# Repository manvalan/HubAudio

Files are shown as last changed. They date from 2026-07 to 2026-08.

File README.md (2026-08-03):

# HubAudio

## Professional Embedded Audio Platform

HubAudio is a modular embedded audio platform designed around a clear separation of hardware domains:

- System control
- Audio processing
- Digital radio
- Wireless audio
- Clock management
- Power management

The primary design objective is maintainability.

The architecture follows the principle:

> Code and hardware design must fit in the engineer's head.

Complexity is introduced only when it provides a measurable improvement in reliability, flexibility or performance.

---

# Project Goals

HubAudio is intended to provide:

- High quality digital audio routing
- Multiple audio sources and destinations
- Expandable DSP processing
- Robust embedded operation
- Professional PCB architecture
- Long-term maintainability

---

# Core Architecture

## Main Domains

                SYSTEM DOMAIN

                ESP32-S3
                   |
          Control / Network / UI
                   |
                   |
            AUDIO CONTROL BUS

                AUDIO DOMAIN

               ADAU1467

    +-------------+-------------+
    |             |             |
  I2S          SPDIF        Bluetooth
    |             |             |
Si4684        IO Codec      BT Module
 Radio

---

# Hardware Philosophy

The system is divided into independent domains:

## System Domain

Responsible for:

- Connectivity
- User interface
- Configuration
- Network services
- OTA updates

Main component:

- ESP32-S3

## Audio Domain

Responsible for:

- Routing
- DSP processing
- Mixing
- Sample rate management

Main component:

- Analog Devices ADAU1467

## RF Domain

Responsible for:

- Digital radio reception
- Wireless communication

## Power Domain

Responsible for:

- Battery operation
- USB power
- Voltage regulation
- Monitoring

---

# Repository Structure

HubAudio/

├── docs/
│
├── hardware/
│
├── firmware/
│
├── simulation/
│
├── research/
│
└── tools/

---

# Design Rules

1. Prefer simple architectures.
2. Avoid unnecessary abstraction.
3. Separate noisy and sensitive domains.
4. Document every architectural decision.
5. Choose components for lifecycle, not only price.

---

# Status

Architecture phase.

Hardware implementation follows documented decisions.

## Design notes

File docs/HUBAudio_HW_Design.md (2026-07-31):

# HubAudio
## Modular Network Audio Platform
### Hardware Architecture and Engineering Design Document

**Project:** HubAudio  
**Document:** Hardware Architecture Specification  
**Revision:** 0.1  
**Status:** Design Phase  
**Target MCU:** ESP32-S3  
**Architecture:** Modular Audio Processing Platform  

---

# 1. Introduction

HubAudio is a modular high-quality network audio platform designed around a central DSP audio architecture.

The goal is not to create a simple Internet radio, but a flexible audio processing system capable of integrating multiple digital audio sources:

- FM radio
- DAB/DAB+ radio
- Bluetooth audio
- Network streaming
- Future digital sources

All audio sources are converted into a common digital audio stream and processed by a dedicated DSP before being sent to the final audio output stage.

The core design philosophy is:

> Keep the audio path fully digital until the final DAC stage.

The system is designed as a professional embedded audio platform, with concepts derived from industrial and commercial audio products:

- modular hardware blocks
- independent firmware management
- device identification
- firmware update capability
- replaceable source modules
- DSP-based audio processing

---

# 2. Design Goals

## Primary objectives

The HubAudio platform shall provide:

- High quality audio processing
- Multiple independent audio sources
- Network connectivity
- Bluetooth integration
- Digital signal processing
- Expandability
- Long-term maintainability

## Audio sources

The initial supported sources are:

| Source | Device |
|-|-|
| FM/DAB+ Radio | Skyworks Si4684 |
| Bluetooth TX | FSC-BT1035 |
| Bluetooth RX | FSC-BT1026 or equivalent |
| Network Audio | ESP32-S3 |

---

# 3. System Overview

The system is composed of four main functional blocks:

                     HUBAUDIO

                     ESP32-S3
                        |
         System control / Network / MQTT
                        |
    +-------------------+-------------------+
    |                   |                   |
    |                   |                   |
 Si4684             BT RX Module        BT1035
FM/DAB+             A2DP Sink           A2DP Source
    |                   |                   |
    |                   |                   |
    +-------------------+-------------------+

                        |
                       I2S

                        |
                        |
                  ADAU1467 DSP

                        |
                        |
                     DAC Stage

                        |
                        |
                Power Amplifier

---

# 4. System Philosophy

## Modular approach

Each functional block is considered an independent subsystem.

Modules:
+-----------------------------+
| Audio Module |
| |
| Processing IC |
| EEPROM Identification |
| Firmware Storage |
| Local configuration |
| I2S Interface |
| Control Interface |
+-----------------------------+

Every module shall contain:

- hardware identification
- revision information
- serial number
- configuration data

The identification device is:

24AA025E48T-I/OT

which provides:

- EEPROM memory
- factory programmed MAC address
- unique identification

---

# 5. Global Architecture

## Control domain

The ESP32-S3 is the system controller.

Responsibilities:

- WiFi connection
- MQTT communication
- Web interface
- OTA updates
- module discovery
- configuration management
- power sequencing

The ESP32-S3 does NOT process the main audio stream.

Audio remains outside the MCU.

---

## Audio domain

The audio domain is controlled by:

ADAU1467

The DSP is the central audio router.

Responsibilities:

- equalization
- filters
- crossover
- volume control
- loudness
- audio routing
- room correction

---

# 6. Audio Data Flow

## Bluetooth reception

Example:

Smartphone

|

Bluetooth A2DP

|

BT RX Module

|

I2S

|

ADAU1467

|

DAC

|

Amplifier

---

## Bluetooth transmission

Example:

Radio / Streaming

   |

ADAU1467

   |

  I2S

   |

BT1035

   |

Bluetooth TX

   |

Headphones

---

## Radio reception

Antenna

|

Si4684

|

I2S

|

ADAU1467

|

DAC

---

# 7. Power Architecture

The system shall use separated power domains.

Recommended domains:

VIN

|

+----------------+
|
+-- Digital 3.3V
|
| ESP32-S3
| EEPROM
| Control IC
|
|
+-- Audio 3.3V
|
| ADAU1467
| Audio modules
|
|
+-- RF supply
Si4684
Bluetooth modules

Important:

RF and audio domains must be isolated from noisy digital switching sources.

---

# 8. Firmware Storage Concept

The system supports independent firmware storage.

Example:

ESP32 Flash

|
|
+-- HubAudio Firmware

SPI Flash

|
|
+-- Si4684 firmware

SPI Flash

|
|
+-- ADAU1467 DSP program

The ESP32-S3 manages:

- firmware verification
- checksum
- update
- programming sequence

---

# 9. Update Procedure

Firmware update sequence:

ESP32 receives firmware
Disable audio modules
Power down Si4684 / ADAU1467
Program external memory
Verify checksum
Restart module
Resume operation

This avoids requiring direct programming access during normal operation.

---

# 10. Hardware Design Rules

## Clocking

I2S requires careful definition:

Possible configurations:

### Option A

ADAU1467 as I2S master.

Advantages:

- single audio clock source
- better synchronization

### Option B

Source modules as masters.

Requires:

- clock switching
- sample rate management

Preferred:

ADAU1467 master.

---

# 11. Open Engineering Points

The following points require verification during schematic phase:

## I2S topology

Need to verify:

- master/slave capability of each module
- supported sample rates
- MCLK requirement

## Bluetooth Gateway Function

The system intentionally separates:

- Bluetooth RX
- Bluetooth TX

because simultaneous A2DP RX/TX operation on a single Bluetooth module is not guaranteed.

The chosen architecture is:

BT RX Module

BT1035 TX Module

ADAU1467 routing

This provides reliable simultaneous operation.

---
# 12. ESP32-S3 System Controller

## 12.1 Overview

The ESP32-S3 is the main system controller of HubAudio.

It is responsible for:

- system initialization
- network communication
- MQTT management
- Web interface
- OTA firmware updates
- module identification
- power management
- configuration storage
- communication with audio peripherals

The ESP32-S3 is NOT part of the main audio signal chain.

The audio stream shall never pass through the MCU.

---

# 12.2 ESP32-S3 Main Interfaces

The ESP32-S3 communicates with the audio modules using:

| Function | Interface |
|-|-|
| Si4684 control | SPI |
| ADAU1467 control | I2C/SPI |
| Bluetooth modules | UART |
| EEPROM identification | I2C |
| Audio control | GPIO |
| Power management | GPIO |

---

# 12.3 Recommended ESP32-S3 Connections

## Power Supply

ESP32-S3 requires:

- 3.3V regulated supply
- low noise supply
- adequate decoupling close to pins

Recommended:

3.3V

|
+---- 10uF
|
+---- 100nF
|
ESP32-S3 VDD

Important:

The ESP32-S3 has high current peaks during WiFi transmission.

The regulator must support:

- >500mA transient capability
- low output impedance

Recommended regulators:

- TPS62162
- AP63203
- similar low noise buck converters

---

# 12.4 Important GPIO Considerations

ESP32-S3 pins have boot functions.

Avoid using boot-sensitive pins for critical peripherals.

Important signals:

## EN

Chip enable:

EN

HIGH = normal operation
LOW = reset

Recommended:

- RC reset network
- external supervisor optional

---

## UART

Recommended:

ESP32-S3 TX
|
|
Module RX

ESP32-S3 RX
|
|
Module TX

Used for:

- Bluetooth configuration
- module diagnostics

---

## I2C Bus

Shared bus:

ESP32-S3

SDA
|
+---- 24AA025E48
|
+---- ADAU1467
|
+---- sensors / expansion

SCL
|
+---- devices

Recommended pull-ups:

Typically:

2.2k - 4.7k

depending on bus length.

---

# 12.5 ESP32-S3 Firmware Architecture

Software layers:

Application

|
|
HubAudio Manager

|
+----------------+
| |
Drivers Network

|
Hardware abstraction

|
ESP32 HAL

The MCU shall manage modules as independent devices.

Example:

detect modules

read EEPROM

load configuration

initialize devices

start audio routing

---

# 13. Skyworks Si4684 Radio Module

## 13.1 Overview

The Si4684 is the selected radio receiver IC.

Functions:

- FM receiver
- AM receiver
- DAB/DAB+
- RDS/RBDS
- digital audio output

The device is selected because it integrates:

- RF receiver
- digital demodulation
- audio processing
- DAB stack

The Si4684 is treated as a complete radio subsystem.

---

# 13.2 Si4684 System Architecture

Antenna

|

RF Matching

|

Si4684

|

Digital Audio I2S

|

ADAU1467

---

# 13.3 Si4684 Control Interface

The preferred interface:

SPI

Connections:

ESP32-S3 Si4684

SPI CLK -----------> SCLK

SPI MOSI ----------> SDIO

SPI CS ------------> CS

GPIO --------------> RESET

GPIO <-------------- IRQ

---

# 13.4 Important Si4684 Pins

## VDD

Requirements:

- clean 3.3V supply
- RF filtering required

Recommended:

3.3V

|
Ferrite bead

|

Si4684 VDD

|
100nF
1uF
10uF

The RF section is sensitive to noise.

---

## RESET

Active low.

Recommended:

ESP GPIO

|

RESET

|

10k pull-up

|

3.3V

The MCU must control reset during startup.

---

## IRQ

Interrupt output.

Used for:

- data ready
- command completion
- events

Connection:

Si4684 IRQ

|

ESP32 GPIO interrupt

---

# 13.5 Si4684 Audio Interface

Digital output:

Si4684

BCLK
|
LRCLK
|
DATA

|

ADAU1467

Preferred:

- 24 bit audio
- 48kHz sample rate

---

# 13.6 Si4684 Firmware Management

Important design issue:

The Si4684 requires firmware loading.

The architecture includes:

SPI Flash

|

Si4684 firmware

|

ESP32-S3 loader

Startup sequence:

Power ON

|

ESP32 starts

|

Keep Si4684 reset

|

Load firmware

|

Release RESET

|

Initialize radio

---

# 13.7 Si4684 PCB Recommendations

RF section:

Must be physically separated from:

- DC/DC converters
- digital switching
- WiFi antenna

Recommended PCB placement:

+--------------------------+

RF AREA

Antenna
Matching
Si4684

DIGITAL AREA

ESP32
DSP
Power

+--------------------------+

---

# 13.8 Si4684 Design Risks

## Firmware availability

The firmware is proprietary.

The project must consider:

- legal firmware distribution
- firmware update method
- version control

The binary firmware shall be stored separately from source code.

---

## RF layout

The PCB RF layout is critical.

Must follow:

- antenna impedance rules
- controlled impedance traces
- ground plane continuity

---

# 13.9 Si4684 Summary

Role:

FM/DAB radio source.

Interface:

SPI + I2S.

Connection:

ESP32-S3

SPI

Si4684

I2S

ADAU1467

The Si4684 is considered a replaceable radio module.

(Fine Parte 2)

---

# 14. Analog Devices ADAU1467 Audio DSP

## 14.1 Overview

The ADAU1467 is the central digital audio processing unit of HubAudio.

It belongs to the Analog Devices SigmaDSP family and is designed for high quality audio processing applications.

The DSP is responsible for:

- audio routing
- equalization
- crossover filtering
- dynamic processing
- loudness compensation
- volume control
- delay management
- room correction algorithms

The ADAU1467 represents the central audio processing hub.

---

# 14.2 Audio Architecture

All digital audio sources converge into the ADAU1467.

                 AUDIO SOURCES

     Si4684          BT RX          Network Audio

        |              |                  |

        |              |                  |

        +--------------+------------------+

                       |

                      I2S

                       |

                  ADAU1467 DSP

                       |

          +------------+------------+

          |                         |

        DAC                    BT1035 TX

          |

     Power Amplifier

14.3 Why Use a Dedicated DSP

The ESP32-S3 is not suitable for high quality audio processing.

Reasons:

operating system tasks
WiFi interruptions
unpredictable timing
insufficient deterministic audio processing

The ADAU1467 provides:

deterministic processing
hardware audio engine
low latency
professional audio quality
14.4 ADAU1467 Main Interfaces

The DSP uses:

Function	Interface
Configuration	I2C / SPI
Program loading	SPI Flash
Audio input/output	I2S/TDM
Clock	MCLK
Reset	GPIO
14.5 ADAU1467 Power Supply

The ADAU1467 contains sensitive analog/digital sections.

Power domains must be carefully designed.

Recommended:

3.3V_AUDIO

       |

       +---- DSP Digital Supply

       |

       +---- DSP Analog Supply

Important:

The DSP supply must be separated from:

ESP32 WiFi supply
DC/DC switching nodes
Bluetooth RF supply
14.6 Decoupling Requirements

Standard decoupling:

VDD

 |

100nF ceramic

 |

1uF ceramic

 |

10uF bulk

Additional filtering is recommended:

3.3V

 |

Ferrite bead

 |

ADAU1467 supply

The ferrite bead is particularly important because DSP noise can couple into the audio path.

14.7 ADAU1467 Configuration Interface

The ESP32-S3 controls the DSP.

Preferred:

I2C Control

Connection:

ESP32-S3             ADAU1467

SDA ---------------- SDA

SCL ---------------- SCL

Used for:

volume
routing
parameter updates
runtime control
14.8 DSP Program Memory

The ADAU1467 does not permanently store the DSP program internally.

External SPI memory is required.

Architecture:

ESP32-S3

    |

    |

SPI Flash

    |

    |

ADAU1467

Startup sequence:

Power ON

 |

ESP32 starts

 |

Program ADAU1467 memory

 |

Verify checksum

 |

Enable audio processing

14.9 SPI Flash Programming Strategy

The ESP32-S3 shall be able to:

erase DSP memory
program new firmware
verify CRC
restore previous version

Possible update procedure:

Receive DSP image

        |

Disable ADAU1467

        |

Program SPI Flash

        |

Verify

        |

Restart DSP

This allows field firmware updates.

14.10 Audio Interface (I2S)

The ADAU1467 is the preferred audio clock master.

Recommended architecture:

                ADAU1467

                    |

          BCLK / LRCLK / MCLK

                    |

        +-----------+-----------+

        |                       |

     Si4684                 BT Modules

Advantages:

single clock domain
no asynchronous sample conversion
better audio stability
14.11 I2S Signals

Typical signals:

BCLK

Bit clock.

Carries the individual audio bits.

LRCLK

Word select clock.

Defines:

left channel
right channel
DATA

Serial audio data.

MCLK

Master clock.

Important:

Some audio devices require MCLK.

Others generate internal clocks.

Each module must be verified.

14.12 I2S Routing Problems

A critical design issue:

Multiple I2S sources cannot directly drive the same bus.

Wrong:

Si4684

     |

     +------------ I2S ------------ ADAU1467

BT RX

     |

     +------------ I2S ------------

Two masters conflict.

Correct:

Source modules

      |

      |

Dedicated inputs

      |

      |

ADAU1467

The ADAU1467 must provide multiple serial ports.

14.13 ADAU1467 Audio Ports

The DSP provides multiple serial interfaces.

Suggested allocation:

Port	Device
Serial Input 0	Si4684
Serial Input 1	BT RX
Serial Output 0	DAC
Serial Output 1	BT1035

This avoids external I2S multiplexers.

14.14 DSP Software

The SigmaDSP project shall contain:

routing matrix
equalizer
volume control
filters
crossover
protection algorithms

Example:

Input Selector

       |

Equalizer

       |

Dynamic Processing

       |

Volume

       |

Output Router

14.15 ADAU1467 Reset

Reset must be controlled.

Recommended:

ESP32 GPIO

      |

RESET

      |

10k Pull-up

      |

3.3V

Startup:

Hold RESET LOW

       |

Configure clocks

       |

Release RESET

       |

Load DSP program

14.16 ADAU1467 PCB Placement

The DSP should be placed:

close to audio connectors
away from ESP32 antenna
away from DC/DC converters

Recommended:

+-----------------------------+

RF AREA

Bluetooth
Si4684

-----------------------------

AUDIO AREA

ADAU1467
DAC

-----------------------------

DIGITAL AREA

ESP32-S3
Power

+-----------------------------+

14.17 ADAU1467 Design Risks
Clock synchronization

Must verify:

MCLK requirement
sample frequency compatibility
master/slave configuration
Firmware dependency

DSP algorithm is stored externally.

Need:

version management
backup image
checksum
Noise coupling

Avoid:

digital return currents through analog ground
switching regulator near DSP
long I2S traces
14.18 ADAU1467 Summary

Role:

Central audio processing engine.

Connections:

ESP32-S3

  |

I2C/SPI

  |

ADAU1467

  |

I2S/TDM

  |

Audio modules

The ADAU1467 defines the professional audio capability of HubAudio.

---

# 15. Bluetooth Audio Subsystem

## 15.1 Architecture Decision

The HubAudio platform intentionally separates Bluetooth reception and transmission.

The reason is reliability.

A single Bluetooth audio module capable of simultaneously handling:

- A2DP Sink
- A2DP Source
- independent Bluetooth links
- real-time audio routing

is not guaranteed in commercial modules.

Therefore the design uses two independent Bluetooth audio blocks.

Architecture:

             Bluetooth Subsystem

    Smartphone                 Headphones

         |                         ^

         |                         |

         v                         |

   BT RX MODULE              BT1035 TX

         |                         ^

         | I2S                     | I2S

         |                         |

         +-----------+-------------+

                     |

                  ADAU1467

Advantages:

- simultaneous operation
- independent firmware
- easier debugging
- modular replacement
- predictable audio routing

---

# 16. FSC-BT1035 Bluetooth Transmitter

## 16.1 Role in HubAudio

The FSC-BT1035 is used as Bluetooth Audio Transmitter.

Its function:

ADAU1467

|

I2S

|

FSC-BT1035

|

Bluetooth A2DP Source

|

Headphones / Speakers

---

# 16.2 Main Features

Typical capabilities:

- Bluetooth audio transmission
- A2DP Source
- AVRCP support
- digital audio interface
- UART configuration
- embedded antenna

The module handles:

- Bluetooth stack
- codec negotiation
- RF management

The ESP32-S3 does not process Bluetooth audio.

---

# 16.3 BT1035 Connections

Important signals:

## Power

3.3V

|

BT1035 VCC

The module requires:

- clean supply
- local decoupling
- RF isolation

Recommended:

3.3V

|

Ferrite bead

|

BT1035

|

100nF

|

10uF

---

## UART Control

Connection:

ESP32-S3 BT1035

TX ---------------- RX

RX ---------------- TX

Used for:

- configuration
- status
- debugging

---

## I2S Audio Input

The BT1035 receives digital audio from the DSP.

ADAU1467 BT1035

BCLK -------------- BCLK

LRCLK ------------- LRCLK

DATA -------------- DATA IN

Important:

The clock master/slave configuration must be verified.

Preferred:

ADAU1467 = clock master.

---

# 16.4 BT1035 Firmware Considerations

Commercial Bluetooth modules often contain vendor firmware.

Important:

Verify:

- A2DP Source enabled
- I2S input mode enabled
- codec selection
- sample rate support

The module configuration shall be stored separately from ESP32 firmware.

---

# 16.5 BT1035 Operating Modes

Normal operation:

Power ON

|

UART initialization

|

Configure audio interface

|

Start Bluetooth advertising

|

Connect headphones

|

Stream audio

---

# 17. Bluetooth RX Module

## 17.1 Requirements

The receiving module must provide:

Required:

- Bluetooth Classic
- A2DP Sink
- I2S output
- UART configuration

Optional:

- AVRCP
- BLE
- codec selection

---

# 17.2 Preferred Solution

A module based on:

- FSC-BT1026
- equivalent Bluetooth Audio Receiver

Architecture:

Smartphone

|

Bluetooth A2DP

|

BT RX Module

|

I2S

|

ADAU1467

---

# 17.3 BT RX Module Connections

## Power

Same philosophy:

3.3V

|

Filtering

|

BT RX Module

Bluetooth RF requires a clean supply.

---

## I2S Output

Connection:

BT RX ADAU1467

BCLK -----------> BCLK IN

LRCLK ----------> LRCLK IN

DATA -----------> DATA IN

---

## UART

Optional but recommended:

ESP32-S3 TX

 |

BT RX RX

ESP32-S3 RX

 |

BT RX TX

Used for:

- pairing control
- diagnostics
- configuration

---

# 17.4 Bluetooth RX Firmware Risks

The main risk is vendor configuration.

A module may support:

- A2DP Sink only

or:

- A2DP Sink + Source

The required mode must be confirmed before PCB release.

---

# 18. Alternative Bluetooth RX Using ESP32-WROOM-32

## 18.1 Overview

The ESP32-WROOM-32 contains Bluetooth Classic support.

Unlike ESP32-S3:

- Bluetooth Classic available
- A2DP Sink supported

Architecture:

Smartphone

|

Bluetooth A2DP

|

ESP32-WROOM-32

|

I2S

|

ADAU1467

---

# 18.2 Advantages

Advantages:

- complete firmware control
- open development environment
- easy debugging
- same ecosystem as ESP32-S3

---

# 18.3 Disadvantages

Compared with dedicated modules:

- more firmware work
- Bluetooth stack maintenance
- higher CPU load
- more software complexity

---

# 18.4 Recommended Use

ESP32-WROOM should be considered:

- development prototype
- experimental firmware
- future custom Bluetooth module

Not the first production choice.

---

# 19. Bluetooth Clock Management

Bluetooth audio introduces clock problems.

Different devices may have:

- different sample clocks
- different oscillator accuracy

The ADAU1467 should manage:

- routing
- resampling if required
- synchronization

Possible solutions:

## Solution A

All sources synchronized to DSP clock.

Preferred.

---

## Solution B

Asynchronous sample rate conversion.

Required if modules cannot operate as slaves.

---

# 20. Bluetooth PCB Layout

RF modules require:

- antenna clearance
- ground plane
- no copper under antenna area
- separation from switching regulators

Recommended:

+--------------------+

Bluetooth Antenna

 KEEP OUT AREA

Digital electronics

Power section

+--------------------+

---

# 21. Bluetooth Subsystem Summary

Final architecture:

             ESP32-S3

                |

      +---------+---------+

      |                   |

   BT RX              BT1035

 A2DP Sink          A2DP Source

      |                   |

      | I2S               | I2S

      +---------+---------+

                |

            ADAU1467

This provides:

- smartphone audio reception
- Bluetooth headphone transmission
- simultaneous operation
- modular replacement

---
# 22. Module Identification System

## 22.1 Purpose

HubAudio is designed as a modular platform.

Every external module must be automatically identifiable by the main controller.

The system uses:

24AA025E48T-I/OT

as module identification memory.

---

# 22.2 24AA025E48T Overview

The device provides:

- I2C EEPROM memory
- factory programmed unique MAC address
- unique module identification

The ESP32-S3 reads the EEPROM during startup.

---

# 22.3 EEPROM Connection

Typical connection:

ESP32-S3 24AA025E48T

3.3V ---------------- VCC

GND ----------------- GND

SDA ----------------- SDA

SCL ----------------- SCL

Required:

I2C pull-up resistors.

Typical value:

2.2k - 4.7k

depending on bus capacitance.

---

# 22.4 Module Identification Structure

Example:

EEPROM:

Address 00

Module Type

01 = Radio Si4684

02 = Bluetooth RX

03 = Bluetooth TX

04 = DSP

Address 10

Hardware Revision

Address 20

Serial Number

Address 30

Configuration Data

---

# 22.5 Startup Discovery

The ESP32-S3 performs:

Power ON

|

Initialize I2C

|

Scan module bus

|

Read EEPROM

|

Identify hardware

|

Load configuration

|

Initialize drivers

The firmware does not need to know the exact board revision.

---

# 23. External SPI Memories

## 23.1 Purpose

Several components require external firmware storage.

Examples:

- ADAU1467 DSP program
- Si4684 firmware
- future modules

---

# 23.2 General Architecture

ESP32-S3

|

SPI

|

External Flash

|

Target Device

The ESP32-S3 acts as programmer.

---

# 23.3 Firmware Update Procedure

General sequence:

Receive update package

    |

Validate checksum

    |

Disable target device

    |

Program Flash

    |

Verify

    |

Restart module

---

# 24. Power Architecture

## 24.1 Design Objective

The audio system contains:

- RF circuits
- digital processors
- sensitive analog sections

Power distribution is critical.

---

# 24.2 Recommended Power Domains

Main Input

  |

  +----------------+

  |

Digital 3.3V

  |

  + ESP32-S3

  + EEPROM

  |

  |

Audio 3.3V

  |

  + ADAU1467

  + DAC

  |

  |

RF 3.3V

  |

  + Si4684

  + Bluetooth

---

# 24.3 Separation Rules

Avoid:

- ESP32 WiFi current peaks disturbing audio
- DC/DC switching noise entering DSP supply
- RF noise coupling into analog paths

---

# 24.4 Recommended Filtering

For DSP:

3.3V

|

Ferrite bead

|

100nF

|

1uF

|

10uF

|

ADAU1467

For RF modules:

3.3V

|

Ferrite bead

|

RF module

---

# 24.5 Ground Strategy

Recommended:

Single PCB ground plane.

However:

Control return currents carefully.

Avoid:

- digital currents crossing analog audio paths
- switching regulator return under DSP

---

# 25. System Boot Sequence

Complete startup:

POWER ON

|

Power regulators stable

|

ESP32-S3 reset release

|

Read EEPROM modules

|

Keep audio devices disabled

|

Initialize Si4684

|

Initialize ADAU1467

|

Initialize Bluetooth modules

|

Configure audio routing

|

Enable audio outputs

---

# 26. Audio Routing Software Model

The firmware shall expose audio sources:

Example:

SOURCE_RADIO

SOURCE_BT_RX

SOURCE_NETWORK

SOURCE_EXTERNAL

The DSP routing layer decides:

Selected Source

   |

ADAU1467

   |

Outputs

---

# 27. PCB Placement Strategy

Recommended board organization:

+--------------------------------+

| |
| RF AREA |
| |
| Si4684 Bluetooth Modules |
| |

AUDIO AREA

ADAU1467 DAC

-------------------------------

DIGITAL AREA

ESP32-S3 Power

+--------------------------------+

---

# 28. PCB Critical Rules

## RF

Must verify:

- antenna clearance
- impedance control
- keep-out area
- connector placement

---

## I2S

Keep:

- short traces
- controlled routing
- common ground reference

Avoid:

- crossing noisy clocks

---

## SPI

For:

- Si4684
- firmware memories

Use:

- short traces
- avoid unnecessary vias

---

# 29. Initial Bill Of Materials (Architecture Level)

| Block | Component |
|-|-|
| Main MCU | ESP32-S3 |
| Radio | Si4684 |
| DSP | ADAU1467 |
| Bluetooth TX | FSC-BT1035 |
| Bluetooth RX | FSC-BT1026 or equivalent |
| Module ID | 24AA025E48T-I/OT |
| DSP memory | SPI Flash |
| Radio memory | SPI Flash |
| DAC | To be selected |
| Amplifier | To be selected |

---

# 30. Open Issues Before PCB Release

## Must verify

### ADAU1467

- exact DSP memory size
- SPI Flash type
- clock configuration
- serial port allocation

---

### Si4684

- firmware acquisition
- RF matching network
- antenna design

---

### Bluetooth

- BT1035 I2S mode
- BT RX module A2DP Sink capability
- codec support
- UART commands

---

### Power

- regulator selection
- current budget
- thermal analysis

---

# 31. Final Architecture

The final HubAudio platform:

                     ESP32-S3

                        |

    +-------------------+-------------------+

    |                   |                   |

  Si4684             BT RX              BT1035

 FM/DAB+           A2DP Sink          A2DP Source

    |                   |                   |

    +-------------------+-------------------+

                        |

                       I2S

                        |

                   ADAU1467

                        |

             +----------+----------+

             |                     |

            DAC              Bluetooth Output

             |

        Amplifier

---

# 32. Engineering Philosophy

HubAudio is designed as a scalable embedded audio platform.

The architecture follows these principles:

- digital audio path
- modular hardware
- replaceable subsystems
- independent firmware management
- explicit hardware identification
- professional DSP processing

The system can evolve without redesigning the complete platform.

---

# END OF DOCUMENT

Revision 0.1

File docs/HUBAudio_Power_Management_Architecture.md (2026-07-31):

# HubAudio
# Power Management Architecture

**Document:** Power Management Design Specification  
**Revision:** 0.1  
**Status:** Design Phase  

---

# 1. Overview

The HubAudio platform requires a sophisticated power management architecture.

The system combines:

- ESP32-S3 high performance MCU with WiFi
- ADAU1467 professional audio DSP
- Si4684 FM/DAB receiver
- Bluetooth audio transmitter
- Bluetooth audio receiver
- battery operation
- remote monitoring capability

The power system is therefore not considered a simple voltage regulator stage, but a complete energy management subsystem.

---

# 2. Design Philosophy

The selected architecture follows these principles:

- single intelligent PMIC
- integrated battery management
- multiple independent power rails
- I2C monitoring
- controlled power sequencing
- ability to disable unused subsystems
- separated digital and audio power domains

---

# 3. Selected Main PMIC

## Texas Instruments TPS65217CRSLR

The TPS65217 is selected as the main power management IC.

Reasons for selection:

- integrated Li-Ion battery charger
- power path management
- multiple switching regulators
- LDO outputs
- I2C configuration
- programmable sequencing
- fault monitoring

Although originally designed for embedded processor systems, its architecture is suitable for HubAudio due to the need for multiple controlled power domains.

---

# 4. Power Tree

Proposed architecture:

             USB-C / External Power

                     |

                     |

             TPS65217CRSLR

                     |

    +----------------+----------------+

    |                |                |

 DCDC1             DCDC2            DCDC3

    |                |                |

3.3V_DIGITAL 3.3V_AUDIO 5V

    |                |

    |                |

ESP32-S3 Audio/RF domain

                |

          Ferrite filtering

                |

    +-----------+-----------+

    |           |           |

ADAU1467    Si4684      Bluetooth

---

# 5. Power Domains

## 5.1 Digital Domain

Voltage:

3.3V_DIGITAL

Consumers:

- ESP32-S3
- EEPROM
- logic peripherals
- communication interfaces

Requirements:

- high transient capability
- low impedance supply

Main concern:

ESP32-S3 WiFi current peaks.

---

# 5.2 Audio / RF Domain

Voltage:

3.3V_AUDIO

Consumers:

- ADAU1467
- Si4684
- BT1035
- Bluetooth RX module

This rail must be isolated from digital noise.

Recommended:

3.3V_AUDIO

  |

ferrite bead

  |

audio devices

---

# 5.3 5V Domain

Possible consumers:

- DAC
- amplifier
- future peripherals

This rail is kept independent from sensitive audio electronics.

---

# 6. Battery Management

The TPS65217 provides:

- Li-Ion charging
- battery monitoring
- power path control
- protection mechanisms

Battery:

Single cell Li-Ion

3.7V nominal

4.2V charged

---

# 7. Power Monitoring

## 7.1 Decision

The TPS65217 already provides battery management.

An additional current monitor is not required for system operation.

However, HubAudio benefits from detailed subsystem monitoring.

A dedicated I2C power monitor is therefore added for the audio domain.

---

# 8. Selected Current Monitor

## Texas Instruments INA226

The INA226 is selected as the default power monitoring device.

Purpose:

Measure the audio subsystem consumption.

Monitored rail:

TPS65217

|

3.3V_AUDIO

|

INA226

|

ADAU1467
Si4684
Bluetooth

---

# 9. INA226 Functions

The INA226 provides:

- bus voltage measurement
- shunt voltage measurement
- current measurement
- power calculation
- I2C communication

The ESP32-S3 can periodically read:

Voltage

Current

Power

Example:

```json
{
 "audio_voltage":3.30,
 "audio_current":180,
 "audio_power":0.59
}

10. INA228 Evaluation

The INA228 has been evaluated as an alternative.

Advantages:

higher resolution ADC
higher precision
energy accumulation
advanced power analysis

Typical application:

laboratory measurements
industrial systems
precision battery analysis

For HubAudio:

Not selected as default.

Reason:

The additional precision is not necessary because:

battery management is already handled by TPS65217
audio subsystem consumption does not require laboratory accuracy
11. Future Compatibility

The PCB should allow optional replacement:

INA226 footprint compatible with INA228 evaluation.

Possible versions:

Standard
TPS65217
+
INA226

Engineering / Pro Version
TPS65217
+
INA228

12. I2C Monitoring Bus

The power monitoring devices share the system I2C bus.

Example:

ESP32-S3

 |

I2C

 +---- EEPROM

 |

 +---- ADAU1467

 |

 +---- INA226

 |

 +---- TPS65217

13. Power Sequencing

Startup sequence:

Battery connected

 |

TPS65217 initialization

 |

3.3V_DIGITAL enabled

 |

ESP32-S3 boot

 |

Module detection

 |

Enable audio domain

 |

Initialize DSP

 |

Enable RF modules

14. Controlled Shutdown

The ESP32-S3 can disable:

Bluetooth TX
Bluetooth RX
Si4684
ADAU1467

Example:

Standby:

ESP32-S3 ON

WiFi ON

Audio OFF

Radio OFF

Bluetooth OFF

15. PCB Layout Requirements

Critical:

Switching regulators

Keep away from:

ADAU1467
DAC
RF sections
Audio supply

Use:

short traces
filtering
dedicated return paths
Decoupling

Every IC requires local decoupling.

Additional filtering is required for:

DSP supply
RF supply
16. Final Decision

The HubAudio power architecture is:

TPS65217CRSLR

+

Separate audio power domain

+

INA226 monitoring

+

Optional INA228 upgrade

This provides:

professional power management
battery operation
remote diagnostics
future scalability
END DOCUMENT

---

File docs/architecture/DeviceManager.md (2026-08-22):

# HubAudio — MCP23S17 GPIO Distribution

**Progetto:** HubAudio  
**Revisione:** definitiva  
**Data:** 2026-08-22

---

## Distribuzione GPIO

| IC | PORTA | GPIO | Segnale | Direzione | Pull |
|---|---|---|---|---|---|
| U34 | A | GPA0 | `SI4684_RESET` | OUT | UP |
| U34 | A | GPA1 | `SI4684_SMODE` | OUT | - |
| U34 | A | GPA2 | `SI4684_ANT_SEL` | OUT | - |
| U34 | A | GPA3 | `SI4684_INT` | IN | - |
| U34 | A | GPA4 | `ADAU1467_RESET` | OUT | UP |
| U34 | A | GPA5 | `ADAU1467_SELFBOOT` | OUT/STRAP | UP |
| U34 | A | GPA6 | `RESERVED` | — | - |
| U34 | A | GPA7 | `MIC_SOURCE_SELECT` | OUT | - |
| U34 | B | GPB0 | `MIC_DETECT` | IN | UP |
| U34 | B | GPB1 | `LINE_IN_DETECT` | IN | UP |
| U34 | B | GPB2 | `LINE_OUT_DETECT` | IN | UP |
| U34 | B | GPB3 | `JACK_DETECT` | IN | UP |
| U34 | B | GPB4 | `BQ25896_INT` | IN | UP |
| U34 | B | GPB5 | `BQ25896_PG#` | IN | UP |
| U34 | B | GPB6 | `BQ27441_GPOUT` | IN | UP |
| U34 | B | GPB7 | `TPS63020_PG` | IN | UP |
| U36 | A | GPA0 | `BT1035_RESET` | OUT | - |
| U36 | A | GPA1 | `BT1035_SYSCTRL` | OUT | DOWN |
| U36 | A | GPA2 | `UART_RESET` | OUT | UP |
| U36 | A | GPA3 | `UART_INT` | IN | - |
| U36 | A | GPA4 | `ETH_RST#` | OUT | UP |
| U36 | A | GPA5 | `ANALOG_POWER_EN` | OUT | - |
| U36 | A | GPA6 | `ETHERNET_POWER_EN` | OUT | - |
| U36 | A | GPA7 | `BQ25896_PSEL` | OUT | - |
| U36 | B | GPB0 | `INA228_ANALOG_ALERT` | IN | UP |
| U36 | B | GPB1 | `INA228_DIGITAL_ALERT` | IN | UP |
| U36 | B | GPB2 | `TEMP_PWR_ALERT` | IN | UP |
| U36 | B | GPB3 | `TEMP_ESP32_ALERT` | IN | UP |
| U36 | B | GPB4 | `TEMP_ETH_ALERT` | IN | UP |
| U36 | B | GPB5 | `TEMP_CODEC_ALERT` | IN | UP |
| U36 | B | GPB6 | `RESERVED` | — | - |
| U36 | B | GPB7 | `RESERVED` | — | - |

---

# Pull-up / Pull-down

## Pull-UP

Le seguenti linee hanno pull-up esterno:

- `SI4684_RESET`
- `ADAU1467_RESET`
- `ADAU1467_SELFBOOT`
- `MIC_DETECT`
- `LINE_IN_DETECT`
- `LINE_OUT_DETECT`
- `JACK_DETECT`
- `BQ25896_INT`
- `BQ25896_PG#`
- `BQ27441_GPOUT`
- `TPS63020_PG`
- `UART_RESET`
- `ETH_RST#`
- `INA228_ANALOG_ALERT`
- `INA228_DIGITAL_ALERT`
- `TEMP_PWR_ALERT`
- `TEMP_ESP32_ALERT`
- `TEMP_ETH_ALERT`
- `TEMP_CODEC_ALERT`

Per le linee open-drain/status viene utilizzato come valore nominale:

**10 kΩ**

In particolare:

- `BQ27441_GPOUT` → 10 kΩ
- `TPS63020_PG` → 10 kΩ
- `INA228_ANALOG_ALERT` → 10 kΩ
- `INA228_DIGITAL_ALERT` → 10 kΩ
- `BQ25896_INT` → 10 kΩ
- `BQ25896_PG#` → 10 kΩ
- `TEMP_PWR_ALERT` → 10 kΩ
- `TEMP_ESP32_ALERT` → 10 kΩ
- `TEMP_ETH_ALERT` → 10 kΩ
- `TEMP_CODEC_ALERT` → 10 kΩ

## Pull-DOWN

- `BT1035_SYSCTRL` → **10 kΩ verso GND**

## Nessun pull esterno

- `SI4684_SMODE`
- `SI4684_ANT_SEL`
- `SI4684_INT`
- `MIC_SOURCE_SELECT`
- `BT1035_RESET`
- `UART_INT`
- `ANALOG_POWER_EN`
- `ETHERNET_POWER_EN`
- `BQ25896_PSEL`
- tutti i GPIO `RESERVED`

---

# Sensori di temperatura

Sono previsti sensori di temperatura **I²C** basati su **TMP117**.

I sensori sono distribuiti fisicamente sulla scheda per monitorare le zone termicamente più significative:

| Sensore | Zona | Posizione |
|---|---|---|
| `TEMP_PWR` | Dominio alimentazione | BOTTOM, vicino ai dispositivi di alimentazione |
| `TEMP_ESP32` | ESP32 | vicino all'ESP32 |
| `TEMP_ETH` | Ethernet / PHY | vicino al PHY Ethernet |
| `TEMP_CODEC` | Codec TAC5212 | vicino al codec |

I sensori condividono il bus I²C e vengono identificati tramite il relativo indirizzo `ADDR`.

Ogni sensore dispone di:

- alimentazione locale
- condensatore di bypass **100 nF**
- `SDA`
- `SCL`
- `ADDR`
- `ALERT`

### ALERT

L'uscita `ALERT` dei TMP117 viene utilizzata come segnalazione hardware verso il Device Manager:

- `TEMP_PWR_ALERT` → U36 GPB2
- `TEMP_ESP32_ALERT` → U36 GPB3
- `TEMP_ETH_ALERT` → U36 GPB4
- `TEMP_CODEC_ALERT` → U36 GPB5

Le linee `ALERT` sono ingressi del MCP23S17 e utilizzano un pull-up esterno da **10 kΩ**.

Il Device Manager può quindi ricevere immediatamente una segnalazione di superamento della soglia termica senza dover effettuare continuamente il polling dei sensori.

---

## Note sui dispositivi

### SI4684

`SI4684_RESET` è il reset active-low del dispositivo.

Il pull-up garantisce il rilascio del reset dopo la fase di power-up.

### ADAU1467

`ADAU1467_RESET` è active-low.

`ADAU1467_SELFBOOT` deve essere HIGH per il self-boot dalla EEPROM.

### TAC5212

Il codec `XTAC5212IRGER` è il **TAC5212**.

Non esiste un reset hardware dedicato da collegare al MCP23S17; il reset è gestito tramite la configurazione software del dispositivo.

**U34 GPA6 = RESERVED.**

### BT1035

`BT1035_RESET` non necessita di pull-up esterno perché il modulo dispone del proprio pull-up interno.

`BT1035_SYSCTRL` richiede invece il pull-down esterno.

### BQ27441

`GPOUT` è open-drain e il datasheet raccomanda esplicitamente una resistenza di pull-up da **10 kΩ**.

### TPS63020

`PG` è un'uscita **open-drain**. Il pull-up è quindi necessario quando il segnale viene utilizzato come ingresso digitale dal MCP23S17.

### INA228

`ALERT` è la linea di alert del monitor e viene utilizzata come ingresso verso il MCP23S17; è prevista con pull-up esterno.

### TMP117

Il TMP117 è utilizzato come sensore di temperatura locale.

La comunicazione avviene tramite I²C. Il pin `ALERT` viene utilizzato per generare una segnalazione hardware verso il Device Manager tramite U36.

Ogni sensore dispone di un proprio indirizzo I²C tramite il pin `ADDR`.

---

# Regola generale

Ogni net deve avere **una sola resistenza fisica di pull-up/pull-down**.

Se una net viene condivisa da più dispositivi, non devono essere installate resistenze duplicate sui vari dispositivi.

Il pull-up interno del MCP23S17 non viene utilizzato come sostituto dei pull-up esterni delle linee di stato/open-drain.

Per le linee `ALERT` dei TMP117 viene mantenuto il pull-up esterno da **10 kΩ**.

---

# Distribuzione funzionale

## U34 PORTA — Audio / Radio Control

| GPIO | Funzione |
|---|---|
| GPA0 | SI4684 RESET |
| GPA1 | SI4684 SMODE |
| GPA2 | SI4684 ANT SEL |
| GPA3 | SI4684 INT |
| GPA4 | ADAU1467 RESET |
| GPA5 | ADAU1467 SELFBOOT |
| GPA6 | RESERVED |
| GPA7 | MIC SOURCE SELECT |

## U34 PORTB — Detection / Power Status

| GPIO | Funzione |
|---|---|
| GPB0 | MIC DETECT |
| GPB1 | LINE IN DETECT |
| GPB2 | LINE OUT DETECT |
| GPB3 | JACK DETECT |
| GPB4 | BQ25896 INT |
| GPB5 | BQ25896 PG# |
| GPB6 | BQ27441 GPOUT |
| GPB7 | TPS63020 PG |

## U36 PORTA — BT / UART / Ethernet / Power

| GPIO | Funzione |
|---|---|
| GPA0 | BT1035 RESET |
| GPA1 | BT1035 SYSCTRL |
| GPA2 | UART RESET |
| GPA3 | UART INT |
| GPA4 | ETH RESET |
| GPA5 | ANALOG POWER EN |
| GPA6 | ETHERNET POWER EN |
| GPA7 | BQ25896 PSEL |

## U36 PORTB — Power / Temperature Monitoring

| GPIO | Funzione |
|---|---|
| GPB0 | INA228 ANALOG ALERT |
| GPB1 | INA228 DIGITAL ALERT |
| GPB2 | TEMP PWR ALERT |
| GPB3 | TEMP ESP32 ALERT |
| GPB4 | TEMP ETH ALERT |
| GPB5 | TEMP CODEC ALERT |
| GPB6 | RESERVED |
| GPB7 | RESERVED |

---

# Tabella resistenze da inserire nello schematico

| Net | Resistenza | Collegamento |
|---|---:|---|
| `SI4684_RESET` | 10 kΩ | VIO → RESET |
| `ADAU1467_RESET` | 10 kΩ | IOVDD → RESET |
| `ADAU1467_SELFBOOT` | 10 kΩ | IOVDD → SELFBOOT |
| `MIC_DETECT` | 10 kΩ | VIO → DETECT |
| `LINE_IN_DETECT` | 10 kΩ | VIO → DETECT |
| `LINE_OUT_DETECT` | 10 kΩ | VIO → DETECT |
| `JACK_DETECT` | 10 kΩ | VIO → DETECT |
| `BQ25896_INT` | 10 kΩ | VIO → INT |
| `BQ25896_PG#` | 10 kΩ | VIO → PG# |
| `BQ27441_GPOUT` | 10 kΩ | VDD → GPOUT |
| `TPS63020_PG` | 10 kΩ | VOUT/VIO → PG |
| `BT1035_SYSCTRL` | 10 kΩ | SYSCTRL → GND |
| `UART_RESET` | 10 kΩ | VIO → RESET |
| `ETH_RST#` | 10 kΩ | VIO → RESET# |
| `INA228_ANALOG_ALERT` | 10 kΩ | VIO → ALERT |
| `INA228_DIGITAL_ALERT` | 10 kΩ | VIO → ALERT |
| `TEMP_PWR_ALERT` | 10 kΩ | VIO → ALERT |
| `TEMP_ESP32_ALERT` | 10 kΩ | VIO → ALERT |
| `TEMP_ETH_ALERT` | 10 kΩ | VIO → ALERT |
| `TEMP_CODEC_ALERT` | 10 kΩ | VIO → ALERT |

---

# Stato

**U34:** assegnazione completa.

**U36:** assegnazione completa.

**TAC5212:** nessun GPIO dedicato al reset.

**BT1035_RESET:** nessun pull esterno.

**BT1035_SYSCTRL:** 10 kΩ pull-down.

**Linee open-drain/status:** pull-up 10 kΩ.

**TMP117:** 4 sensori I²C distribuiti nelle zone termicamente significative.

**TMP117 ALERT:** collegati al Device Manager tramite U36 GPB2–GPB5.

**U34 GPA6:** RESERVED.

**U36 GPB6–GPB7:** RESERVED.

**INTB U34/U36:** non collegati intenzionalmente.

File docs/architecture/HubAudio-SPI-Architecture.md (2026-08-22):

# HubAudio — SPI Bus Map

**Progetto:** HubAudio  
**Revisione:** definitiva  
**Data:** 2026-08-23

## SPI Bus Architecture

HubAudio utilizza un bus SPI principale con ESP32-S31-WROOM-3 come master.

Il bus principale condivide:

- `SPI_SCLK`
- `SPI_MOSI`
- `SPI_MISO`

Ogni slave dispone di una propria linea Chip Select (`CS`).

---

## SPI Main Bus

| IC | Dispositivo | Ruolo | CS |
|---|---|---|---|
| U5 | XTAC5212IRGER | Audio Codec | `SPI_CODEC_CS` |
| U34 | MCP23S17-E/ML | Device Manager A | `SPI_DEV_MAN_A_CS` |
| U36 | MCP23S17-E/ML | Device Manager B | `SPI_DEV_MAN_B_CS` |
| U18 | ADAU1467WBCPZ300R | Audio DSP | `SPI_ADAU1467_CS` |
| U12 | Si4684-A10-GM | Radio | `SPI_SI4684_CS` |
| U10 | W25Q128JVS | Flash | `SPI_W25Q128_CS` |
| U30 | SC16IS740IPW,128 | UART Bridge | `SPI_UART_CS` |

### Shared SPI Signals

| Segnale | Funzione |
|---|---|
| `SPI_SCLK` | SPI Clock |
| `SPI_MOSI` | Master Out / Slave In |
| `SPI_MISO` | Master In / Slave Out |

Il master SPI è l'**ESP32-S31-WROOM-3 (U11)**.

Le linee `SPI_SCLK`, `SPI_MOSI` e `SPI_MISO` sono condivise tra gli slave
del bus principale.

Le linee `CS` sono indipendenti e vengono utilizzate per selezionare
un singolo slave alla volta.

---

## Chip Select

| CS | Slave |
|---|---|
| `SPI_CODEC_CS` | U5 — TAC5212 |
| `SPI_DEV_MAN_A_CS` | U34 — MCP23S17 |
| `SPI_DEV_MAN_B_CS` | U36 — MCP23S17 |
| `SPI_ADAU1467_CS` | U18 — ADAU1467 |
| `SPI_SI4684_CS` | U12 — Si4684 |
| `SPI_W25Q128_CS` | U10 — W25Q128JVS |
| `SPI_UART_CS` | U30 — SC16IS740 |

---

# Private SPI Buses

Alcuni dispositivi dispongono di una memoria SPI dedicata e non fanno
parte del bus SPI principale dell'ESP32.

## ADAU1467 — Private SPI

| Master | Slave | Dispositivo |
|---|---|---|
| U18 | U24 | 25AA1024-I/SM |

**Master:** ADAU1467  
**Slave:** 25AA1024 SPI EEPROM

La memoria U24 utilizza il bus SPI privato dell'ADAU1467.

U24 **non** è uno slave del bus SPI principale dell'ESP32 e pertanto non
possiede una linea `CS` appartenente al namespace `SPI_*` del bus principale.

---

## Si4684 — Private SPI

| Master | Slave | Dispositivo |
|---|---|---|
| U12 | U27 | W25Q16JW |

**Master:** Si4684  
**Slave:** W25Q16JW SPI Flash

La memoria U27 utilizza il bus SPI privato del Si4684.

U27 **non** è uno slave del bus SPI principale dell'ESP32 e pertanto non
possiede una linea `CS` appartenente al namespace `SPI_*` del bus principale.

---

# SPI Topology

```text
                         ESP32-S31-WROOM-3
                              U11
                               │
                 ┌─────────────┼─────────────┐
                 │             │             │
             SPI_SCLK      SPI_MOSI      SPI_MISO
                 │             │             │
       ┌─────────┴─────────────┴─────────────┴─────────┐
       │                 SPI MAIN BUS                  │
       │                                                │
       ├── U5   TAC5212       ← SPI_CODEC_CS            │
       ├── U34  MCP23S17      ← SPI_DEV_MAN_A_CS        │
       ├── U36  MCP23S17      ← SPI_DEV_MAN_B_CS        │
       ├── U18  ADAU1467      ← SPI_ADAU1467_CS         │
       ├── U12  Si4684        ← SPI_SI4684_CS           │
       ├── U10  W25Q128JVS    ← SPI_W25Q128_CS          │
       └── U30  SC16IS740     ← SPI_UART_CS             │
                                                        │
       └────────────────────────────────────────────────┘

        PRIVATE SPI BUS                    PRIVATE SPI BUS
        ADAU1467                           Si4684
           U18                                U12
            │                                  │
            │ SPI                              │ SPI
            ▼                                  ▼
     U24 25AA1024                         U27 W25Q16JW
SPI Slave Summary
Bus	Master	Slave	Device
Main SPI	ESP32 U11	U5	TAC5212
Main SPI	ESP32 U11	U34	MCP23S17
Main SPI	ESP32 U11	U36	MCP23S17
Main SPI	ESP32 U11	U18	ADAU1467
Main SPI	ESP32 U11	U12	Si4684
Main SPI	ESP32 U11	U10	W25Q128JVS
Main SPI	ESP32 U11	U30	SC16IS740
Private SPI	ADAU1467 U18	U24	25AA1024
Private SPI	Si4684 U12	U27	W25Q16JW
Design Rules
SPI_SCLK, SPI_MOSI e SPI_MISO del bus principale sono condivisi tra
tutti gli slave del bus.
Ogni slave del bus principale deve avere una propria linea CS.
Deve essere attivo un solo CS alla volta durante una transazione SPI.
U24 e U27 non appartengono al bus SPI principale.
U24 è controllata direttamente dall'ADAU1467.
U27 è controllata direttamente dal Si4684.
I Chip Select dei bus privati non devono essere confusi con i CS
del bus SPI principale dell'ESP32.
La nomenclatura SPI_*_CS identifica esclusivamente le linee Chip Select
del bus SPI principale.
Main SPI Chip Select Map
SPI_CODEC_CS       → U5   TAC5212
SPI_DEV_MAN_A_CS   → U34  MCP23S17
SPI_DEV_MAN_B_CS   → U36  MCP23S17
SPI_ADAU1467_CS    → U18  ADAU1467
SPI_SI4684_CS      → U12  Si4684
SPI_W25Q128_CS     → U10  W25Q128JVS
SPI_UART_CS        → U30  SC16IS740
Stato

SPI principale: 7 slave.

SPI privato ADAU1467: 1 slave.

SPI privato Si4684: 1 slave.

Totale dispositivi SPI: 9.

Master SPI principale: ESP32-S31-WROOM-3.

Master SPI privati: ADAU1467 e Si4684.

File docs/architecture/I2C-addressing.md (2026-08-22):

# HubAudio — I²C Bus Map

**Progetto:** HubAudio  
**Revisione:** definitiva  
**Data:** 2026-08-23

## Dispositivi I²C

| IC | Componente | Configurazione indirizzo | Indirizzo I²C (7-bit) |
|---|---|---|---:|
| U1 | BQ25896RTWR | Indirizzo fisso | `0x6B` |
| U2 | BQ27441DRZR-G1B | Indirizzo fisso | `0x55` |
| U4 | INA228AQDGSRQ1 | A0 = 0, A1 = 0 | `0x40` |
| U8 | INA228AQDGSRQ1 | A0 = 0, A1 = 1 | `0x41` |
| U17 | 24AA025E64 | A2 = 0, A1 = 0, A0 = 0 | `0x50` |
| U20 | TPS22994RUKT | ADDR3 = 0, ADDR2 = 0, ADDR1 = 0 | `0x20` |
| U23 | TPS22994RUKT | ADDR3 = 0, ADDR2 = 0, ADDR1 = 1 | `0x21` |
| U31 | TMP117NAIDRVR | ADDR = GND | `0x48` |
| U32 | TMP117NAIDRVR | ADDR = VCC | `0x49` |
| U33 | TMP117NAIDRVR | ADDR = SDA | `0x4A` |
| U37 | TMP117NAIDRVR | ADDR = SCL | `0x4B` |

## Address Map

| Indirizzo | IC | Dispositivo |
|---:|---|---|
| `0x20` | U20 | TPS22994 |
| `0x21` | U23 | TPS22994 |
| `0x40` | U4 | INA228 — Analog |
| `0x41` | U8 | INA228 — Digital |
| `0x48` | U31 | TMP117 — Power |
| `0x49` | U32 | TMP117 — ESP32 |
| `0x4A` | U33 | TMP117 — DSP |
| `0x4B` | U37 | TMP117 — Codec |
| `0x50` | U17 | 24AA025E64 |
| `0x55` | U2 | BQ27441 |
| `0x6B` | U1 | BQ25896 |

## TMP117

I quattro TMP117 utilizzano tutte le quattro configurazioni disponibili del
pin `ADDR`:

- **U31 — Power:** `ADDR → GND` → `0x48`
- **U32 — ESP32:** `ADDR → VCC` → `0x49`
- **U33 — DSP:** `ADDR → SDA` → `0x4A`
- **U37 — Codec:** `ADDR → SCL` → `0x4B`

Ogni TMP117 dispone di un condensatore di bypass locale da **100 nF**.

## INA228

- **U4 — Analog:** A0 = 0, A1 = 0 → `0x40`
- **U8 — Digital:** A0 = 0, A1 = 1 → `0x41`

## TPS22994

- **U20:** ADDR3 = 0, ADDR2 = 0, ADDR1 = 0 → `0x20`
- **U23:** ADDR3 = 0, ADDR2 = 0, ADDR1 = 1 → `0x21`

## EEPROM

**U17 — 24AA025E64**

```text
A2 = GND
A1 = GND
A0 = GND

→ 0x50

Indirizzi fissi

U1 — BQ25896: 0x6B

U2 — BQ27441: 0x55

Verifica collisioni

Non risultano collisioni tra gli indirizzi I²C assegnati.

Totale dispositivi I²C: 11

Indirizzi utilizzati: 11

0x20
0x21
0x40
0x41
0x48
0x49
0x4A
0x4B
0x50
0x55
0x6B

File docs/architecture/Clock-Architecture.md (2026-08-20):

# DigiRadio — Clock Architecture and I²S Clock-Domain Implementation

**Document ID:** ARCH-CLOCK-001  
**Status:** Design Baseline  
**Revision:** 2.0  
**Date:** 2026-08-15  
**Scope:** ADAU1467, Si4684, ESP32-S31-WROOM3, TLV320AIC3104IRHBR, BT1035, S/PDIF

---

## 1. Purpose

This document defines the DigiRadio digital-audio clock architecture and the physical implementation rules for the I²S clock signals.

The architecture is based on the **ADAU1467** as the central DSP and audio-clock hub.

The design objectives are:

- one primary 12.288 MHz audio reference;
- 48 kHz primary audio sample rate;
- removal of the dedicated Si4684 crystal by supplying its external reference from the ADAU1467;
- use of the TLV320AIC3104 as the analog audio codec;
- independent BCLK/LRCLK pairs for the individual I²S interfaces;
- no external BCLK/LRCLK splitter or "clock mixing" network;
- explicit separation of ADAU1467 input and output clock domains;
- use of ADAU1467 internal clock-domain architecture rather than electrically tying unrelated clock signals together.

This document is an **implementation document**: it defines how the clock architecture shall be translated into the KiCad schematic and PCB.

---

# 2. Architectural Principle

The fundamental design principle is:

> **Each external I²S peripheral receives its own BCLK/LRCLK pair from the corresponding ADAU1467 serial-port clock domain.**

The PCB shall **not electrically combine BCLK or LRCLK signals belonging to different serial ports**.

The ADAU1467 internally generates and manages the required audio clock domains.

Therefore, the PCB must not contain a global:

```text
BCLK ─┬─ Device 1
      ├─ Device 2
      ├─ Device 3
      └─ Device 4

or:

LRCLK ─┬─ Device 1
       ├─ Device 2
       ├─ Device 3
       └─ Device 4

unless a specific group of peripherals has deliberately been assigned to the same physical clock source and the electrical topology has been explicitly designed for that purpose.
The default DigiRadio implementation is one BCLK/LRCLK pair per I²S interface.

3. Master Reference Clock
3.1 Primary reference
The DigiRadio primary audio reference is:

12.288 MHz

generated by a passive crystal connected to the ADAU1467 oscillator/MCLK input.
Architecture:

12.288 MHz crystal
        │
        ▼
   ADAU1467 MCLK/XTAL
        │
        ▼
       PLL
        │
        ▼
  Clock Generators
        │
        ├── audio clock domains
        └── CLKOUT

The 12.288 MHz reference is appropriate for a 48 kHz audio system because:

12.288 MHz / 256 = 48 kHz

4. ADAU1467 Clock Architecture
The ADAU1467 contains the clock-generation infrastructure required for a multi-peripheral audio system.
The important architectural distinction is:

ADAU1467 INPUT CLOCK DOMAINS
            ≠
ADAU1467 OUTPUT CLOCK DOMAINS

Even if two domains are configured to exactly the same nominal frequency, they are not to be treated as the same physical PCB clock net.
The ADAU1467 provides multiple serial input and output ports and multiple clock domains, allowing different peripherals to be assigned independently.
This is the reason a separate BCLK/LRCLK splitter IC is not required by the baseline architecture.

5. Primary Audio Rate
The primary DigiRadio audio rate is:

Fs = 48 kHz

For stereo I²S with 32-bit slots:

BCLK = 48,000 × 32 × 2
     = 3,072,000 Hz
     = 3.072 MHz

Therefore the baseline values are:
Signal
Frequency
Master reference
12.288 MHz
LRCLK / WCLK
48 kHz
BCLK
3.072 MHz
I²S slot width
32 bit
Channels
2
These values are the baseline. Individual devices must still be configured according to their own I²S timing and supported formats.

6. Global Clock Tree
The logical architecture is:

                         12.288 MHz
                         passive crystal
                              │
                              ▼
                     ┌────────────────┐
                     │    ADAU1467    │
                     │                │
                     │ MCLK / PLL     │
                     │ Clock Generators│
                     │                │
                     │ DSP @ 48 kHz   │
                     └───────┬────────┘
                             │
             ┌───────────────┴────────────────┐
             │                                │
             ▼                                ▼
        CLKOUT 12.288 MHz              I²S clock domains
             │                                │
        ┌────┴────┐                ┌──────────┼──────────┐
        │         │                │          │          │
        ▼         ▼                ▼          ▼          ▼
     Si4684    AIC3104          Si4684      BT1035     Codec
     XTALI     MCLK             I²S IN      I²S OUT    I²S

The 12.288 MHz reference and the I²S BCLK/LRCLK signals are separate functions.

7. Si4684 Reference Clock
7.1 External reference
The Si4684 supports an external reference clock through XTALI.
The DigiRadio design shall use:

ADAU1467 CLKOUT
       │
       │ 12.288 MHz
       ▼
Si4684 XTALI

The Si4684 shall be configured for the appropriate external-clock mode.
The firmware configuration must explicitly set:

XTAL_FREQ = 12,288,000 Hz

and the correct external-clock CLK_MODE.
The Si4684 crystal oscillator configuration parameters shall not be blindly reused for external-clock operation.
7.2 Crystal removal
The Si4684's dedicated crystal is therefore not part of the baseline design.
The only primary 12.288 MHz crystal in the DigiRadio design is the one associated with the ADAU1467.
7.3 Electrical validation
Before schematic/PCB freeze, verify:
	•	ADAU1467 CLKOUT output level;
	•	Si4684 XTALI input limits;
	•	frequency;
	•	duty cycle;
	•	rise/fall time;
	•	startup sequence;
	•	signal integrity;
	•	routing noise coupling.

8. Si4684 I²S Input
The Si4684 audio data enters the ADAU1467.
Baseline:

Si4684                         ADAU1467

DOUT   ──────────────────────► Serial IN
BCLK   ◄────────────────────── Serial IN clock
LRCLK  ◄────────────────────── Serial IN frame clock

The Si4684 is configured as an I²S slave.
The BCLK/LRCLK pair used by the Si4684 belongs to the selected ADAU1467 input clock domain.
It shall not be physically connected to the BCLK/LRCLK pair used by an ADAU1467 output port merely because both operate at 48 kHz.

9. ESP32-S31-WROOM3 I²S Input
The ESP32 audio stream enters the ADAU1467.
Preferred configuration:

ADAU1467 = I²S clock master
ESP32    = I²S clock slave

Physical connection:

ESP32 DATA ─────────────────► ADAU1467 Serial IN

ADAU1467 BCLK_x ────────────► ESP32 BCLK
ADAU1467 LRCLK_x ───────────► ESP32 LRCLK

The ESP32 BCLK/LRCLK pair is a dedicated clock pair for that serial interface.
It is not to be joined to the Si4684 BCLK/LRCLK pair on the PCB.
The final ESP32 firmware shall use:

Fs = 48 kHz
slot width = 32 bit
I²S slave mode

where supported by the selected ESP32 I²S implementation.

10. TLV320AIC3104 Codec
The codec is:

TLV320AIC3104IRHBR

It provides:
	•	stereo ADC;
	•	stereo DAC;
	•	Line In;
	•	Line Out;
	•	headphone output path;
	•	digital I²S interface;
	•	internal clock/PLL circuitry.

11. Codec MCLK
The codec can use the same 12.288 MHz clock reference.
Preferred connection:

ADAU1467 CLKOUT
       │
       │ 12.288 MHz
       ▼
TLV320AIC3104 MCLK

At 48 kHz:

12.288 MHz / 256 = 48 kHz

This provides a clean and deterministic clock relationship between the ADAU1467 and codec.
The codec's PLL/divider configuration must be programmed according to the TLV320AIC3104 datasheet.

12. Codec ADC — Line In to ADAU1467
The analog input path is:

LINE IN
   │
   ▼
TLV320AIC3104 ADC
   │
   │ DOUT
   ▼
ADAU1467 Serial IN

The digital clock connection is:

ADAU1467 BCLK_CODEC_IN
        │
        └──────────────► AIC3104 BCLK

ADAU1467 LRCLK_CODEC_IN
        │
        └──────────────► AIC3104 WCLK/LRCLK

and:

AIC3104 DOUT ─────────► ADAU1467 Serial IN

The codec ADC interface is therefore an ADAU1467 input serial port.

13. Codec DAC — ADAU1467 to Line Out / Headphone
The output path is:

ADAU1467 Serial OUT
        │
        │ DIN
        ▼
TLV320AIC3104 DAC
        │
        ├──► LINE OUT
        │
        └──► HEADPHONE AMPLIFIER
                    │
                    ▼
              Headphone Jack

Clocking:

ADAU1467 BCLK_CODEC_OUT
        │
        └──────────────► AIC3104 BCLK

ADAU1467 LRCLK_CODEC_OUT
        │
        └──────────────► AIC3104 WCLK/LRCLK

Data:

ADAU1467 Serial OUT DATA ──► AIC3104 DIN

The codec output clock pair is a dedicated ADAU1467 output clock-domain pair.

14. Important: Codec Input and Output Clocks
Even though the codec ADC and DAC operate at the same nominal:

48 kHz / 3.072 MHz

the schematic shall not assume that the codec ADC and DAC automatically share one physical BCLK/LRCLK net.
The preferred implementation is:

ADAU1467 INPUT CLOCK DOMAIN
        │
        ├── BCLK_CODEC_IN
        └── LRCLK_CODEC_IN
                 │
                 ▼
              AIC3104 ADC

ADAU1467 OUTPUT CLOCK DOMAIN
        │
        ├── BCLK_CODEC_OUT
        └── LRCLK_CODEC_OUT
                 │
                 ▼
              AIC3104 DAC

Whether the final AIC3104 implementation can safely use one common physical clock pair for both directions is a specific codec-interface configuration decision and must be made from the TLV320AIC3104 timing/master/slave requirements.
The architecture does not require us to tie the two domains together.

15. BT1035
The BT1035 is an I²S output peripheral.
Preferred configuration:

ADAU1467 = I²S master
BT1035   = I²S slave

Physical connections:

ADAU1467 BCLK_BT
        └──────────────► BT1035 BCLK

ADAU1467 LRCLK_BT
        └──────────────► BT1035 LRCLK

ADAU1467 DATA_BT
        └──────────────► BT1035 I²S DATA

Baseline:

48 kHz
32 bit
BCLK = 3.072 MHz

The BT1035 interface is an ADAU1467 output clock domain.
It shall not share a PCB BCLK/LRCLK net with the codec unless deliberately configured and electrically verified.

16. S/PDIF Input
S/PDIF is handled by the dedicated ADAU1467 S/PDIF input.

S/PDIF IN
    │
    ▼
ADAU1467 S/PDIF RX
    │
    ▼
ASRC / DSP clock domain

There is no external BCLK/LRCLK connection.
The recovered S/PDIF clock is not physically combined with the I²S clock network.

17. S/PDIF Output
Likewise:

ADAU1467 S/PDIF TX
        │
        ▼
S/PDIF OUT

No external BCLK/LRCLK is required.

18. Clock-Domain Allocation
The following is the proposed logical allocation.
Input side
Device
ADAU interface
Clock ownership
Si4684
Serial IN 0
ADAU1467 input clock domain
ESP32-S31-WROOM3
Serial IN 1
ADAU1467 input clock domain
AIC3104 ADC
Serial IN 2
ADAU1467 input clock domain
S/PDIF
Dedicated S/PDIF IN
Recovered S/PDIF clock / ASRC
Output side
Device
ADAU interface
Clock ownership
BT1035
Serial OUT 0
ADAU1467 output clock domain
AIC3104 DAC
Serial OUT 1
ADAU1467 output clock domain
S/PDIF
Dedicated S/PDIF OUT
ADAU1467 S/PDIF subsystem
The exact serial-port numbers are implementation assignments and shall be finalized against the ADAU1467 pinout and PCB placement.

19. No Clock "Mishmash"
The following shall be considered a design rule:
Do not electrically connect unrelated BCLK or LRCLK signals merely because they have the same frequency.
For example, these are logically different:

BCLK_SI4684
BCLK_ESP32
BCLK_CODEC_IN
BCLK_BT
BCLK_CODEC_OUT

Even if all are:

3.072 MHz

they are separate clock nets.
Likewise:

LRCLK_SI4684
LRCLK_ESP32
LRCLK_CODEC_IN
LRCLK_BT
LRCLK_CODEC_OUT

remain separate nets.
This provides:
	•	deterministic ownership;
	•	no contention between clock drivers;
	•	cleaner PCB routing;
	•	easier debugging;
	•	easier clock-domain changes;
	•	easier future support for different sample rates.

20. Internal ADAU1467 Clock Relationship
The important distinction is:

PHYSICAL PCB CONNECTION
        ≠
LOGICAL CLOCK RELATIONSHIP

The ADAU1467 can derive several clock domains from the same master reference.
Therefore:

BCLK_A = 3.072 MHz
BCLK_B = 3.072 MHz
BCLK_C = 3.072 MHz

does not imply:

BCLK_A = physical net BCLK_B = physical net BCLK_C

They are independently generated/assigned clock-domain signals.
The synchronization relationship is established by the ADAU1467 clock-generation architecture.

21. PCB Net Naming
The schematic shall use explicit net names.
Recommended names:

MCLK_12M288
SI4684_BCLK
SI4684_LRCLK
SI4684_SDOUT

ESP32_BCLK
ESP32_LRCLK
ESP32_SDOUT

CODEC_ADC_BCLK
CODEC_ADC_LRCLK
CODEC_ADC_SDOUT

BT_BCLK
BT_LRCLK
BT_SDIN

CODEC_DAC_BCLK
CODEC_DAC_LRCLK
CODEC_DAC_SDIN

SPDIF_IN
SPDIF_OUT

Do not use a generic:

BCLK
LRCLK

label for the entire board unless that net is intentionally a single shared physical clock.

22. PCB Routing Rules
22.1 MCLK_12M288
Route:

ADAU1467 CLKOUT
      │
      ├──► Si4684 XTALI
      └──► AIC3104 MCLK

The two loads may be fed from the same source only after checking the ADAU1467 CLKOUT drive capability and total input capacitance.
Keep the clock routes short and away from switching-regulator nodes.
22.2 BCLK/LRCLK
Each clock pair shall be routed independently:

ADAU1467
  │
  ├── SI4684_BCLK / LRCLK
  │
  ├── ESP32_BCLK / LRCLK
  │
  ├── CODEC_ADC_BCLK / LRCLK
  │
  ├── BT_BCLK / LRCLK
  │
  └── CODEC_DAC_BCLK / LRCLK

Avoid unnecessary stubs.
Use source termination if required by signal-integrity analysis.

23. Why No External Clock Splitter?
A clock splitter is not required simply because several peripherals use 48 kHz.
The ADAU1467 already provides the required clock-generation architecture.
Adding an external clock splitter would introduce:
	•	another active clock component;
	•	additional propagation delay;
	•	additional jitter;
	•	additional power consumption;
	•	another configuration dependency;
	•	another possible failure point.
It should therefore be added only if electrical analysis proves that a specific fanout requirement cannot be met by the ADAU1467 clock outputs.

24. Why Not Share BCLK/LRCLK Everywhere?
Sharing clock signals is technically possible in some I²S designs, but it is not the baseline DigiRadio architecture.
The risks of indiscriminate sharing are:
	•	conflicting clock drivers;
	•	accidental master/master configuration;
	•	long PCB branches;
	•	uncontrolled stubs;
	•	difficult debugging;
	•	inability to independently change one interface;
	•	confusion between ADAU input and output clock domains.
The ADAU1467 gives us enough clock-domain infrastructure to avoid these problems.
Therefore the design deliberately favors independent clock pairs.

25. Master/Slave Policy
The baseline policy is:
Device
I²S role
ADAU1467
Master
Si4684
Slave
ESP32-S31-WROOM3
Slave
TLV320AIC3104
Slave where supported/configured
BT1035
Slave
This avoids multiple external clock masters.
Any deviation must be documented as an explicit architecture change.

26. Sample-Rate Conversion
If an external source operates at a sample rate different from 48 kHz:

External clock domain
        │
        ▼
ADAU1467 Serial Port
        │
        ▼
      ASRC
        │
        ▼
48 kHz DSP domain

The external BCLK/LRCLK must remain local to that interface.
It shall not be forced onto the main 48 kHz clock net.

27. Final Logical Architecture

                         12.288 MHz
                        ADAU CRYSTAL
                             │
                             ▼
                     ┌───────────────┐
                     │   ADAU1467    │
                     │               │
                     │ PLL           │
                     │ Clock Gen.    │
                     │ DSP           │
                     └───────┬───────┘
                             │
              ┌──────────────┼───────────────┐
              │              │               │
              ▼              ▼               ▼
         CLKOUT         INPUT DOMAINS    OUTPUT DOMAINS
        12.288 MHz           │               │
              │              │               │
        ┌─────┴─────┐        │          ┌────┼─────┐
        │           │        │          │          │
        ▼           ▼        ▼          ▼          ▼
     Si4684      AIC3104   Si4684     BT1035     AIC3104
     XTALI        MCLK      I²S IN     I²S OUT    I²S OUT
                               ▲          │          │
                               │          │          │
                            ESP32 I²S   BCLK/LR   BCLK/LR
                               ▲
                               │
                           ESP32 DATA

S/PDIF remains on the dedicated ADAU1467 interfaces.

28. Implementation Sequence
The schematic implementation shall proceed in this order:
	1	Place ADAU1467.
	2	Place the 12.288 MHz crystal and its oscillator network.
	3	Define ADAU1467 PLL and clock-generator configuration.
	4	Define serial input clock domains.
	5	Assign Si4684 to an input serial port.
	6	Assign ESP32 to an input serial port.
	7	Assign AIC3104 ADC to an input serial port.
	8	Define output clock domains.
	9	Assign BT1035 to an output serial port.
	10	Assign AIC3104 DAC to an output serial port.
	11	Connect ADAU1467 CLKOUT to Si4684 XTALI.
	12	Connect ADAU1467 CLKOUT to AIC3104 MCLK if the final loading analysis permits.
	13	Route every BCLK/LRCLK pair as a separate named net.
	14	Verify that no two clock outputs are accidentally shorted.
	15	Verify all master/slave settings.
	16	Verify SigmaStudio serial-port and clock-domain assignments against the schematic.
	17	Perform signal-integrity review before PCB release.

29. Verification Checklist
Master clock
	•	12.288 MHz crystal connected to ADAU1467.
	•	ADAU1467 PLL configuration verified.
	•	12.288 MHz CLKOUT configuration verified.
	•	CLKOUT loading verified.
Si4684
	•	Dedicated crystal removed.
	•	XTALI driven from ADAU1467 CLKOUT.
	•	External-clock mode configured.
	•	XTAL_FREQ = 12,288,000 Hz.
	•	I²S slave mode configured.
	•	Dedicated SI4684_BCLK net.
	•	Dedicated SI4684_LRCLK net.
ESP32
	•	I²S slave mode verified.
	•	Dedicated ESP32_BCLK net.
	•	Dedicated ESP32_LRCLK net.
	•	48 kHz / selected slot format verified.
TLV320AIC3104
	•	MCLK = 12.288 MHz verified.
	•	ADC serial input assigned.
	•	DAC serial output assigned.
	•	Master/slave mode verified.
	•	ADC BCLK/LRCLK routing verified.
	•	DAC BCLK/LRCLK routing verified.
	•	Headphone path verified.
BT1035
	•	I²S slave mode verified.
	•	48 kHz / 32-bit configuration verified.
	•	Dedicated BT_BCLK.
	•	Dedicated BT_LRCLK.
S/PDIF
	•	Dedicated ADAU1467 S/PDIF IN.
	•	Dedicated ADAU1467 S/PDIF OUT.
	•	No BCLK/LRCLK connection required.
PCB
	•	No unintended common BCLK net.
	•	No unintended common LRCLK net.
	•	No master/master connection.
	•	Clock routes kept short.
	•	Switching-node coupling checked.
	•	Signal integrity checked.

30. Design Decision
The DigiRadio clock architecture is therefore based on the following definitive principles:
	1	One primary 12.288 MHz crystal on the ADAU1467.
	2	ADAU1467 is the central audio clock master.
	3	Main audio rate is 48 kHz.
	4	Baseline I²S BCLK is 3.072 MHz for stereo 32-bit slots.
	5	Si4684 receives 12.288 MHz externally from ADAU1467 CLKOUT.
	6	The Si4684 dedicated crystal is removed.
	7	TLV320AIC3104 may receive the same 12.288 MHz master reference on MCLK.
	8	Each I²S peripheral receives its own BCLK/LRCLK pair.
	9	Input and output ADAU1467 clock domains are treated as distinct.
	10	BCLK/LRCLK signals are not electrically mixed on the PCB.
	11	No generic BCLK/LRCLK splitter is required by the architecture.
	12	S/PDIF uses the dedicated ADAU1467 interfaces.
	13	ASRC is used when an external source belongs to an incompatible/asynchronous clock domain.
	14	All clock-domain assignments must be explicitly reflected in both SigmaStudio and KiCad.

31. References
Primary references to be kept with the DigiRadio repository:
	•	Analog Devices — ADAU1463/ADAU1467 Data Sheet.
	•	Analog Devices — ADAU1467 product and evaluation-board documentation.
	•	Silicon Labs — Si468x Receiver Programming Guide (AN649).
	•	Silicon Labs — Si4684 hardware/reference documentation.
	•	Texas Instruments — TLV320AIC3104 Data Sheet.
	•	Feasycom — BT1035 Programming User Guide.
	•	DigiRadio SigmaStudio project and generated DSP configuration.
Vendor documents stored in the repository shall be treated as the implementation references. If a newer revision is added, this architecture document shall be reviewed before schematic freeze.

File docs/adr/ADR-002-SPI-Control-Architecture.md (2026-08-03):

# ADR-002: SPI Control Architecture

- Status: Accepted
- Date: 2026-08-01
- Decision Type: Hardware Architecture

## Context

HubAudio integrates multiple programmable devices requiring configuration,
control and firmware management.

The main devices involved are:

- System Controller system controller
- Audio Processor audio processor
- Radio Receiver radio receiver

A clear separation between system control and internal device management is
required.

The SPI interface is used exclusively as a control interface and not as an
audio transport interface.

## Decision

The SPI architecture is divided into independent control domains.

The System Controller operates as the master of the system control SPI bus.

The Audio Processor and Radio Receiver expose SPI slave interfaces for external
configuration and control.

The internal management of each device remains under the responsibility of
the device itself.

## Architecture

System control SPI domain:

            System Controller

          SPI MASTER

              |
    +---------+---------+
    |                   |
 Audio Processor            Radio Receiver

SPI SLAVE          SPI SLAVE

## Audio Processor Configuration Domain

The Audio Processor manages its own external configuration memory through its
internal SPI master interface.

          Audio Processor

        SPI MASTER

              |

          Audio EEPROM

   DSP Program / Configuration Memory

The System Controller controls the Audio Processor through the external SPI interface but
does not directly access the DSP configuration memory during normal
operation.

## Radio Receiver Firmware Domain

The Radio Receiver firmware loading and configuration process is managed through
commands exchanged on the external SPI control interface.

           System Controller

        SPI MASTER

              |

           Radio Receiver

              |

    Internal Firmware Loader

              |

         Internal RAM

The System Controller supervises the Radio Receiver initialization process. Internal firmware loading remains under the responsibility of the Radio Receiver boot architecture.

## Consequences

### Positive

- Clear ownership of every SPI interface
- No bus contention between devices
- Reduced electrical loading
- Independent device initialization
- Easier debugging and validation

### Negative

- Multiple control interfaces are required
- Firmware update procedures must coordinate different device domains

## Rationale

The System Controller supervises the complete HubAudio system but does not replace the
internal controllers of specialized devices.

Each component remains responsible for its own functional domain.

The control plane and the audio plane remain architecturally separated.

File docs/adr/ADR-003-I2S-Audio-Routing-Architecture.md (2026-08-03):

# ADR-003: I2S Audio Routing Architecture

- Status: Accepted
- Date: 2026-08-01
- Decision Type: Audio Architecture

## Context

HubAudio integrates multiple digital audio sources and destinations:

Sources:

- System Controller streaming subsystem
- Radio Receiver radio receiver
- Bluetooth receiver
- Optical digital input

Destinations:

- Analog audio output through CODEC/DAC
- Bluetooth transmission
- Optical digital output

A deterministic and scalable digital audio routing architecture is required.

## Decision

The Audio Processor is the central routing element of the Audio Domain.

Each major audio device is assigned to a dedicated serial audio interface.

The preferred architecture is:

One audio device = One dedicated I2S interface

The Audio Processor operates as the audio timing reference.

External audio devices operate as I2S slaves whenever supported.

## Audio Input Allocation

|| Audio Processor Input | Device | Function |
|---|---|---|
| SDATA_IN0 | System Controller | Network audio stream |
| SDATA_IN1 | Radio Receiver | Radio audio |
| SPDIFIN | Optical Interface | Optical digital audio input |
| SDATA_IN2 | Bluetooth RX | Wireless audio input |

The ADAU1467 internal audio routing matrix allows any digital audio input
to be routed to the DSP core, ASRCs, serial outputs or SPDIF output.

System Controller --------
Radio Receiver ---------
DECODEC ----------+---- Audio Processor
BT RX ---------/

## Audio Output Allocation

## Audio Output Allocation

| Audio Processor Output | Device | Function |
|---|---|---|
| SDATA_OUT0 | CODEC/DAC | Analog audio output |
| SDATA_OUT1 | Bluetooth TX | Wireless audio output |
| SPDIFOUT | Optical Interface | Optical digital audio output |
| SDATA_OUT3 | Reserved | Future expansion |

             Audio Processor

                 |
    +------------+------------+
    |            |            |
  CODEC        BTTX       ENCODEC

## Clocking

The Audio Processor provides the master audio timing reference.

The audio clock domain consists of:

- MCLK
- BCLK
- LRCLK

All connected audio peripherals must operate synchronized to this clock
domain.

## Consequences

### Positive

- Deterministic audio timing
- Simple routing model
- Independent audio channels
- Easier debugging
- Future expansion capability

### Negative

- Higher pin usage
- More PCB routing resources required
- Peripheral selection must consider I2S slave capability

## Rationale

HubAudio prioritizes signal integrity, maintainability and deterministic
audio behavior over maximum bus utilization.

The Audio Processor acts as the central audio router of the system.

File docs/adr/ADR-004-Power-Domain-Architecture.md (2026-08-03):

# ADR-004 – Power Domain Architecture

- **Status:** Accepted
- **Date:** 2026-08-02

# Context

HubAudio integra sottosistemi con caratteristiche elettriche molto differenti:

- elaborazione digitale (System Controller)
- DSP audio
- ricevitore radio
- Bluetooth
- codec audio
- periferiche di controllo

Una distribuzione tradizionale mediante un unico rail a 3.3 V comporterebbe la condivisione delle correnti impulsive tra dispositivi con requisiti completamente differenti, aumentando il rumore di alimentazione e rendendo più complesso il debug del sistema.

# Decision

L'architettura di alimentazione viene organizzata mediante **Power Domains**.

La distribuzione primaria genera due domini principali:

- **3V3_DIGITAL**
- **3V3_AUDIO**

Il dominio digitale alimenta esclusivamente la logica di controllo.

Il dominio audio alimenta esclusivamente i dispositivi appartenenti alla catena audio.

Ogni nuovo sottosistema dovrà appartenere ad un dominio chiaramente identificato.

La separazione dei domini rappresenta una scelta architetturale e non un dettaglio implementativo.

# Consequences

## Advantages

- riduzione del rumore tra domini
- migliore immunità EMI
- maggiore modularità
- possibilità di monitoraggio energetico
- semplificazione del power sequencing
- migliore manutenibilità

## Trade-offs

- incremento del numero di rail
- maggiore complessità dello schema
- maggiore attenzione richiesta durante il layout PCB

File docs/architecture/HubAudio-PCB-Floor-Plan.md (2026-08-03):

# HubAudio PCB Floor Plan

- Status: Draft
- Date: 2026-08-01
- Document Type: Hardware Architecture

# 1. Overview

This document defines the preliminary PCB floor plan for the HubAudio
single-board audio platform.

The PCB integrates:

- System Controller
- Audio Processor
- Radio Receiver
- Wireless Audio Interfaces
- Digital Audio Interfaces
- Power Management
- Battery Operation Support

The floor plan follows the fundamental HubAudio architecture:

ESP32-S3 manages the Control Domain.

ADAU1467 manages the Audio Domain.

The Clock Distribution Layer provides synchronization
for digital audio peripherals.

The PCB layout must preserve separation between:

- Control Domain
- Audio Domain
- Clock Domain
- Power Domain

The objective is to create a compact portable audio platform while
maintaining:

- audio signal integrity
- clock stability
- RF performance
- power efficiency
- battery operation capability

---

# 2. PCB Constraints

## 2.1 Target Dimensions

The HubAudio board is designed as a compact single-board platform.

Preferred PCB size:
Layer 1
Component placement
Critical digital signals
Audio routing

Layer 2
Continuous GND plane

Layer 3
Power distribution

Layer 4
Control signals
Low speed routing
Auxiliary signals

A 6-layer PCB remains an optional evolution only if required after
routing verification.

The transition to 6 layers must be justified by:

- routing density
- clock integrity
- RF isolation requirements
- power distribution constraints

The initial architecture target remains:
4 Layer PCB

---

# 4. Functional PCB Zones

The PCB is divided into five functional areas.

## 4.1 Control Zone

Contains:

- ESP32-S3
- USB interface
- programming interface
- user interface connections

Responsibilities:

- network connectivity
- streaming control
- configuration management
- firmware updates

Placement requirements:

- close to PCB edge
- antenna clearance
- separated from switching regulators

---

## 4.2 Audio Processing Zone

Contains:

- ADAU1467
- Audio EEPROM
- Clock circuitry
- Audio domain support components

The ADAU1467 is the physical center of the Audio Domain.

Responsibilities:

- DSP processing
- routing
- mixing
- synchronization

Critical signals:

- MCLK
- BCLK
- LRCLK
- I2S DATA

must remain short.

---

## 4.3 Radio Zone

Contains:

- Si4684
- RF interface
- antenna related components

Placement requirements:

- close to RF input
- separated from switching noise
- local power filtering

The Si4684 operates as a digital audio peripheral
inside the Audio Domain.

---

## 4.4 Audio Interface Zone

Contains:

- Bluetooth interfaces
- Optical interfaces
- CODEC/DAC stages

Interfaces:
I2S
|
ADAU1467

Placement requirements:

- close to PCB edge
- short I2S paths
- controlled supply filtering

---

## 4.5 Power Zone

Contains:

- Battery input
- USB power input
- Charger
- PMIC
- Regulators
- Filtering components

Placement:

PCB edge area

Power path:

Battery / USB

  |

Protection

  |

Charger

  |

PMIC

  |

Regulators

  |

Digital / Analog domains

The Power Zone must remain physically separated from:

- clock circuitry
- RF section
- sensitive audio signals

---

# 5. Preliminary Floor Plan

Conceptual arrangement:

+--------------------------------+
| |
| ESP32-S3 Si4684 |
| CONTROL RADIO |
| |
| |
| CLOCK |
| BUFFER |
| | |
| | |
| ADAU1467 |
| AUDIO PROCESSOR |
| |
| |
| BT RX SPDIF CODEC BT TX |
| AUDIO INTERFACE |

BATTERY / PMIC / CHARGER
POWER DOMAIN

+--------------------------------+

PCB TARGET:

90 mm x 70 mm

This arrangement keeps the ADAU1467 physically central.

The placement minimizes:

- I2S length
- clock distribution length
- audio routing complexity

---

# 6. ADAU1467 Placement

The ADAU1467 is the physical center of the digital audio subsystem.

This follows the architecture decision:

ADAU1467 = Audio Domain Master

Placement rules:

- central PCB position
- shortest clock paths
- shortest I2S paths
- local decoupling network
- separated from switching regulators

The ADAU1467 area includes:

- DSP processor
- clock interface
- SPI configuration interface
- audio EEPROM

Critical signals:

MCLK
BCLK
LRCLK
I2S DATA

must be routed with priority.

---

# 7. ESP32-S3 Placement

The ESP32-S3 belongs to the Control Domain.

Placement rules:

- PCB edge placement
- antenna keep-out area
- USB accessibility
- separation from analog audio

The ESP32-S3 interfaces:

Control:

SPI

Audio:

I2S Source

The ESP32-S3 is not the audio clock master.

---

# 8. Clock Distribution Placement

The Clock Distribution Layer provides:

- MCLK
- BCLK
- LRCLK

Architecture:

         ADAU1467

      Audio Clock Master

             |

      Clock Buffer

             |

 +-----------+-----------+

 |           |           |

CODEC Si4684 BT

Clock traces must have priority routing.

---

# 9. Routing Priorities

Routing priority:

1. Clock signals

MCLK
BCLK
LRCLK

2. I2S audio buses

3. SPI control

4. Power distribution

5. Low-speed signals

Clock and audio signals must avoid:

- switching regulator nodes
- RF traces
- high current battery paths

---

# 10. Summary

The HubAudio PCB follows the architectural separation:

CONTROL DOMAIN

ESP32-S3

    SPI

AUDIO DOMAIN

ADAU1467

    I2S

CLOCK DOMAIN

Clock Distribution

POWER DOMAIN

Battery / PMIC / Regulators

The floor plan defines a compact single-board implementation
optimized for:

- portability
- battery operation
- audio integrity
- future expansion

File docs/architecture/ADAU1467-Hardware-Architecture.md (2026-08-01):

# ADAU1467 Hardware Architecture

- Status: Draft
- Date: 2026-08-01
- Document Type: Component Architecture

# 1. Overview

The ADAU1467 is the central audio processor of HubAudio.

It represents the boundary between:

- Control Domain
- Audio Domain
- Time Domain

The device provides:

- SigmaDSP processing
- digital audio routing
- serial audio interfaces
- clock generation
- self boot capability

The ADAU1467 is not considered a simple peripheral but the master component
of the Audio Domain.

---

# 2. Functional Role

The ADAU1467 performs:

- DSP execution
- audio mixing
- signal routing
- sample rate management
- digital audio synchronization

The ESP32-S3 configures the ADAU1467 but does not process real-time audio.

Architecture:

ESP32-S3

|
|

SPI

|

ADAU1467

|
|

I2S

Audio Peripherals

---

# 3. Power Architecture

The ADAU1467 requires separated power domains.

Main domains:

Digital Supply

DVDD

|

Digital core

Analog Supply

AVDD

|

PLL and analog sections

Interface Supply

IOVDD

|

Digital interfaces

Power design rules:

- local decoupling on every supply pin
- clean analog supply
- short return paths
- separation between noisy digital regulators and audio rails

The ADAU1467 power domains must be integrated with the HubAudio power
architecture.

---

# 4. Master Clock Architecture

The ADAU1467 uses an external reference clock.

Target audio clock family:

12.288 MHz

48 kHz × 256

Clock chain:

12.288 MHz Reference

    |

 ADAU1467

    |

Internal PLL

    |

Audio Clock Domain

    |

MCLK / BCLK / LRCLK

The ADAU1467 defines the timing reference of the Audio Domain.

---

# 5. Clock Distribution

The ADAU1467 clock output can be distributed using a dedicated clock buffer.

             ADAU1467

          Clock Master

                |

               MCLK

                |

         PCS2P2309NZ

          Clock Buffer

    +-----------+-----------+

    |           |           |

 CODEC       BT       Radio

The PCS2P2309NZ provides fan-out and signal integrity improvement.

It does not generate the audio clock.

---

# 6. SPI Control Interface

The ADAU1467 provides an SPI control interface.

Connection:

ESP32-S3

SPI MASTER

  |

  |

ADAU1467

SPI SLAVE

Used for:

- configuration
- parameter update
- status monitoring

---

# 7. Self Boot EEPROM

The ADAU1467 supports self boot from external EEPROM.

HubAudio implementation:

ADAU1467

SPI MASTER

  |

25AA1024 EEPROM

  |

DSP Program

During normal operation:

- ESP32 configures the ADAU1467
- ADAU1467 manages its DSP memory

The EEPROM remains part of the Audio Processor domain.

---

# 8. Serial Audio Interfaces

The ADAU1467 provides multiple serial audio ports.

HubAudio allocation:

Inputs:

SDATA_IN0

ESP32-S3

SDATA_IN1

Si4684

SDATA_IN2

Optical DECODEC

SDATA_IN3

Bluetooth RX

Outputs:

SDATA_OUT0

CODEC

SDATA_OUT1

Bluetooth TX

SDATA_OUT2

Optical ENCODEC

The ADAU1467 operates as audio timing master.

---

# 9. Boot Sequence

Power ON

|

ESP32-S3 startup

|

Configure ADAU1467

|

ADAU1467 loads DSP program

|

Audio clocks enabled

|

Audio peripherals synchronized

|

System ready

---

# 10. PCB Design Requirements

Critical signals:

- MCLK
- BCLK
- LRCLK
- SPI
- I2S DATA

Layout rules:

- continuous ground reference
- short clock traces
- avoid RF proximity
- local decoupling
- controlled return currents

The ADAU1467 section should be treated as a high-performance mixed-signal
audio subsystem.

---

# 11. Design Philosophy

The ADAU1467 is the conductor of the HubAudio orchestra.

The ESP32-S3 provides instructions.

The peripherals provide instruments.

The ADAU1467 defines timing, routing and processing.

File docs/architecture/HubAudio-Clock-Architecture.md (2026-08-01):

# HubAudio Clock Architecture

- Status: Draft
- Date: 2026-08-01
- Document Type: Architecture Specification

# 1. Overview

The HubAudio architecture defines a centralized audio timing domain.

The Audio Processor is the master of the audio clock system.

The purpose of this architecture is to provide a single timing reference for
all digital audio devices, avoiding independent clock domains and minimizing
sample synchronization problems.

The audio clock domain is composed of:

- Master oscillator
- Audio Processor PLL and clock generation
- Clock distribution stage
- Audio peripheral clock inputs

---

# 2. Audio Clock Master

The Audio Processor is responsible for generating the audio timing reference.

The Audio Processor provides:

- DSP processing clock
- Serial audio clock generation
- I2S synchronization

Conceptually:

          Reference Clock

                |
                |

           Audio Processor

      DSP + Audio Clock Master

                |

         MCLK / BCLK / LRCLK

The Audio Processor is the timing authority of the Audio Domain.

---

# 3. Reference Frequency

The preferred audio clock family is based on 48 kHz.

The standard relationship is:

48 kHz × 256 = 12.288 MHz

The reference oscillator is therefore selected around:

12.288 MHz

This frequency is suitable for:

- streaming audio
- DAB/DAB+
- Bluetooth audio
- consumer digital audio systems

Future support for 44.1 kHz family may require:

- alternate oscillator
- PLL reconfiguration
- ASRC usage

---

# 4. Clock Distribution

The Audio Processor clock output is distributed through a dedicated clock buffer.

The Clock Buffer is used as clock distribution element.

Its role is:

- fan-out of the clock signal
- reduction of clock loading
- improved signal integrity

It does not generate the audio clock.

Architecture:

                Audio Processor

             Audio Clock Master

                   |

                  MCLK

                   |

            Clock Buffer

          Clock Distribution

      +------------+------------+
      |            |            |
      |            |            |

   Radio Receiver       BT Modules    CODEC

---

# 5. Clock Domain Devices

All digital audio peripherals belong to the same clock domain.

Expected clock relationships:

             Audio Processor

                |

    +-----------+-----------+
    |
 MCLK/BCLK/LRCLK

    |

+------+------+------+------+
| | | |
ESP32 Radio Receiver BT RX CODEC

Each device must support operation as:

- I2S slave
- external MCLK
- externally provided BCLK/LRCLK

---

# 6. Clock and Audio Data Relationship

The audio data flow is independent from control communication.

Control:

System Controller

|
|

SPI

|

Audio Processor / Radio Receiver

Audio:

Source Device

  |
  |
 I2S

  |
  |

Audio Processor

Timing:

Audio Processor

  |
  |

Clock Signals

  |
  |

Audio Peripherals

---

# 7. Design Rules

The following rules apply to the PCB:

## Clock Routing

- Clock lines must be short
- Clock return path must be continuous
- Avoid routing near RF sections
- Avoid unnecessary vias

## Power Integrity

The clock generator and buffer require:

- clean supply rails
- adequate decoupling
- low noise power domains

## Grounding

Clock signals must always reference a continuous ground plane.

---

# 8. Architectural Consequences

## Advantages

- Single audio timing reference
- No asynchronous sample drift
- Simplified DSP routing
- Professional audio architecture

## Limitations

- All peripherals must support external clocking
- Clock tree becomes a critical design element
- PCB layout quality directly affects audio performance

---

# 9. Design Philosophy

The HubAudio clock architecture follows the same principle as a musical
orchestra:

The Audio Processor is the conductor.

The Clock Buffer distributes the beat.

All audio devices perform synchronized to the same timing reference.

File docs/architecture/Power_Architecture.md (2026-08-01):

# docs/architecture/Power_Architecture.md

# Power Architecture

## Overview

HubAudio adotta un'architettura di alimentazione basata su **Power Domains** indipendenti anziché su una semplice distribuzione delle tensioni.

L'obiettivo è ottenere:

- isolamento tra domini digitali e audio;
- riduzione delle interferenze EMI;
- possibilità di power sequencing;
- monitoraggio energetico;
- elevata modularità.

L'intera distribuzione dell'alimentazione è organizzata come una gerarchia di domini funzionali.

```
                VIN
                 │
          Primary Buck 3.3V
                 │
        ┌────────┴────────┐
        │                 │
   3V3_DIGITAL      3V3_AUDIO_RAW
                          │
                     π Filter
                          │
                      INA226
                          │
                     3V3_AUDIO
```

---

## Digital Power Domain

Il dominio digitale alimenta esclusivamente i componenti di controllo.

Comprende:

- System Controller
- EEPROM
- GPIO Expander
- Display
- Bus I²C
- Logica digitale

Questo dominio è distribuito tramite un poligono dedicato sul layer di alimentazione.

---

## Audio Power Domain

Il dominio audio deriva direttamente dal convertitore principale ma viene completamente isolato tramite:

- filtro π
- monitor INA226
- distribuzione dedicata

Il dominio audio alimenta esclusivamente i dispositivi audio.

Ogni IC riceve successivamente un'alimentazione dedicata mediante un proprio Power Switch.

---

## Design Philosophy

HubAudio considera ogni sottosistema come un dominio energetico indipendente.

Ogni dominio deve poter essere:

- acceso
- spento
- monitorato
- riavviato

senza influenzare gli altri.

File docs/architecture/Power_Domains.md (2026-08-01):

# docs/architecture/Power_Domains.md

# Power Domains

## Overview

Ogni Integrated Circuit appartenente al dominio audio possiede un'alimentazione dedicata.

La distribuzione segue sempre la stessa topologia.

```
3V3_AUDIO
     │
 TPS22918
     │
 Ferrite
     │
10µF
1µF
100nF
     │
Audio IC
```

Questa architettura permette:

- isolamento elettrico
- riduzione del rumore
- power sequencing
- diagnostica

---

# Audio Processor Domain

```
3V3_AUDIO
      │
 TPS22918
      │
 Ferrite
      │
 AVDD / PVDD
```

Le tensioni locali vengono generate mediante LDO dedicati.

```
3V3_ADAU
      │
 TPS7A2018
      │
 1V8_ADAU
```

```
3V3_ADAU
      │
 TPS7A2012
      │
 1V2_ADAU
```

---

# Radio Receiver Domain

```
3V3_AUDIO
      │
 TPS22918
      │
 Ferrite
      │
 Si4684
```

---

# Bluetooth Domain

```
3V3_AUDIO
      │
 TPS22918
      │
 Ferrite
      │
 Bluetooth Module
```

---

# Future Domains

L'architettura permette di aggiungere ulteriori domini senza modificare quelli esistenti.

Esempi:

- DAC
- ADC
- SPDIF
- HDMI Audio
- DSP aggiuntivi

Ogni nuovo dominio segue la medesima struttura.

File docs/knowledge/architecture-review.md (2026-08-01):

# HubAudio Architecture Report

## adr/ADR-001-ADAU1467-Audio-Domain-Master.md

- Line 1: `ADAU1467` → `Audio Processor`
- Line 12: `ESP32-S3` → `System Controller`
- Line 13: `Si4684` → `Radio Receiver`
- Line 25: `ADAU1467` → `Audio Processor`
- Line 29: `ADAU1467` → `Audio Processor`
- Line 31: `ADAU1467` → `Audio Processor`
- Line 40: `ADAU1467` → `Audio Processor`
- Line 42: `ESP32-S3` → `System Controller`
- Line 43: `ESP32-S3` → `System Controller`
- Line 74: `ADAU1467` → `Audio Processor`

## adr/ADR-002-SPI-Control-Architecture.md

- Line 14: `ESP32-S3` → `System Controller`
- Line 15: `ADAU1467` → `Audio Processor`
- Line 16: `Si4684` → `Radio Receiver`
- Line 28: `ESP32-S3` → `System Controller`
- Line 30: `ADAU1467` → `Audio Processor`
- Line 30: `Si4684` → `Radio Receiver`
- Line 40: `ESP32-S3` → `System Controller`
- Line 47: `ADAU1467` → `Audio Processor`
- Line 47: `Si4684` → `Radio Receiver`
- Line 51: `ADAU1467` → `Audio Processor`
- Line 53: `ADAU1467` → `Audio Processor`
- Line 56: `ADAU1467` → `Audio Processor`
- Line 62: `25AA1024` → `Audio EEPROM`
- Line 66: `ADAU1467` → `Audio Processor`
- Line 66: `ESP32-S3` → `System Controller`
- Line 70: `Si4684` → `Radio Receiver`
- Line 72: `Si4684` → `Radio Receiver`
- Line 75: `ESP32-S3` → `System Controller`
- Line 81: `Si4684` → `Radio Receiver`
- Line 91: `ESP32-S3` → `System Controller`
- Line 92: `Si4684` → `Radio Receiver`
- Line 111: `ESP32-S3` → `System Controller`

## adr/ADR-003-I2S-Audio-Routing-Architecture.md

- Line 13: `ESP32-S3` → `System Controller`
- Line 14: `Si4684` → `Radio Receiver`
- Line 28: `ADAU1467` → `Audio Processor`
- Line 38: `ADAU1467` → `Audio Processor`
- Line 44: `ADAU1467` → `Audio Processor`
- Line 46: `ESP32-S3` → `System Controller`
- Line 47: `Si4684` → `Radio Receiver`
- Line 52: `ESP32-S3` → `System Controller`
- Line 53: `Si4684` → `Radio Receiver`
- Line 54: `ADAU1467` → `Audio Processor`
- Line 60: `ADAU1467` → `Audio Processor`
- Line 67: `ADAU1467` → `Audio Processor`
- Line 76: `ADAU1467` → `Audio Processor`
- Line 108: `ADAU1467` → `Audio Processor`

## adr/ADR-004-Power-Domain-Architecture.md

- Line 10: `ESP32-S3` → `System Controller`

## architecture/HubAudio-Clock-Architecture.md

- Line 12: `ADAU1467` → `Audio Processor`
- Line 21: `ADAU1467` → `Audio Processor`
- Line 30: `ADAU1467` → `Audio Processor`
- Line 32: `ADAU1467` → `Audio Processor`
- Line 46: `ADAU1467` → `Audio Processor`
- Line 54: `ADAU1467` → `Audio Processor`
- Line 94: `ADAU1467` → `Audio Processor`
- Line 96: `PCS2P2309NZ` → `Clock Buffer`
- Line 110: `ADAU1467` → `Audio Processor`
- Line 120: `PCS2P2309NZ` → `Clock Buffer`
- Line 128: `Si4684` → `Radio Receiver`
- Line 138: `ADAU1467` → `Audio Processor`
- Line 150: `Si4684` → `Radio Receiver`
- Line 170: `ESP32-S3` → `System Controller`
- Line 179: `ADAU1467` → `Audio Processor`
- Line 179: `Si4684` → `Radio Receiver`
- Line 195: `ADAU1467` → `Audio Processor`
- Line 201: `ADAU1467` → `Audio Processor`
- Line 269: `ADAU1467` → `Audio Processor`
- Line 271: `PCS2P2309NZ` → `Clock Buffer`

## architecture/HubAudio-I2S-Architecture.md

- Line 13: `ADAU1467` → `Audio Processor`
- Line 21: `ADAU1467` → `Audio Processor`
- Line 29: `ESP32-S3` → `System Controller`
- Line 38: `ESP32-S3` → `System Controller`
- Line 39: `Si4684` → `Radio Receiver`
- Line 47: `ADAU1467` → `Audio Processor`
- Line 61: `ADAU1467` → `Audio Processor`
- Line 73: `ADAU1467` → `Audio Processor`
- Line 85: `Si4684` → `Radio Receiver`
- Line 91: `ADAU1467` → `Audio Processor`
- Line 97: `ESP32-S3` → `System Controller`
- Line 98: `Si4684` → `Radio Receiver`
- Line 103: `ESP32-S3` → `System Controller`
- Line 105: `ESP32-S3` → `System Controller`
- Line 110: `ESP32-S3` → `System Controller`
- Line 117: `ADAU1467` → `Audio Processor`
- Line 120: `ESP32-S3` → `System Controller`
- Line 122: `ADAU1467` → `Audio Processor`
- Line 127: `Si4684` → `Radio Receiver`
- Line 129: `Si4684` → `Radio Receiver`
- Line 132: `Si4684` → `Radio Receiver`
- Line 139: `ADAU1467` → `Audio Processor`
- Line 142: `Si4684` → `Radio Receiver`
- Line 169: `ADAU1467` → `Audio Processor`
- Line 193: `ADAU1467` → `Audio Processor`
- Line 203: `ADAU1467` → `Audio Processor`
- Line 216: `ADAU1467` → `Audio Processor`
- Line 235: `ADAU1467` → `Audio Processor`
- Line 254: `ADAU1467` → `Audio Processor`
- Line 272: `ADAU1467` → `Audio Processor`
- Line 328: `ADAU1467` → `Audio Processor`

## architecture/HubAudio-SPI-Architecture.md

- Line 29: `ESP32-S3` → `System Controller`
- Line 40: `ADAU1467` → `Audio Processor`
- Line 40: `Si4684` → `Radio Receiver`
- Line 48: `ESP32-S3` → `System Controller`
- Line 50: `ESP32-S3` → `System Controller`
- Line 61: `ESP32-S3` → `System Controller`
- Line 63: `ESP32-S3` → `System Controller`
- Line 71: `ADAU1467` → `Audio Processor`
- Line 71: `Si4684` → `Radio Receiver`
- Line 81: `ADAU1467` → `Audio Processor`
- Line 83: `ADAU1467` → `Audio Processor`
- Line 85: `ESP32-S3` → `System Controller`
- Line 93: `ADAU1467` → `Audio Processor`
- Line 95: `ADAU1467` → `Audio Processor`
- Line 103: `25AA1024` → `Audio EEPROM`
- Line 108: `ESP32-S3` → `System Controller`
- Line 110: `ADAU1467` → `Audio Processor`
- Line 115: `Si4684` → `Radio Receiver`
- Line 117: `ESP32-S3` → `System Controller`
- Line 117: `Si4684` → `Radio Receiver`
- Line 119: `ESP32-S3` → `System Controller`
- Line 127: `ESP32-S3` → `System Controller`
- Line 133: `Si4684` → `Radio Receiver`
- Line 144: `Si4684` → `Radio Receiver`
- Line 155: `ESP32-S3` → `System Controller`
- Line 165: `ADAU1467` → `Audio Processor`
- Line 165: `Si4684` → `Radio Receiver`
- Line 189: `ESP32-S3` → `System Controller`
- Line 197: `ADAU1467` → `Audio Processor`
- Line 200: `25AA1024` → `Audio EEPROM`
- Line 204: `Si4684` → `Radio Receiver`
- Line 215: `ADAU1467` → `Audio Processor`
- Line 227: `ESP32-S3` → `System Controller`
- Line 252: `ADAU1467` → `Audio Processor`
- Line 287: `ESP32-S3` → `System Controller`
- Line 289: `ADAU1467` → `Audio Processor`
- Line 291: `Si4684` → `Radio Receiver`

## architecture/HubAudio-System-Architecture.md

- Line 24: `ESP32-S3` → `System Controller`
- Line 26: `ADAU1467` → `Audio Processor`
- Line 42: `ESP32-S3` → `System Controller`
- Line 58: `ADAU1467` → `Audio Processor`
- Line 58: `Si4684` → `Radio Receiver`
- Line 73: `Si4684` → `Radio Receiver`
- Line 77: `ADAU1467` → `Audio Processor`
- Line 115: `ESP32-S3` → `System Controller`
- Line 131: `ESP32-S3` → `System Controller`
- Line 150: `ADAU1467` → `Audio Processor`
- Line 152: `ADAU1467` → `Audio Processor`
- Line 165: `ESP32-S3` → `System Controller`
- Line 166: `Si4684` → `Radio Receiver`
- Line 194: `ADAU1467` → `Audio Processor`
- Line 205: `ADAU1467` → `Audio Processor`
- Line 221: `Si4684` → `Radio Receiver`
- Line 229: `ESP32-S3` → `System Controller`
- Line 252: `ADAU1467` → `Audio Processor`
- Line 278: `Si4684` → `Radio Receiver`
- Line 321: `ADAU1467` → `Audio Processor`
- Line 328: `ADAU1467` → `Audio Processor`
- Line 362: `ADAU1467` → `Audio Processor`
- Line 369: `ADAU1467` → `Audio Processor`
- Line 392: `ESP32-S3` → `System Controller`
- Line 394: `ADAU1467` → `Audio Processor`
- Line 451: `ESP32-S3` → `System Controller`
- Line 457: `ADAU1467` → `Audio Processor`
- Line 463: `ADAU1467` → `Audio Processor`

## architecture/Power_Architecture.md

- Line 29: `ESP32-S3` → `System Controller`

## architecture/Power_Domains.md

- Line 22: `ADAU1467` → `Audio Processor`
- Line 34: `Si4684` → `Radio Receiver`

---

Files checked: 16

Issues found: 166

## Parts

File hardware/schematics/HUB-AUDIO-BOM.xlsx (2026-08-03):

No. | Quantity | Comment | Designator | Footprint | JLCPCB Part Class | LCSC Part Name | Manufacturer Part | Category | LCSC Stock | Datasheet | Device | Name
1 | 6 | 1uF | C1,C24,C29,C35,C37,C39 | C0402 | Basic Part,Extended Part | 1uF ±10% 25V,1uF ±10% 50V | CL05A105KA5NQNC,HGC0402R5105K500NTEJ | Capacitors:Multilayer Ceramic Capacitors MLCC - SMD/SMT |  | https://item.szlcsc.com/datasheet/CL05A105KA5NQNC/53938.html,https://item.szlcsc.com/datasheet/HGC0402R5105K500NTEJ/8532795.html | CL05A105KA5NQNC,HGC0402R5105K500NTEJ | 1uF
2 | 6 | 100nF | C2,C3,C5,C22,C23,C109 | C0402 | Basic Part | 100nF ±10% 50V | CL05B104KB54PNC | Capacitors:Multilayer Ceramic Capacitors MLCC - SMD/SMT |  | https://item.szlcsc.com/datasheet/CL05B104KB54PNC/291005.html | CL05B104KB54PNC | 100nF
3 | 3 | 22uF | C4,C9,C10 | C0805 | Basic Part,Extended Part | 22uF ±20% 10V,22uF ±20% 25V | CL21A226MAQNNNE,CL21A226MPQNNNE | Capacitors:Multilayer Ceramic Capacitors MLCC - SMD/SMT |  | https://item.szlcsc.com/datasheet/CL21A226MAQNNNE/46786.html,https://item.szlcsc.com/datasheet/CL21A226MPQNNNE/30029.html | CL21A226MAQNNNE,CL21A226MPQNNNE | 22uF
4 | 42 | 100nF | C6,C8,C13,C14,C19,C20,C41,C50,C56,C57,C61,C63,C66,C69,C72,C73,C76,C77,C79,C80,C83,C89,C95,C101,C107,C110,C115,C120,C121,C124,C125,C132,C133,C136,C138,C141,C143,C145,C147,C153,C159,C165 | C0805 | Extended Part | 100nF ±10% 50V | 0805X7R104K500NT,TCC0805X7R104K500DT | Capacitors:Multilayer Ceramic Capacitors MLCC - SMD/SMT |  | https://item.szlcsc.com/datasheet/0805X7R104K500NT/50843341.html,https://item.szlcsc.com/datasheet/TCC0805X7R104K500DT/268703.html | 0805X7R104K500NT,TCC0805X7R104K500DT | 100nF
5 | 27 | 10uF | C7,C11,C21,C47,C48,C53,C54,C86,C87,C92,C93,C98,C99,C104,C105,C108,C117,C118,C129,C130,C139,C150,C151,C156,C157,C162,C163 | C0805 | Basic Part | 10uF ±10% 25V,10uF ±10% 50V | CL21A106KAYNNNE,GRM21BR61H106KE43L | Capacitors:Multilayer Ceramic Capacitors MLCC - SMD/SMT |  | https://item.szlcsc.com/datasheet/CL21A106KAYNNNE/16532.html,https://item.szlcsc.com/datasheet/GRM21BR61H106KE43L/439567.html | CL21A106KAYNNNE_C15850,GRM21BR61H106KE43L | 10uF
6 | 32 | 1uF | C12,C15,C16,C17,C18,C45,C49,C51,C55,C84,C88,C90,C94,C96,C100,C102,C106,C113,C119,C127,C131,C137,C140,C142,C144,C146,C148,C152,C154,C158,C160,C164 | C0805 | Basic Part | 1uF ±10% 50V | CL21B105KBFNNNE | Capacitors:Multilayer Ceramic Capacitors MLCC - SMD/SMT |  | https://item.szlcsc.com/datasheet/CL21B105KBFNNNE/29074.html | CL21B105KBFNNNE | 1uF
7 | 1 | 470nF | C25 | C0805 | Extended Part | 470nF ±20% 50V | TCC0805X7R474M500FT | Capacitors:Multilayer Ceramic Capacitors MLCC - SMD/SMT |  | https://item.szlcsc.com/datasheet/TCC0805X7R474M500FT/6236335.html | TCC0805X7R474M500FT | 470nF
8 | 3 | 8.2pF | C26,C27,C33 | C0402 | Extended Part | 8.2pF 50V | CSA0402C0G8R2B500GT | Capacitors:Multilayer Ceramic Capacitors MLCC - SMD/SMT |  | https://item.szlcsc.com/datasheet/CSA0402C0G8R2B500GT/50922894.html | CSA0402C0G8R2B500GT | 8.2pF
9 | 3 | 2.2nF | C28,C34,C36 | C0402 | Extended Part | 2.2nF ±10% 25V | CC0402KRX7R8BB222 | Capacitors:Multilayer Ceramic Capacitors MLCC - SMD/SMT |  | https://atta.szlcsc.com/upload/public/pdf/source/20200615/C541386_7B176CE5F84559F9CFB8AA143269F5F2.pdf | CC0402KRX7R8BB222 | 2.2nF
10 | 1 | 8.2pF | C30 | C0603 | Extended Part | ±0.25pF 8.2pF 50V | CC0603CPNPO9BN8R2 | Capacitors:Multilayer Ceramic Capacitors MLCC - SMD/SMT |  | https://item.szlcsc.com/datasheet/CC0603CPNPO9BN8R2/4415749.html | CC0603CPNPO9BN8R2 | 8.2pF
11 | 1 | 2.2nF | C31 | C0603 | Basic Part | 2.2nF ±10% 50V | 0603B222K500NT | Capacitors:Multilayer Ceramic Capacitors MLCC - SMD/SMT |  | https://item.szlcsc.com/datasheet/0603B222K500NT/1956.html | 0603B222K500NT | 2.2nF
12 | 1 | 1uF | C32 | C0603 | Basic Part | 1uF ±10% 50V | CL10A105KB8NNNC | Capacitors:Multilayer Ceramic Capacitors MLCC - SMD/SMT |  | https://item.szlcsc.com/datasheet/CL10A105KB8NNNC/16531.html | CL10A105KB8NNNC | 1uF
13 | 2 | 15pF | C38,C40 | C0402 | Basic Part | 15pF ±5% 50V | 0402CG150J500NT | Capacitors:Multilayer Ceramic Capacitors MLCC - SMD/SMT |  | https://item.szlcsc.com/datasheet/0402CG150J500NT/1900.html | 0402CG150J500NT | 15pF
14 | 1 | 33pF | C42 | C0402 | Extended Part | 33pF ±5% 50V | CL05C330JB5NNNC | Capacitors:Multilayer Ceramic Capacitors MLCC - SMD/SMT |  | https://item.szlcsc.com/datasheet/CL05C330JB5NNNC/71562.html | CL05C330JB5NNNC | 33pF
15 | 1 | 2.7pF | C43 | C0402 | Extended Part | ±0.1pF 2.7pF 50V | GJM1555C1H2R7BB01D | Capacitors:Multilayer Ceramic Capacitors MLCC - SMD/SMT |  | https://item.szlcsc.com/datasheet/GJM1555C1H2R7BB01D/78031.html | GJM1555C1H2R7BB01D | 2.7pF
16 | 1 | 18pF | C44 | C0805 | Extended Part | 18pF ±5% 50V | 0805CG180J500NT | Capacitors:Multilayer Ceramic Capacitors MLCC - SMD/SMT |  | https://item.szlcsc.com/datasheet/0805CG180J500NT/2149.html | 0805CG180J500NT | 18pF
17 | 11 | 1nF | C46,C52,C85,C91,C97,C103,C116,C128,C149,C155,C161 | C0805 | Extended Part | 1nF ±10% 50V | CC0805KRX7R9BB102 | Capacitors:Multilayer Ceramic Capacitors MLCC - SMD/SMT |  | https://item.szlcsc.com/datasheet/CC0805KRX7R9BB102/95319.html | CC0805KRX7R9BB102 | 1nF
18 | 11 | 10nF | C58,C59,C64,C67,C70,C71,C74,C75,C78,C81,C82 | C0805 | Extended Part | 10nF ±10% 50V | TCC0805X7R103K500DT | Capacitors:Multilayer Ceramic Capacitors MLCC - SMD/SMT |  | https://item.szlcsc.com/datasheet/TCC0805X7R103K500DT/268699.html | TCC0805X7R103K500DT | 10nF
19 | 1 | 5.6nF | C60 | C0805 | Extended Part | 5.6nF ±5% 50V | GRM2195C1H562JA01D | Capacitors:Multilayer Ceramic Capacitors MLCC - SMD/SMT |  | https://item.szlcsc.com/datasheet/GRM2195C1H562JA01D/78194.html | GRM2195C1H562JA01D | 5.6nF
20 | 1 | 150pF | C62 | C0805 | Extended Part | 150pF ±5% 50V | CC0805JRNPO9BN151 | Capacitors:Multilayer Ceramic Capacitors MLCC - SMD/SMT |  | https://item.szlcsc.com/datasheet/CC0805JRNPO9BN151/108327.html | CC0805JRNPO9BN151 | 150pF
21 | 4 | 22pF | C65,C68,C112,C123 | C0805 | Basic Part,Extended Part | 22pF ±1% 50V,22pF ±5% 50V | 0805CG220F500NT,CL21C220JBANNNC | Capacitors:Multilayer Ceramic Capacitors MLCC - SMD/SMT |  | https://item.szlcsc.com/datasheet/0805CG220F500NT/208470.html,https://item.szlcsc.com/datasheet/CL21C220JBANNNC/2156.html | 0805CG220F500NT,CL21C220JBANNNC | 22pF
22 | 2 | 33pF | C111,C122 | C0805 | Extended Part | 33pF ±5% 50V | CC0805JRNPO9BN330 | Capacitors:Multilayer Ceramic Capacitors MLCC - SMD/SMT |  | https://item.szlcsc.com/datasheet/CC0805JRNPO9BN330/108331.html | CC0805JRNPO9BN330 | 33pF
23 | 2 | 4.7uF | C114,C126 | C0805 | Basic Part | 4.7uF ±10% 25V | CL21A475KAQNNNE | Capacitors:Multilayer Ceramic Capacitors MLCC - SMD/SMT |  | https://item.szlcsc.com/datasheet/CL21A475KAQNNNE/2131.html | CL21A475KAQNNNE | 4.7uF
24 | 2 | 0.47pF | C134,C135 | C0603 | Extended Part | 0.47pF 50V ±0.25pF | CC0603CRNPO9BNR47 | Capacitors:Multilayer Ceramic Capacitors MLCC - SMD/SMT |  | https://atta.szlcsc.com/upload/public/pdf/source/20200423/C519378_A803D508FCA1C9E05222E3A32899E571.pdf | CC0603CRNPO9BNR47 | 0.47pF
25 | 1 | ZX-XH2.54-4PWZ | CN1 | CONN-TH_4P-P2.50_ZX-XH2.54-4PWZ | Extended Part | 1x4P 间距:2.5mm 弯插 系列:XH | ZX-XH2.54-4PWZ | Connectors:Wire To Board Connector |  | https://item.szlcsc.com/datasheet/ZX-XH2.54-4PWZ/8427560.html | ZX-XH2.54-4PWZ | ZX-XH2.54-4PWZ
26 | 3 | PJ-342 | CN2,LINE_IN1,LINE_OUT1 | AUDIO-SMD_PJ-342_C668606 | Extended Part | PJ-342双柱镀金编带 CCD | PJ-342 | Connectors:Audio Connectors |  | https://item.szlcsc.com/datasheet/PJ-342/698549.html | PJ-342_C668606 | PJ-342
27 | 1 | SS34 | D1 | SMA_L4.3-W2.6-LS5.2-RD | Basic Part | 电压:40V 电流:3A | SS34 | Diodes:Schottky Diodes |  | https://item.szlcsc.com/datasheet/SS34/9178.html | SS34_C8678 | SS34
28 | 1 | SRV05-4 | D2 | SOT-23-6_L2.9-W1.6-P0.95-LS2.8-BL | Extended Part | 单向ESD 5V截止 峰值脉冲电流：3A | SRV05-4 | Circuit Protection:ESD and Surge Protection (TVS/ESD) |  | https://item.szlcsc.com/datasheet/SRV05-4/581825.html | SRV05-4_C558418 | SRV05-4
29 | 1 | BAV99,215 | D3 | SOT-23-3_L2.9-W1.6-P1.90-LS2.8-BR | Basic Part | 100V 215mA | BAV99,215 | Diodes:Switching Diodes |  | https://item.szlcsc.com/datasheet/BAV99%252C215/2877.html | BAV99,215 | BAV99,215
30 | 2 | CM1213-04SO | D4,D5 | SOT-26_L3.0-W1.6-P0.95-LS2.8-BL | Extended Part | 低电容TVS二极管阵列 TVS 5V截止 | CM1213-04SO | Circuit Protection:ESD and Surge Protection (TVS/ESD) |  | https://item.szlcsc.com/datasheet/CM1213-04SO/6027026.html | CM1213-04SO | CM1213-04SO
31 | 2 | MMZ1608A252BTA00 | FB1,FB2 | L0603 | Extended Part | 单路 0603磁珠 阻抗2.5kΩ@100MHz | MMZ1608A252BTA00 | Filters:Ferrite Beads |  | https://item.szlcsc.com/datasheet/MMZ1608A252BTA00/263521.html | MMZ1608A252BTA00 | MMZ1608A252BTA00
32 | 1 | HFBR-2521Z | FC1 | COMM-TH_HFBR_2521ETZ | Extended Part | 光纤连接组件 | HFBR-2521Z | Optoelectronics:Fiber Optical Transceivers |  | https://item.szlcsc.com/datasheet/HFBR-2521Z/200124.html | HFBR-2521Z | HFBR-2521Z
33 | 1 | HX PH254-01-02-Z-L11.5 male header connector | H1 | HDR-TH_2P-P2.54-V-M | Extended Part | 1x2P 间距:2.54mm 方针 直插 | HX PH254-01-02-Z-L11.5 male header connector | Connectors:Pin Headers |  | https://item.szlcsc.com/datasheet/HX%2520PH254-01-02-Z-L11.5%2520male%2520header%2520connector/54760435.html | HX PH254-01-02-Z-L11.5 male header connector | HX PH254-01-02-Z-L11.5 male header connector
34 | 12 | BLM21PG121SN1D | L1,L7,L8,L9,L10,L11,L12,L13,L15,L16,L17,L18 | L0805 | Extended Part | 单路 0805磁珠 阻抗120Ω@100MHz | BLM21PG121SN1D | Filters:Ferrite Beads |  | https://item.szlcsc.com/datasheet/BLM21PG121SN1D/80520.html | BLM21PG121SN1D | BLM21PG121SN1D
35 | 1 | 18nH | L2 | L0402-RD | Extended Part | 18nH ±5% | LQG15HS18NJ02D | Inductors, Coils, Chokes:Inductors (SMD) |  | https://atta.szlcsc.com/upload/public/pdf/source/20180612/C185484_14F678484DDF036353DC67B6265A9221.pdf | LQG15HS18NJ02D | 18nH
36 | 1 | 120nH | L3 | L0402 | Extended Part | 120nH ±5% | LQW15ANR12J00D | Inductors, Coils, Chokes:Power Inductors |  | https://item.szlcsc.com/datasheet/LQW15ANR12J00D/114358.html | LQW15ANR12J00D | 120nH
37 | 1 | 22nH | L4 | IND-SMD_L1.0-W0.5-2 | Extended Part | 22nH ±3% | LQW15AN22NH00D | Inductors, Coils, Chokes:Power Inductors |  | https://item.szlcsc.com/datasheet/LQW15AN22NH00D/738551.html | LQW15AN22NH00D | 22nH
38 | 1 | 36nH | L5 | L0603 | Extended Part | 36nH ±2% | LQW18AN36NG00D | Inductors, Coils, Chokes:Power Inductors |  | https://item.szlcsc.com/datasheet/LQW18AN36NG00D/114359.html | LQW18AN36NG00D | 36nH
39 | 1 | 100nH | L6 | L0603 | Extended Part | 100nH ±5% | LQW18ANR10J00D | Inductors, Coils, Chokes:Power Inductors |  | https://item.szlcsc.com/datasheet/LQW18ANR10J00D/99298.html | LQW18ANR10J00D | 100nH
40 | 1 | LSQNB160808T470M | L14 | L0603 | Extended Part | 适用于通用电子设备的绕线铁氧体功率电感器 | LSQNB160808T470M | Inductors, Coils, Chokes:Power Inductors |  | https://item.szlcsc.com/datasheet/LSQNB160808T470M/6245515.html | LSQNB160808T470M | LSQNB160808T470M
41 | 11 | TPS22918DBVR | PW1,PW2,PW3,PW4,PW5,PW6,PW7,PW8,PW9,PW10,PW11 | SOT-23-6_L2.9-W1.6-P0.95-LS2.8-BR | Extended Part | 5.5V、2A、导通电阻的负载开关 | TPS22918DBVR | Power Management (PMIC):Power Distribution Switches |  | https://www.ti.com/cn/lit/gpn/tps22918 | TPS22918DBVR | TPS22918DBVR
42 | 5 | 10kΩ | R1,R6,R7,R8,R31 | R0402 | Basic Part | 10kΩ ±1% 62.5mW 厚膜电阻 | 0402WGF1002TCE | Resistors:Chip Resistor - Surface Mount |  | https://item.szlcsc.com/datasheet/0402WGF1002TCE/26487.html | 0402WGF1002TCE | 10kΩ
43 | 2 | 2kΩ | R2,R3 | R0402 | Basic Part | 2kΩ ±1% 62.5mW 厚膜电阻 | 0402WGF2001TCE | Resistors:Chip Resistor - Surface Mount |  | https://atta.szlcsc.com/upload/public/pdf/source/20200306/C422600_1E6D84923E4A46A82E41ADD87F860B5C.pdf | 0402WGF2001TCE | 2kΩ
44 | 2 | 5.1kΩ | R4,R5 | R0402 | Basic Part | 5.1kΩ ±1% 62.5mW 厚膜电阻 | 0402WGF5101TCE | Resistors:Chip Resistor - Surface Mount |  | https://item.szlcsc.com/datasheet/0402WGF5101TCE/26648.html | 0402WGF5101TCE | 5.1kΩ
45 | 2 | 100mΩ | R9,R10 | R2512 | Extended Part | 100mΩ ±1% 2W 合金电阻 | RLP25FEER100 | Resistors:Current Sense Resistors / Shunt Resistors |  | https://item.szlcsc.com/datasheet/RLP25FEER100/171967.html | RLP25FEER100 | 100mΩ
46 | 2 | 1kΩ | R11,R15 | R0805 | Basic Part | 1kΩ ±1% 125mW 厚膜电阻 | 0805W8F1001T5E | Resistors:Chip Resistor - Surface Mount |  | https://atta.szlcsc.com/upload/public/pdf/source/20200306/C422600_1E6D84923E4A46A82E41ADD87F860B5C.pdf | 0805W8F1001T5E | 1kΩ
47 | 19 | 10kΩ | R12,R13,R14,R16,R18,R19,R20,R21,R22,R23,R24,R26,R27,R28,R29,R30,R32,R34,R35 | R0805 | Basic Part,Extended Part | 10kΩ ±1% 125mW 厚膜电阻,10kΩ ±5% 125mW 厚膜电阻 | 0805W8F1002T5E,FRC0805J103TS | Resistors:Chip Resistor - Surface Mount |  | https://item.szlcsc.com/datasheet/0805W8F1002T5E/18102.html | 0805W8F1002T5E,FRC0805J103TS | 10kΩ
48 | 1 | 10mΩ | R17 | R1206 | Extended Part | 10mΩ ±1% 1W 合金电阻 | FMF06FTHR010-LH | Resistors:Current Sense Resistors / Shunt Resistors |  | https://item.szlcsc.com/datasheet/FMF06FTHR010-LH/106577.html | FMF06FTHR010-LH_C105362 | 10mΩ
49 | 1 | 4.3kΩ | R25 | R0805 | Extended Part | 4.3kΩ ±1% 125mW 厚膜电阻 | 0805W8F4301T5E | Resistors:Chip Resistor - Surface Mount |  | https://item.szlcsc.com/datasheet/0805W8F4301T5E/18355.html | 0805W8F4301T5E | 4.3kΩ
50 | 1 | 56Ω | R33 | R0805 | Extended Part | 56Ω ±1% 125mW 厚膜电阻 | FRC0805F56R0TS | Resistors:Chip Resistor - Surface Mount |  | https://item.szlcsc.com/datasheet/FRC0805F56R0TS/3267140.html | FRC0805F56R0TS | 56Ω
51 | 1 | 18GHz | RF1 | SMA-TH_733910083 | Extended Part | 内孔 SMA 弯头 | 733910083 | Connectors:Coaxial Connectors (RF) |  | https://www.molex.com/content/dam/molex/molex-dot-com/products/automated/en-us/salesdrawingpdf/733/73391/733910083_sd.pdf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\ | 733910083 | 18GHz
52 | 4 | 33Ω | RN1,RN2,RN3,RN4 | RES-ARRAY-SMD_0603-4P-L1.6-W1.6-BL | Extended Part | 33Ω ±5% | EXB-V4V330JV | Resistors:Resistor Networks, Arrays |  | https://item.szlcsc.com/datasheet/EXB-V4V330JV/1822495.html | EXB-V4V330JV | 33Ω
53 | 1 | 33Ω | RN5 | RES-ARRAY-SMD_0603-8P-L3.2-W1.6-BL | Extended Part | 33Ω ±5% | 4D03WGJ0330T5E | Resistors:Resistor Networks, Arrays |  | https://atta.szlcsc.com/upload/public/pdf/source/20191224/C474318_2527498AE30E813171187CCD28401A71.pdf | 4D03WGJ0330T5E | 33Ω
54 | 2 | TS3425UA-3x4x2.5-160 | SW1,SW2 | SW-SMD_4P-L4.2-W3.4_HX-TS3425PA-250GF-B | Extended Part | 4.2mm*3.2mm 12V 50mA | TS3425UA-3x4x2.5-160 | Switches:Tactile Switches |  | https://item.szlcsc.com/datasheet/TS3425UA-3x4x2.5-160/54633800.html | TS3425UA-3x4x2.5-160 | TS3425UA-3x4x2.5-160
55 | 1 | 2.4GHz | U1 | WIRELM-SMD_ESP32-S3-WROOM-1 | Extended Part | 不带固件 通用型Wi-Fi+低功耗蓝牙MCU模组 | ESP32-S3-WROOM-1-N16 | IoT/Communication Modules:WiFi Modules |  | https://item.szlcsc.com/datasheet/ESP32-S3-WROOM-1-N16/3198297.html | ESP32-S3-WROOM-1-N16 | 2.4GHz
56 | 1 | 24AA025E48T-I/OT | U2 | SOT-23-6_L2.9-W1.6-P0.95-LS2.8-BR | Extended Part | 带EUI-48或EUI-64节点标识的2K I2C串行EEPROM | 24AA025E48T-I/OT | Memory:EEPROM |  | https://item.szlcsc.com/datasheet/24AA025E48T-I%252FOT/141182.html | 24AA025E48T-I/OT | 24AA025E48T-I/OT
57 | 1 | AP63203WU-7 | U3 | TSOT-26_L2.9-W1.6-P0.95-LS2.8-BL | Extended Part | 降压型 2A 3.8V~32V | AP63203WU-7 | Power Management (PMIC):DC-DC Converters |  | https://item.szlcsc.com/datasheet/AP63203WU-7/832852.html | AP63203WU-7 | AP63203WU-7
58 | 1 | 4.7uH | U4 | IND-SMD_L4.4-W4.2 | Extended Part | 4.7uH ±20% 3A | BCIHP0420SC-4R7M | Inductors, Coils, Chokes:Inductors (SMD) |  | https://item.szlcsc.com/datasheet/BCIHP0420SC-4R7M/3229076.html | BCIHP0420SC-4R7M | 4.7uH
59 | 2 | TCA9555RTWR | U5,U21 | VFQFPN-24_L4.0-W4.0-P0.50-BL-EP2.8 | Extended Part | TCA9555 低电压16位 I²C 和 SMBus I/O 扩展器，带中断输出和配置寄存器 | TCA9555RTWR | Interface:I/O Expanders |  | https://www.ti.com/cn/lit/gpn/tca9555 | TCA9555RTWR | TCA9555RTWR
60 | 1 | TPS7A2018PDQNR | U6 | X2SON-4_L1.0-W1.0-P0.65-TL-EP | Extended Part | 1.8V 300mA 6V | TPS7A2018PDQNR | Power Management (PMIC):Voltage Regulators - Linear, Low Drop Out (LDO) Regulators |  | https://www.ti.com/cn/lit/ds/symlink/tps7a20.pdf | TPS7A2018PDQNR | TPS7A2018PDQNR
61 | 1 | TPS7A2012DQNR | U7 | X2SON-4_L1.0-W1.0-P0.65-TL-EP | Extended Part | TPS7A2012DQNR | TPS7A2012DQNR | Power Management (PMIC):Voltage Regulators - Linear, Low Drop Out (LDO) Regulators |  |  | TPS7A2012DQNR | TPS7A2012DQNR
62 | 2 | INA228AIDGSR | U8,U9 | VSSOP-10_L3.0-W3.0-P0.50-LS4.9-BL | Extended Part | 85V、20位、超精密功率/能量/充电监控器，具有I²C接口 | INA228AIDGSR | Amplifiers/Comparators:Current Sense Amplifiers |  | https://www.ti.com/cn/lit/ds/symlink/ina228.pdf | INA228AIDGSR | INA228AIDGSR
63 | 1 | BQ24074RGTR | U10 | QFN-16_L3.0-W3.0-P0.50-TL-EP1.7 | Extended Part | 1.5A USB友好型锂离子电池充电器和电源路径管理IC | BQ24074RGTR | Power Management (PMIC):Battery Management |  | https://www.ti.com/cn/lit/ds/symlink/bq24074.pdf | BQ24074RGTR | BQ24074RGTR
64 | 1 | BQ27441DRZR-G1B | U11 | SON-12_L4.0-W2.5-P0.40-BL-EP | Extended Part | bq27441-G1 系统侧阻抗追踪电量计 | BQ27441DRZR-G1B | Power Management (PMIC):Battery Management |  | https://www.ti.com/cn/lit/gpn/bq27441-g1 | BQ27441DRZR-G1B | BQ27441DRZR-G1B
65 | 1 | SI4684-A10-GM | U12 | QFN-48_L7.0-W7.0-P0.50-TL-EP5.3 | Extended Part | 单芯片调频/数字音频广播/增强型数字音频广播收音机接收器 | SI4684-A10-GM | RF and Wireless:RF Transceiver ICs |  | https://item.szlcsc.com/datasheet/SI4684-A10-GM/1616887.html | SI4684-A10-GM | SI4684-A10-GM
66 | 1 | 19.2MHz | U13 | CRYSTAL-SMD_4P-L3.2-W2.5-BL | Extended Part | 19.2MHz ±10ppm 10pF | ABM8-19.200MHZ-10-1-U-T | Crystals, Oscillators, Resonators:Crystals |  | https://item.szlcsc.com/datasheet/ABM8-19.200MHZ-10-1-U-T/2078397.html | ABM8-19.200MHZ-10-1-U-T | 19.2MHz
67 | 1 | SST25WF080B-40I/SN | U14 | SOIC-8_L5.0-W4.0-P1.27-LS6.1-BL | Extended Part | 8Mbit 、1.8V、SPI串行闪存 | SST25WF080B-40I/SN | Memory:NOR FLASH |  | https://item.szlcsc.com/datasheet/SST25WF080B-40I%252FSN/666435.html | SST25WF080B-40I/SN | SST25WF080B-40I/SN
68 | 2 | 74LVC1G04GV | U15,U17 | SOT-23-5_L2.9-W1.6-P0.95-LS2.7-BR | Extended Part | 单反相器门 | 74LVC1G04GV | Logic:Inverters |  | https://item.szlcsc.com/datasheet/74LVC1G04GV/21156884.html | 74LVC1G04GV | 74LVC1G04GV
69 | 2 | TPE4259-63 | U16,U18 | SOT-363-6_L2.0-W1.3-P0.65-LS2.1-BL | Extended Part | 砷化镓 DC-3GHz 单刀双掷开关 | TPE4259-63 | RF and Wireless:RF Switches |  | https://item.szlcsc.com/datasheet/TPE4259-63/49309638.html | TPE4259-63 | TPE4259-63
70 | 1 | ADAU1467WBCPZ300 | U19 | LFCSP-88_L12.0-W12.0-P0.50-BL-EP5.3 | Extended Part | ADAU1467WBCPZ300 | ADAU1467WBCPZ300 | Embedded Processors & Controllers:Digital Signal Processors (DSP/DSC) |  | https://atta.szlcsc.com/upload/public/pdf/source/20220117/57167BD8B791C10BB3652D3E0B2A2A10.pdf | ADAU1467WBCPZ300 | ADAU1467WBCPZ300
71 | 1 | 25AA1024T-I/SM | U20 | SOIJ-8_L5.3-W5.3-P1.27-LS7.9-BL | Extended Part | 1 Mbit SPI总线串行EEPROM | 25AA1024T-I/SM | Memory:EEPROM |  | https://item.szlcsc.com/datasheet/25AA1024T-I%252FSM/2745434.html | 25AA1024T-I/SM | 25AA1024T-I/SM
72 | 1 | FSC-BT1035 | U22 | FSC-BT806 |  |  |  |  | 27 |  | FSC-BT1035 | FSC-BT1035
73 | 2 | SC16IS740IPW,128 | U23,U25 | TSSOP-16_L5.0-W4.4-P0.65-LS6.4-BL | Extended Part | 单路通用异步收发传输器（UART），具备I2C总线/SPI接口，64字节收发FIFO，内置IrDA SIR支持 | SC16IS740IPW,128 | Interface:UART |  | https://www.nxp.com.cn/docs/en/data-sheet/SC16IS740_750_760.pdf | SC16IS740IPW,128 | SC16IS740IPW,128
74 | 1 | FSC-BT1026x | U24 | Bluetooth:FSC-BT1026x |  |  |  | Bluetooth: | 27 |  | FSC-BT1026x | FSC-BT1026x
75 | 1 | SN75451BDR | U26 | SOIC-8_L5.0-W4.0-P1.27-LS6.0-BL | Extended Part | 双外设驱动器 | SN75451BDR | Logic:Buffers, Drivers, Receivers, Transceivers |  | https://www.ti.com/cn/lit/gpn/sn75453b | SN75451BDR | SN75451BDR
76 | 1 | HFBR-1521Z | U27 | CONN-TH_HFBR-1521Z | Extended Part | HFBR-1521Z | HFBR-1521Z | Optoelectronics:Fiber Optical Transceivers |  | https://item.szlcsc.com/datasheet/HFBR-1521Z/200120.html | HFBR-1521Z | HFBR-1521Z
77 | 1 | TLV320AIC3104IRHBR | U28 | HVQFN-32_L5.0-W5.0-P0.50-TL-EP | Extended Part | 用于便携式音频和电话的低功耗立体声音频编解码器 | TLV320AIC3104IRHBR | Interface:Audio Interface ICs |  | https://www.ti.com/cn/lit/gpn/tlv320aic3104 | TLV320AIC3104IRHBR | TLV320AIC3104IRHBR
78 | 1 | TYPE-C-31-M-12 | USBC1 | USB-C_SMD-TYPE-C-31-M-12_1 | Extended Part | Type-C 母 卧贴 | TYPE-C-31-M-12 | Connectors:USB Connectors |  | https://item.szlcsc.com/datasheet/TYPE-C-31-M-12/177331.html | TYPE-C-31-M-12 | TYPE-C-31-M-12
79 | 1 | 12.288MHz | X1 | CRYSTAL-SMD_4P-L3.2-W2.5-BL | Extended Part | 12.288MHz ±10ppm 10pF | SX3B12.288F1010F30 | Crystals, Oscillators, Resonators:Crystals |  | https://item.szlcsc.com/datasheet/SX3B12.288F1010F30/3151466.html | SX3B12.288F1010F30 | 12.288MHz
80 | 2 | 1.8432MHz | X2,X3 | HC-49US_L11.0-W4.6-P4.88 | Extended Part | 49U,1.8432MHz,20PF,±30ppm,500Ω,-40~+85℃±50ppm,加衬套, | 6A01843AG20UCD | Crystals, Oscillators, Resonators:Crystals |  | https://item.szlcsc.com/datasheet/6A01843AG20UCD/49560882.html | 6A01843AG20UCD | 1.8432MHz

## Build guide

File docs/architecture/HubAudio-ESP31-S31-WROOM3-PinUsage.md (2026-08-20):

# Mappatura Hardware e Pinout: ESP32-S31-WROOM-3

Questo documento raccoglie la configurazione completa e definitiva dei pin per il modulo **ESP32-S31-WROOM-3** utilizzata nel layout del PCB.

---

## 1. Tabella Definitiva Mappatura Hardware

| Periferica / Blocco | Segnale Hardware | GPIO ESP32-S31 | Pin Schema | Note e Connessioni Hardware |
| :--- | :--- | :--- | :--- | :--- |
| **ETHERNET (RMII / LAN8720A)** | `ETH_50MHZ_CLOCK` | **GPIO13** | **Pin 19** | Ingresso Clock 50 MHz da oscillatore |
| | `ETH_TXD0` | **GPIO8** | **Pin 14** | Dati TX Bit 0 |
| | `ETH_TXD1` | **GPIO9** | **Pin 15** | Dati TX Bit 1 |
| | `ETH_TXEN` | **GPIO12** | **Pin 18** | Transmit Enable |
| | `ETH_RXD0` | **GPIO19** | **Pin 25** | Dati RX Bit 0 |
| | `ETH_RXD1` | **GPIO18** | **Pin 24** | Dati RX Bit 1 |
| | `ETH_CRS_DV` | **GPIO15** | **Pin 21** | Carrier Sense / Data Valid |
| | `ETH_MDC` | **GPIO5** | **Pin 11** | Clock Gestione PHY |
| | `ETH_MDIO` | **GPIO6** | **Pin 12** | Dati Gestione PHY (Pull-up 1.5 kΩ ~ 4.7 kΩ) |
| | `ETH_RST#` | **GPIO7** | **Pin 13** | Reset Hardware LAN8720A |
| | `ETH_RXER` | **GPIO10** | **Pin 16** | Receive Error / Config. Indirizzo PHY0 |
| | `ETH_INT#` | **GPIO4** | **Pin 10** | Interruzione PHY (Pull-up 10 kΩ) |
| **SPI BUS (Master)** | `SPI_MOSI` | **GPIO2** | **Pin 6** | Dati in Uscita (Condiviso Si4684 + ADAU1467)[cite: 1] |
| | `SPI_MISO` | **GPIO3** | **Pin 7** | Dati in Ingresso (Condiviso Si4684 + ADAU1467)[cite: 1] |
| | `SPI_CLK` | **GPIO1** | **Pin 9** | Clock Serial SPI[cite: 1] |
| | `SPI_SI4684_CS` | **GPIO16** | **Pin 22** | Chip Select Radio Si4684[cite: 1] |
| | `SPI_ADAU1467_CS` | **GPIO17** | **Pin 23** | Chip Select DSP ADAU1467[cite: 1] |
| **I2C BUS (Master)** | `I2C_SDA` | **GPIO50** | **Pin 60** | (Pull-up 4.7 kΩ) |
| | `I2C_SCL` | **GPIO51** | **Pin 61** | (Pull-up 4.7 kΩ) |
| **I2S_0 (Slave)** | `I2S0_BCLK` | **GPIO42** | **Pin 52** | Bit Clock (Ingresso da Master esterno)[cite: 1] |
| | `I2S0_LRCLK` | **GPIO43** | **Pin 53** | Frame Sync / WS (Ingresso da Master)[cite: 1] |
| | `I2S0_DATA` | **GPIO44** | **Pin 54** | Dati Audio 1[cite: 1] |
| **I2S_1 (Slave)** | `I2S1_BCLK` | **GPIO46** | **Pin 56** | Bit Clock (Ingresso da Master esterno)[cite: 1] |
| | `I2S1_LRCLK` | **GPIO47** | **Pin 57** | Frame Sync / WS (Ingresso da Master)[cite: 1] |
| | `I2S1_DATA` | **GPIO48** | **Pin 58** | Dati Audio 2[cite: 1] |
| **UART BT1035** | `BT_TX` | **GPIO52** | **Pin 62** | Collegare a **RXD** del modulo BT1035 |
| | `BT_RX` | **GPIO53** | **Pin 63** | Collegare a **TXD** del modulo BT1035 |
| | `BT_RTS` *(Opz.)* | **GPIO54** | **Pin 64** | Controllo di flusso (Collegare a **CTS** del BT1035) |
| | `BT_CTS` *(Opz.)* | **GPIO55** | **Pin 65** | Controllo di flusso (Collegare a **RTS** del BT1035) |
| **INTERRUPTS & IO** | `PCA_POWER_INT` | **GPIO11** | **Pin 17** | Interruzione da espansore I2C PCA9555 (Power Unit)[cite: 1] |
| | `SPARE_IO0` | **GPIO16** | **Pin 22** | GPIO libero / Riserva[cite: 1] |
| | `SPARE_IO1` | **GPIO17** | **Pin 23** | GPIO libero / Riserva[cite: 1] |
| **SYSTEM & BOOT** | `ESP_EN` | **EN** | **Pin 5** | Reset Hardware (Pull-up 10 kΩ + Cap 1 µF verso GND)[cite: 1] |
| | `ESP_BOOT` | **GPIO61** | **Pin 71** | Strapping Pin / Pulsante BOOT (Pull-up interno)[cite: 1] |
| | `USB_DP` | **USB_DP** | **Pin 40** | USB Data+ (Coppia differenziale 90 Ω)[cite: 1] |
| | `USB_DM` | **USB_DM** | **Pin 41** | USB Data- (Coppia differenziale 90 Ω)[cite: 1] |

---

## 2. Note di Progettazione Hardware

### USB Serial / JTAG Integrato
* Per programmazione e debug è sufficiente un singolo connettore **USB Type-C** direttamente collegato a `USB_DP` (Pin 40) e `USB_DM` (Pin 41)[cite: 1].
* Inserire **due resistenze da 5.1 kΩ** su CC1 e CC2 verso GND sul connettore Type-C.

### Bus SPI
* I dispositivi controllati in SPI sono 2: **Si4684** (`CS0` su `GPIO13`) e **ADAU1467** (`CS1` su `GPIO14`)[cite: 1].
* Aggiungere resistori di **pull-up esterni da 10 kΩ a 3.3V** sulle linee CS per garantire lo stato HIGH durante il boot.

### Bus I2C
* Il codec **TLV320AIC3104** (indirizzo `0x18`) è controllato via I2C (`GPIO50` per SDA e `GPIO51` per SCL).
* Prevedere due resistori di pull-up esterni da **2.2 kΩ a 4.7 kΩ** verso 3.3V.

### Interfacce I2S Audio
* Entrambi i canali I2S sono configurati in modalità **Slave**. I segnali di clock `BCLK` e `LRCLK` provengono dai rispettivi dispositivi Master esterni[cite: 1].

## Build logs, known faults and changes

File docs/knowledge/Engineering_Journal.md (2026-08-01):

# HubAudio Engineering Journal

Version: 1.0

Status: Living Document

---

# Purpose

This journal records the engineering journey behind HubAudio.

It is not a development log.

It is not a changelog.

It is a collection of engineering decisions, lessons learned,
mistakes avoided and design rationale.

The purpose is to preserve knowledge rather than events.

---

# Philosophy

The objective of HubAudio is not only to build an embedded audio platform.

The primary objective is to become a better engineer while building it.

Every challenge is considered an opportunity to understand a technology
rather than simply making it work.

The final PCB is one result.

The acquired engineering knowledge is the most valuable result.

---

# First Entry

Today we established that engineering methodology is part of the project.

Architecture, documentation, firmware and hardware shall evolve together.

Every future decision should increase the knowledge contained in this
repository.

HubAudio is not only an embedded platform.

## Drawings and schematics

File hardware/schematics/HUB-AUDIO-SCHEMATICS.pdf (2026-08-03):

GND A1B12 VBUS A4B9 SBU2 B8 CC1 A5 DN2 B7 DP1 A6 DN1 A7 DP2 B6 SBU1 A8 CC2 B5 VBUS B4A9 GND B1A12

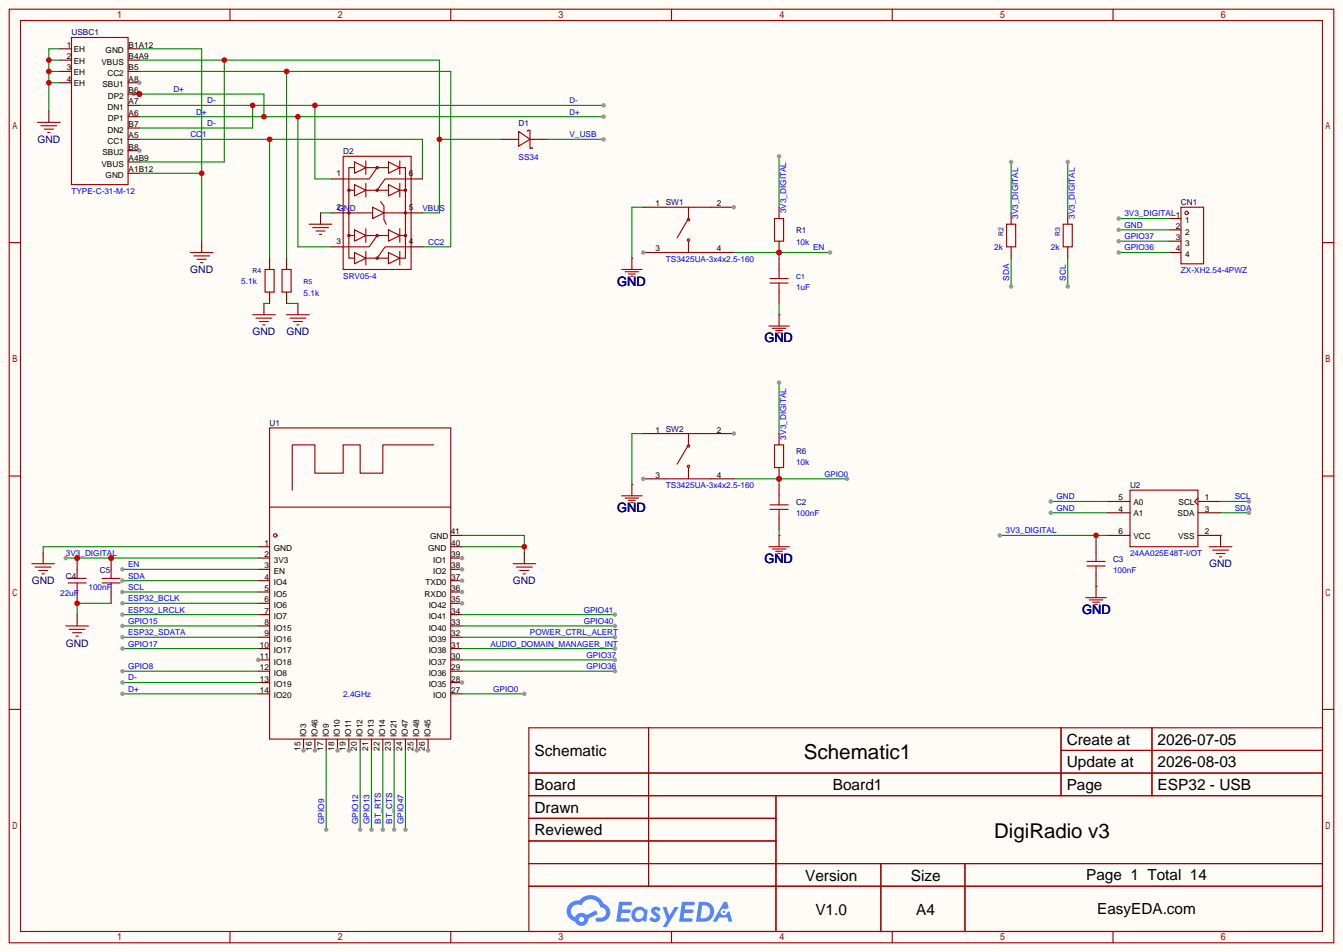
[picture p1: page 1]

Schematic | Schematic1 | Create at | 2026-07-05

Update at | 2026-08-03

Board | Board1 | Page | ESP32 - USB
Drawn | | DigiRadio v3
Reviewed

Version | Size | Page 1 Total 14
V1.0 | A4 | EasyEDA.com

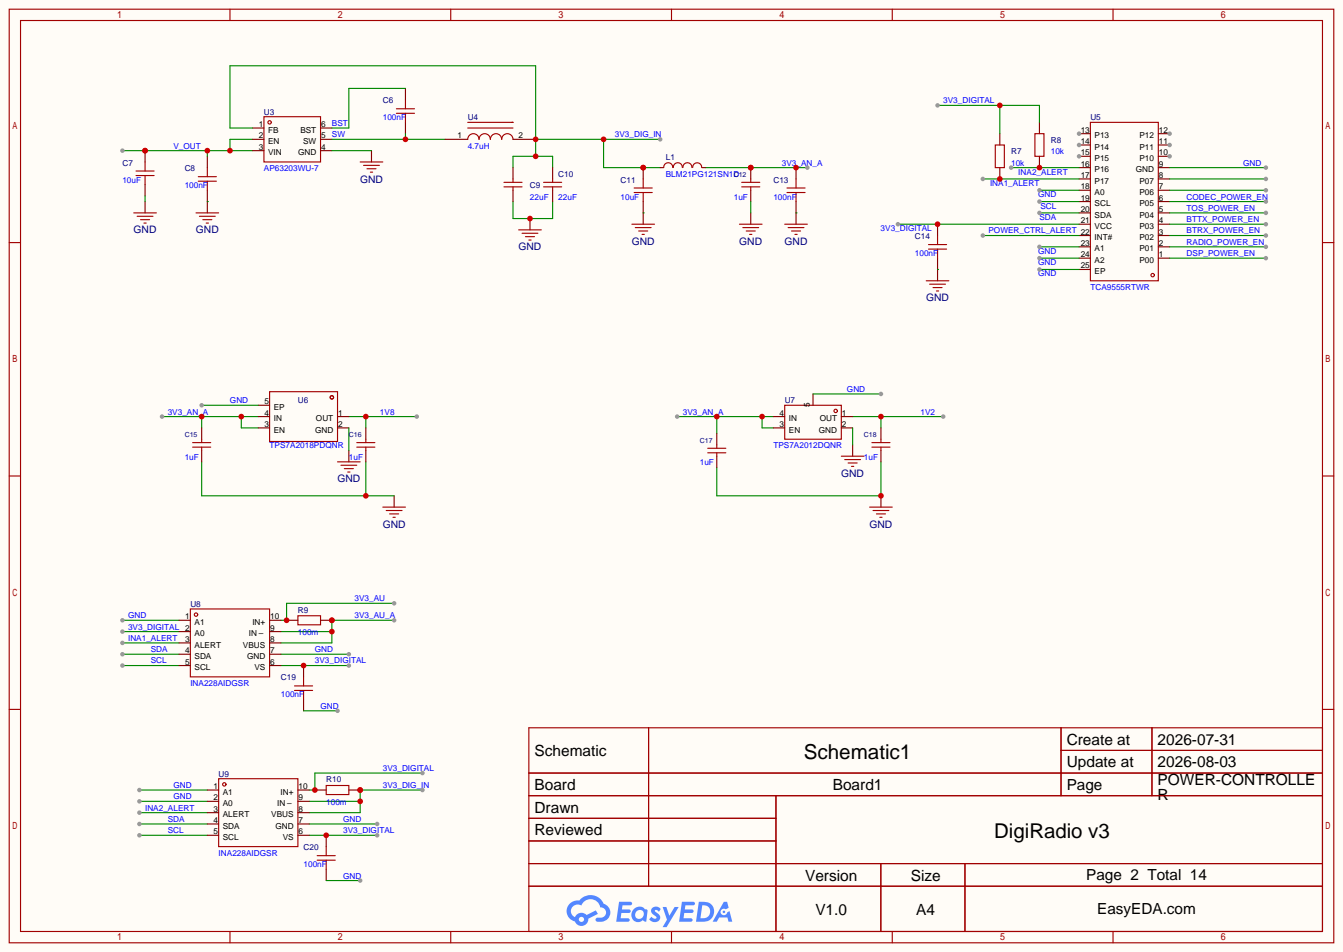
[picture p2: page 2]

Schematic | Schematic1 | Create at | 2026-07-31

Update at | 2026-08-03

Board | Board1 | Page | POWER-CONTROLLE
Drawn | | DigiRadio v3
Reviewed

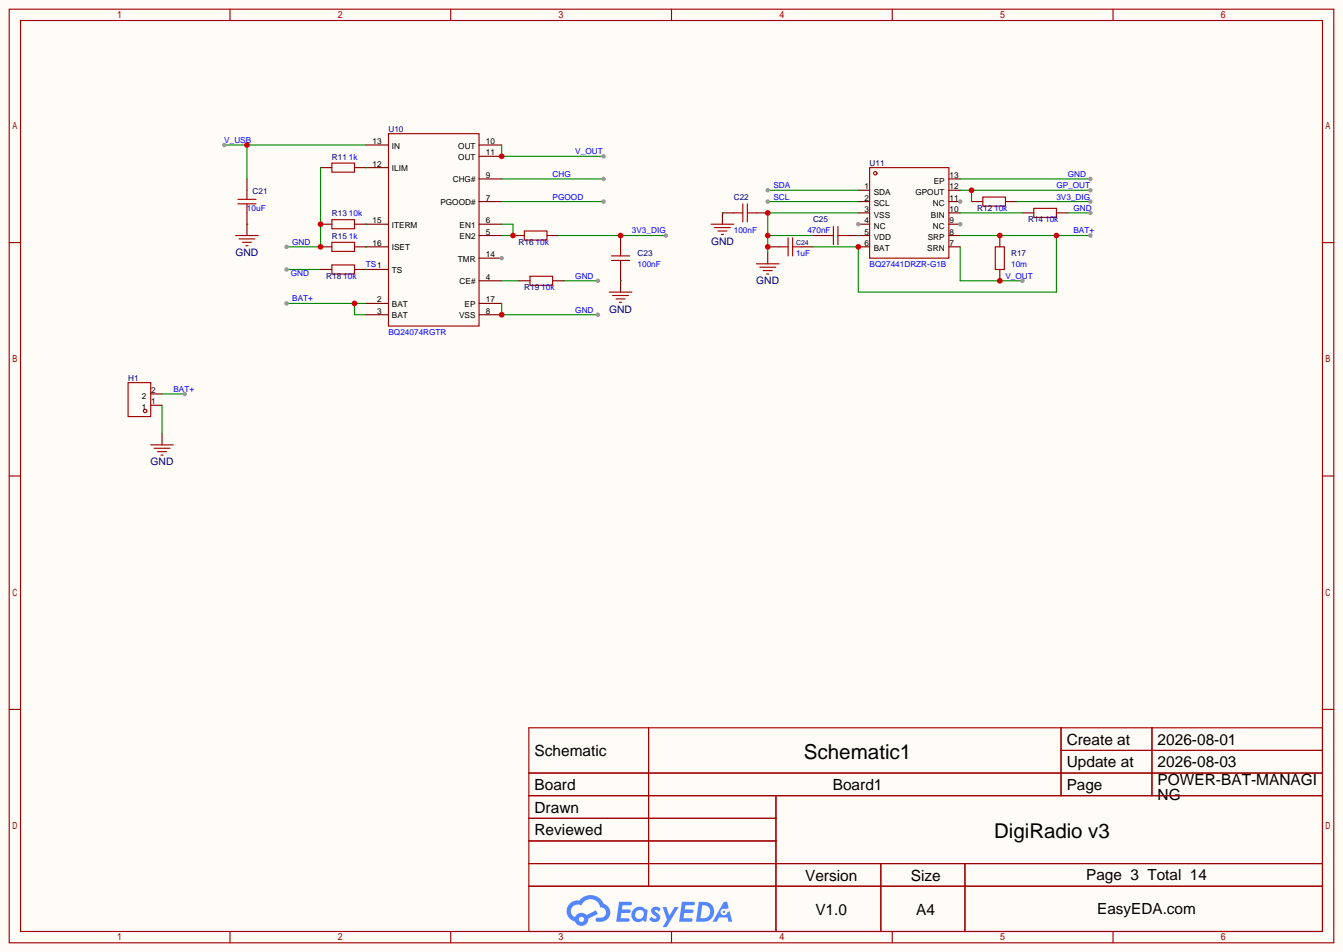
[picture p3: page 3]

BIN 10 NC 11 GPOUT 12 EP 13

Schematic | Schematic1 | Create at | 2026-08-01

Update at | 2026-08-03

Board | Board1 | Page | POWER-BAT-MANAGI
Drawn | | DigiRadio v3
Reviewed

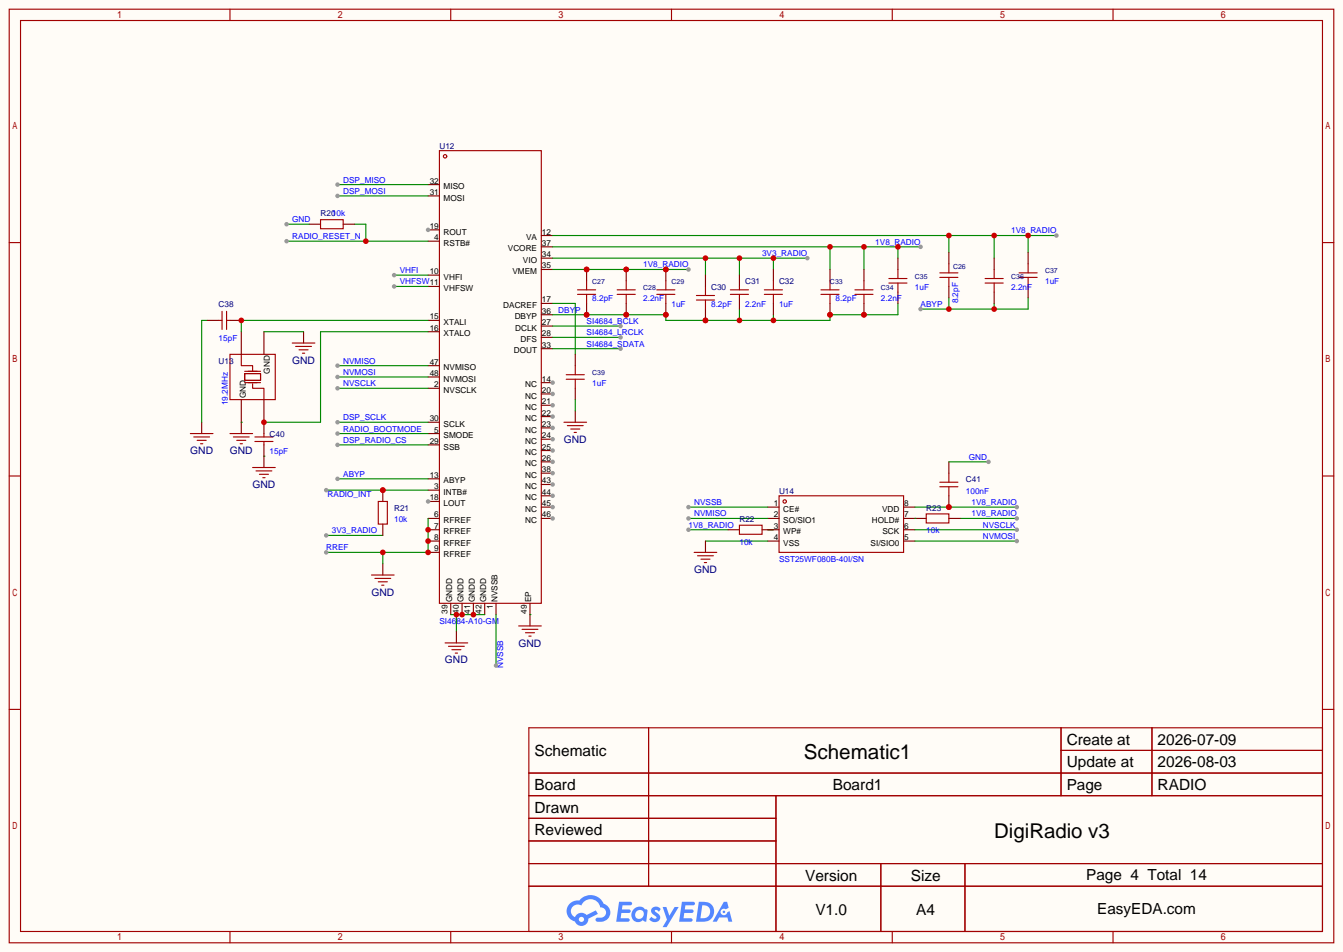
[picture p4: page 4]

VMEM 35 VIO 34 VCORE 37 VA 12

DOUT 33 DFS 28 DCLK 27 DBYP 36 DACREF 17

DBYP
SI4684_BCLK
SI4684_LRCLK
SI4684_SDATA

Schematic | Schematic1 | Create at | 2026-07-09

Update at | 2026-08-03

Board | Board1 | Page | RADIO
Drawn | | DigiRadio v3
Reviewed

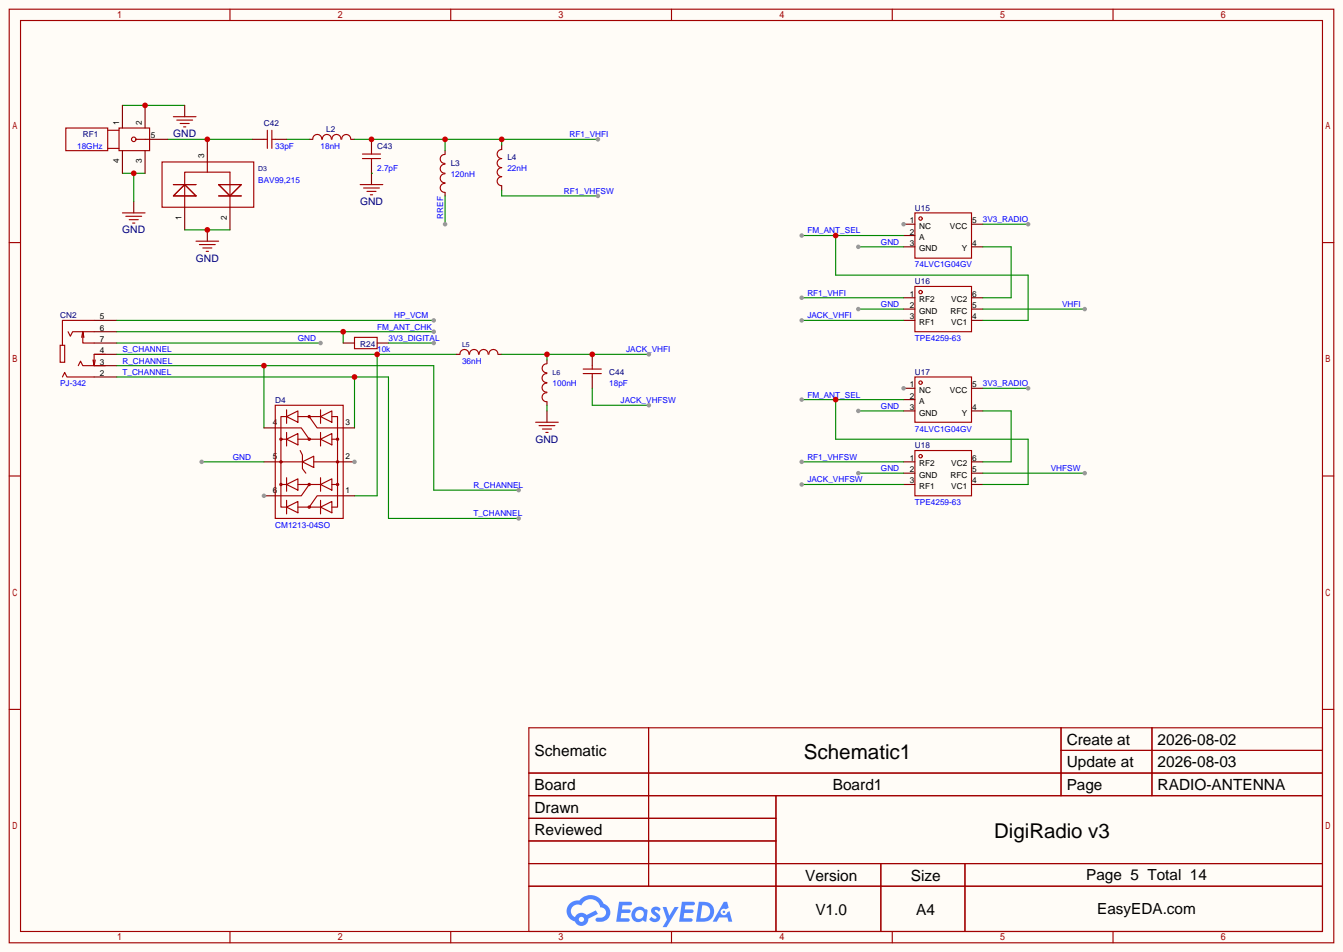
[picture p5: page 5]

Schematic | Schematic1 | Create at | 2026-08-02

Update at | 2026-08-03

Board | Board1 | Page | RADIO-ANTENNA
Drawn | | DigiRadio v3
Reviewed

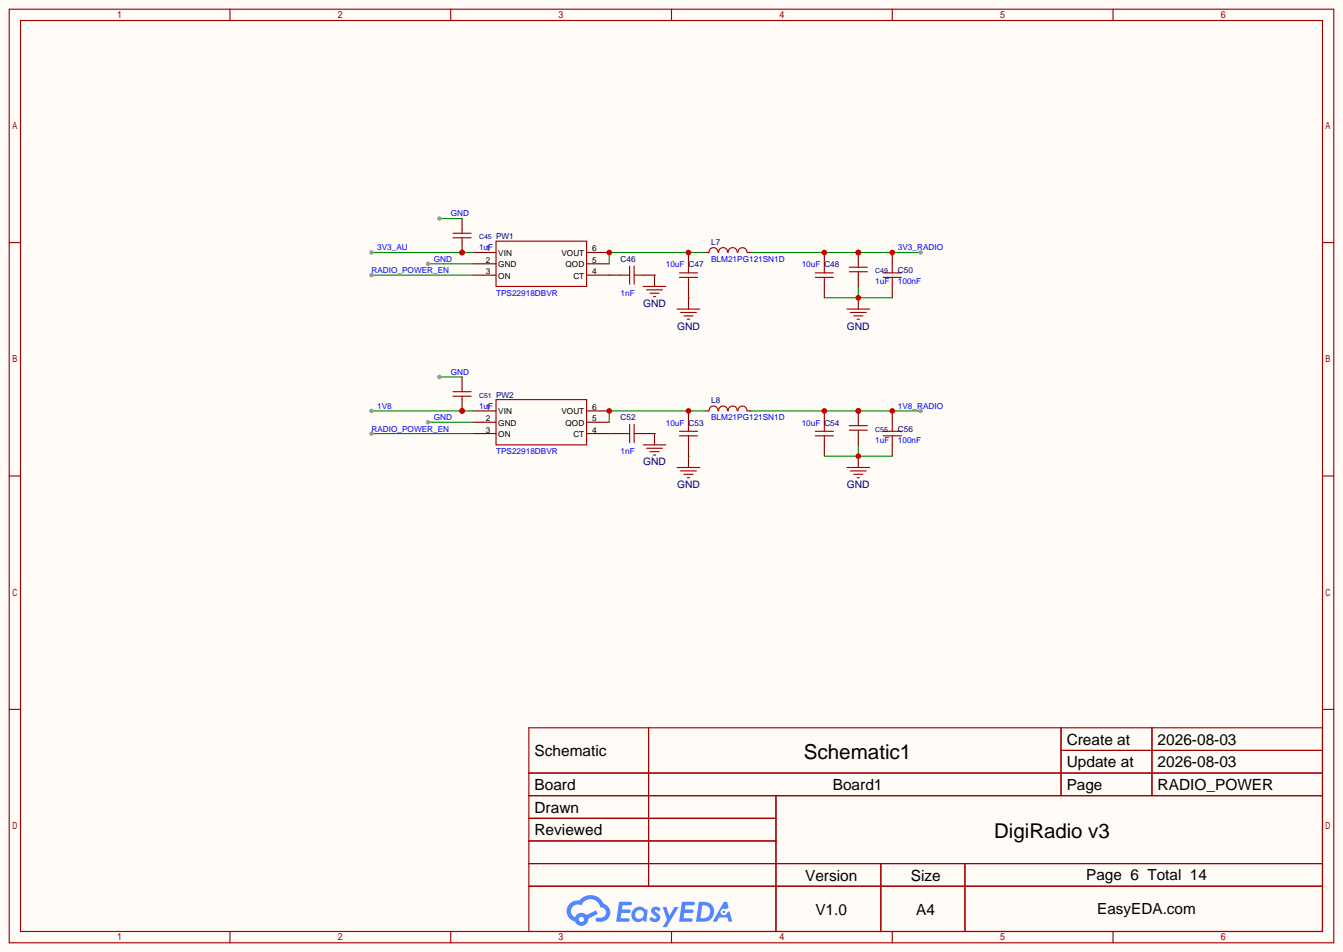
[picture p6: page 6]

Schematic | Schematic1 | Create at | 2026-08-03

Update at | 2026-08-03

Board | Board1 | Page | RADIO_POWER
Drawn | | DigiRadio v3
Reviewed

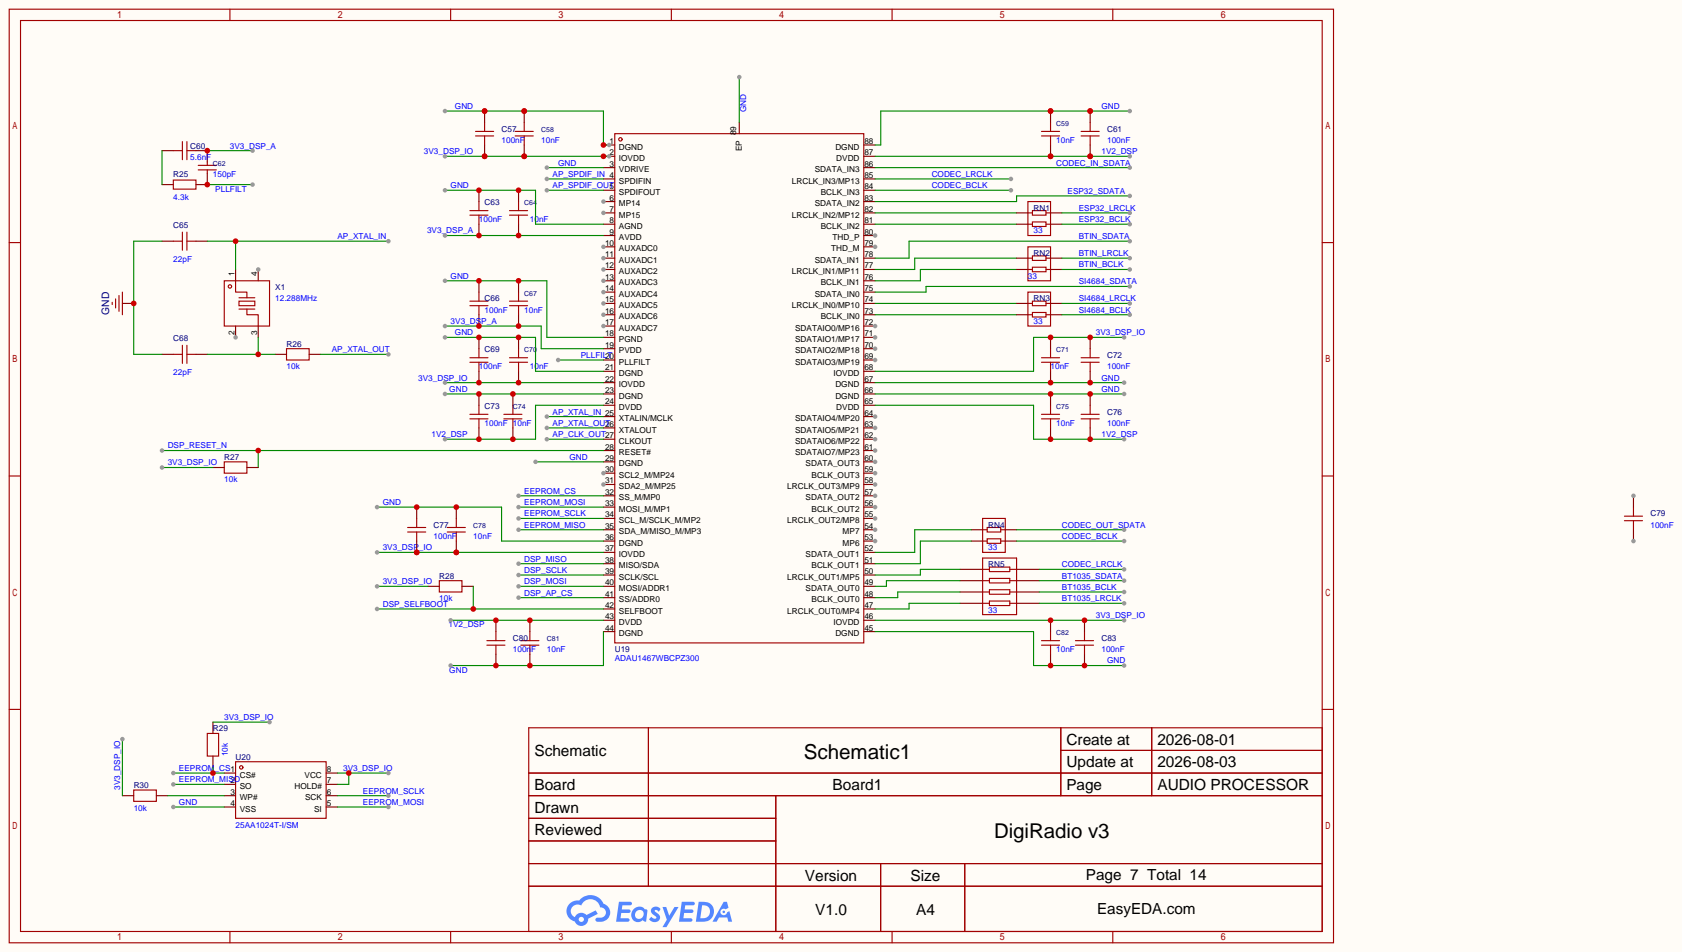
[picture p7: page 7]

Schematic | Schematic1 | Create at | 2026-08-01

Update at | 2026-08-03

Board | Board1 | Page | AUDIO PROCESSOR
Drawn | | DigiRadio v3
Reviewed

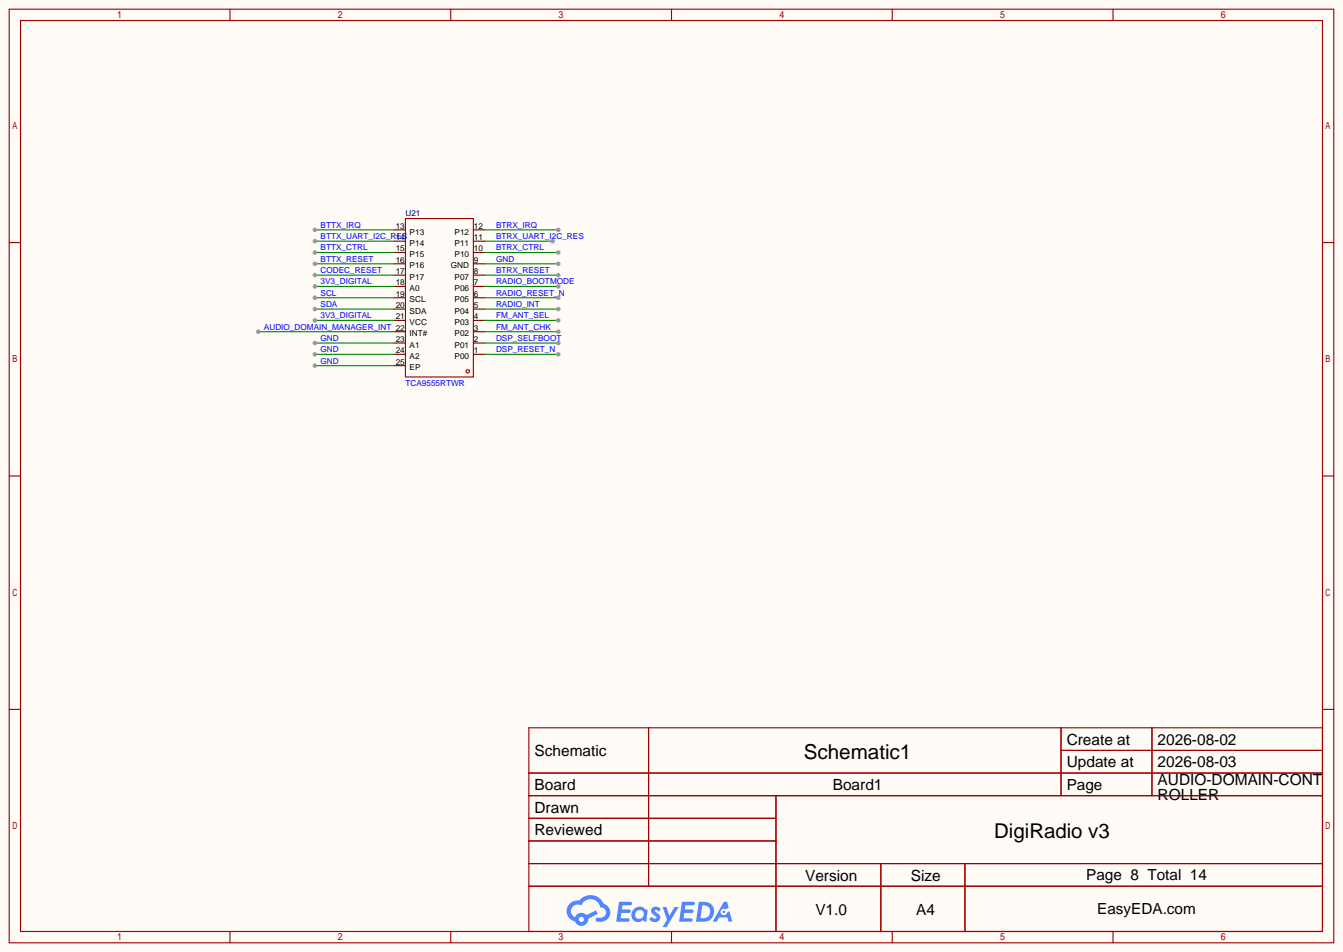
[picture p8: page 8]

Schematic | Schematic1 | Create at | 2026-08-02

Update at | 2026-08-03

Board | Board1 | Page | AUDIO-DOMAIN-CONT
Drawn | | DigiRadio v3
Reviewed

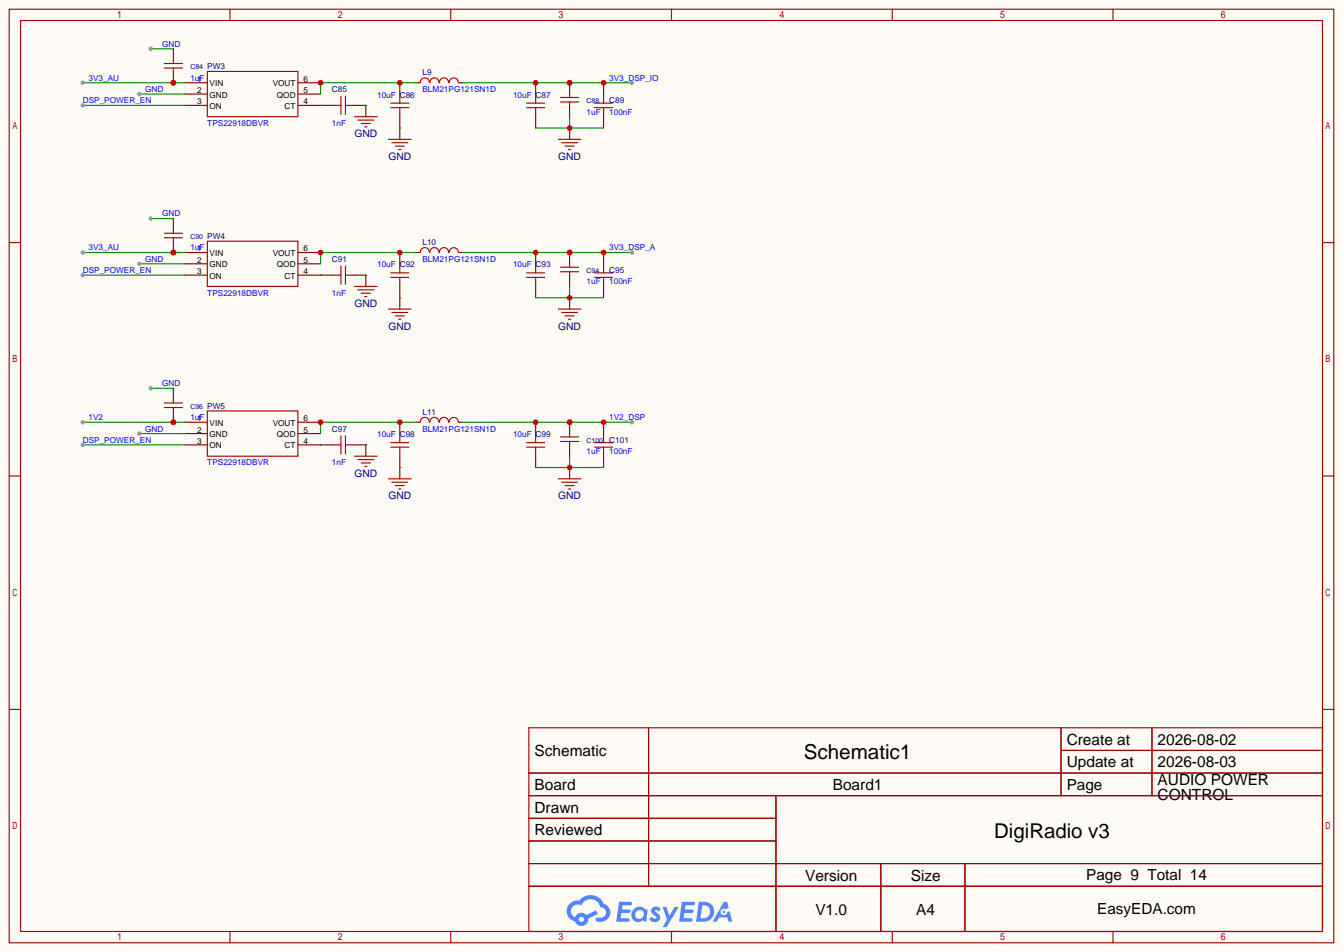
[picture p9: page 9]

Schematic | Schematic1 | Create at | 2026-08-02

Update at | 2026-08-03

Board | Board1 | Page | AUDIO POWER
Drawn | | DigiRadio v3
Reviewed

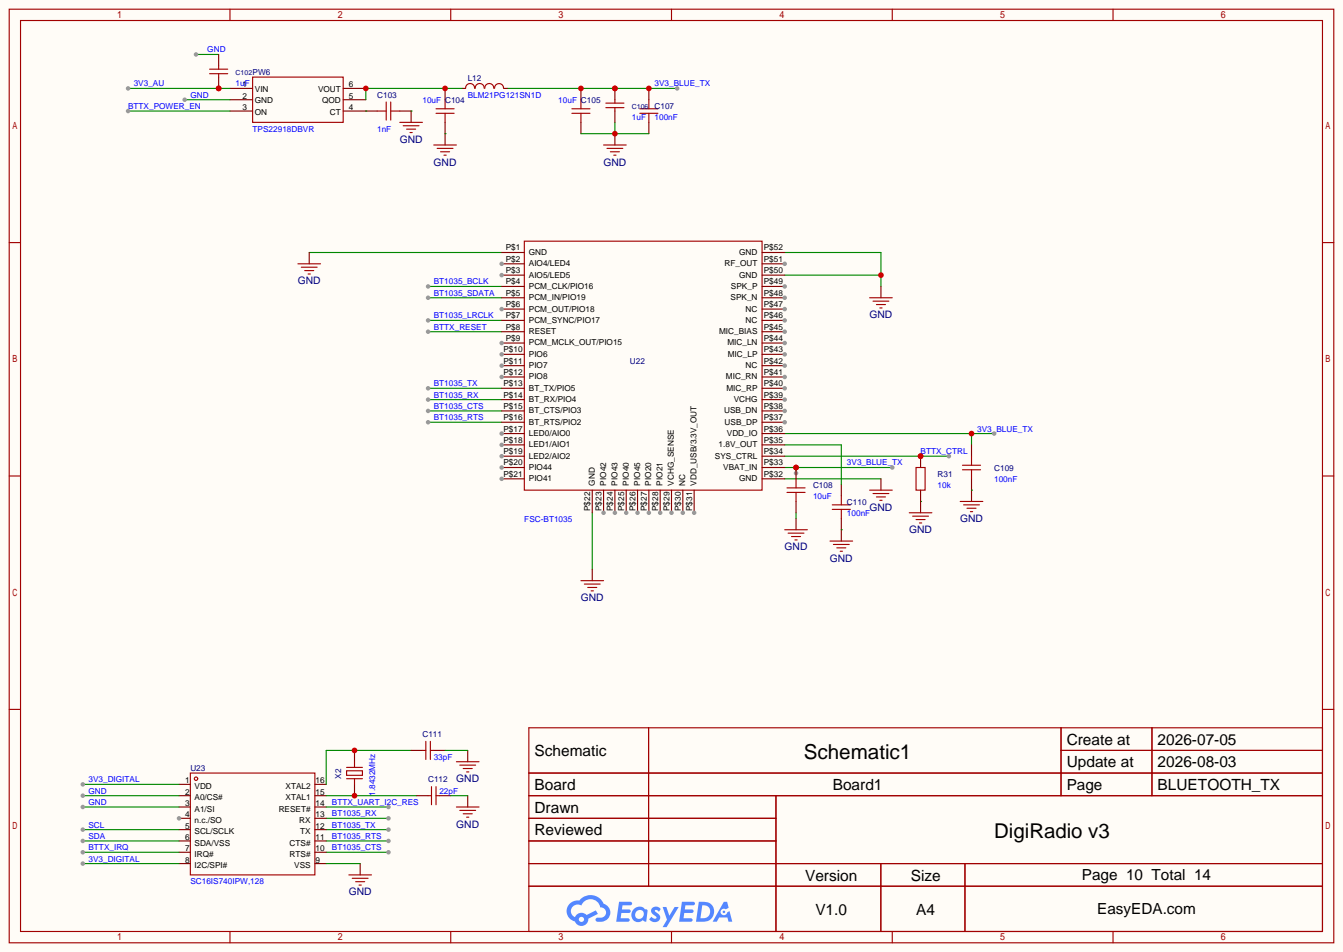
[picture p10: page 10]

Schematic | Schematic1 | Create at | 2026-07-05

Update at | 2026-08-03

RTS# 10 CTS# 11 TX 12 RX 13 RESET# 14 XTAL1 15 XTAL2 16

Board | Board1 | Page | BLUETOOTH_TX
Drawn | | DigiRadio v3
Reviewed

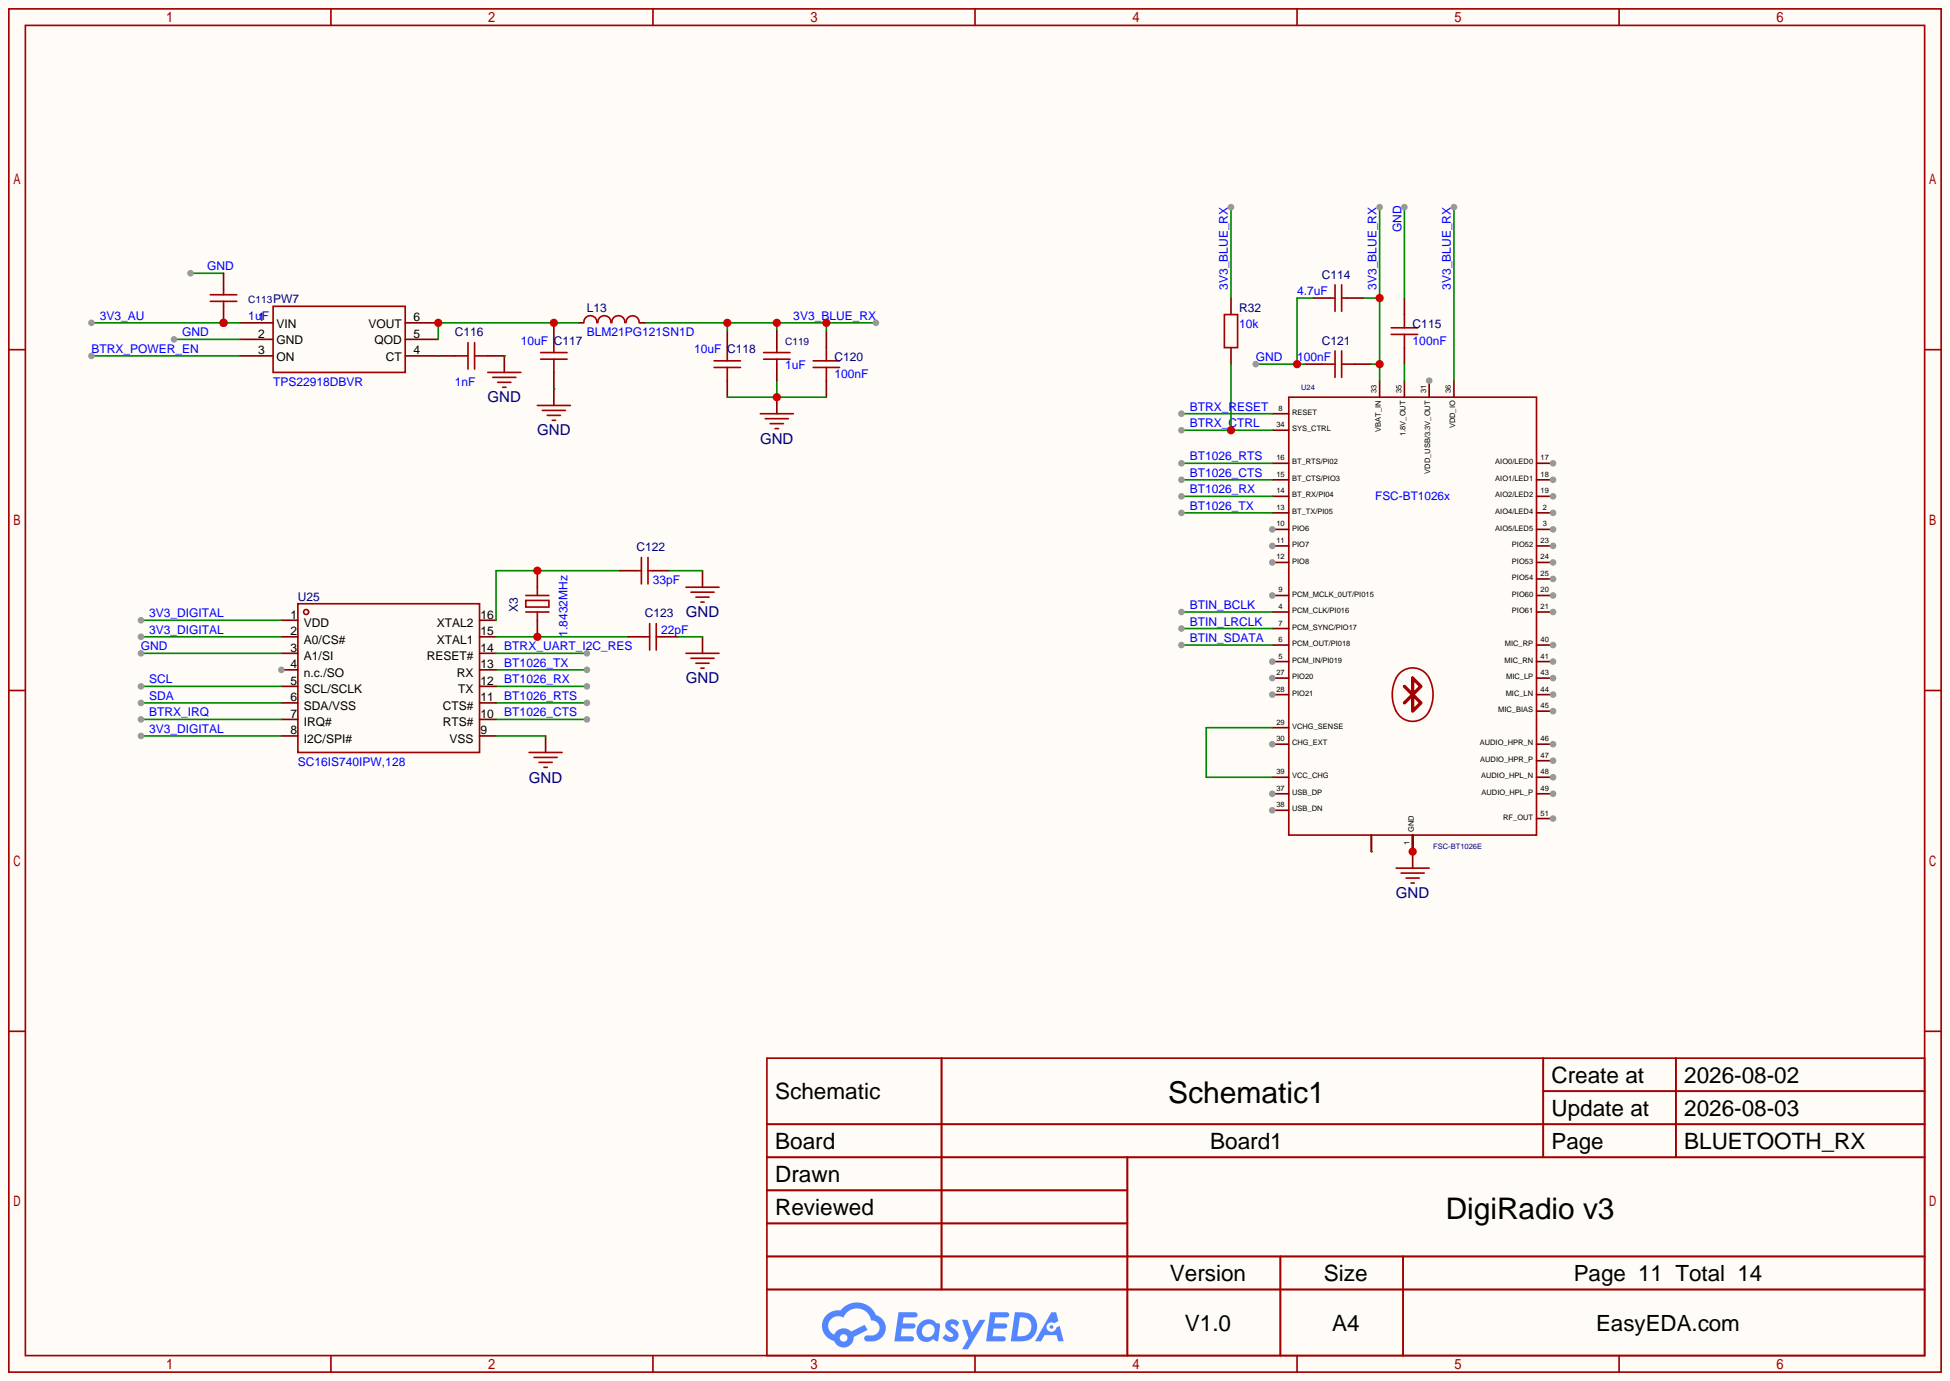
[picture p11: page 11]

RTS# 10 CTS# 11 TX 12 RX 13 RESET# 14 XTAL1 15 XTAL2 16

Schematic | Schematic1 | Create at | 2026-08-02

Update at | 2026-08-03

Board | Board1 | Page | BLUETOOTH_RX
Drawn | | DigiRadio v3
Reviewed

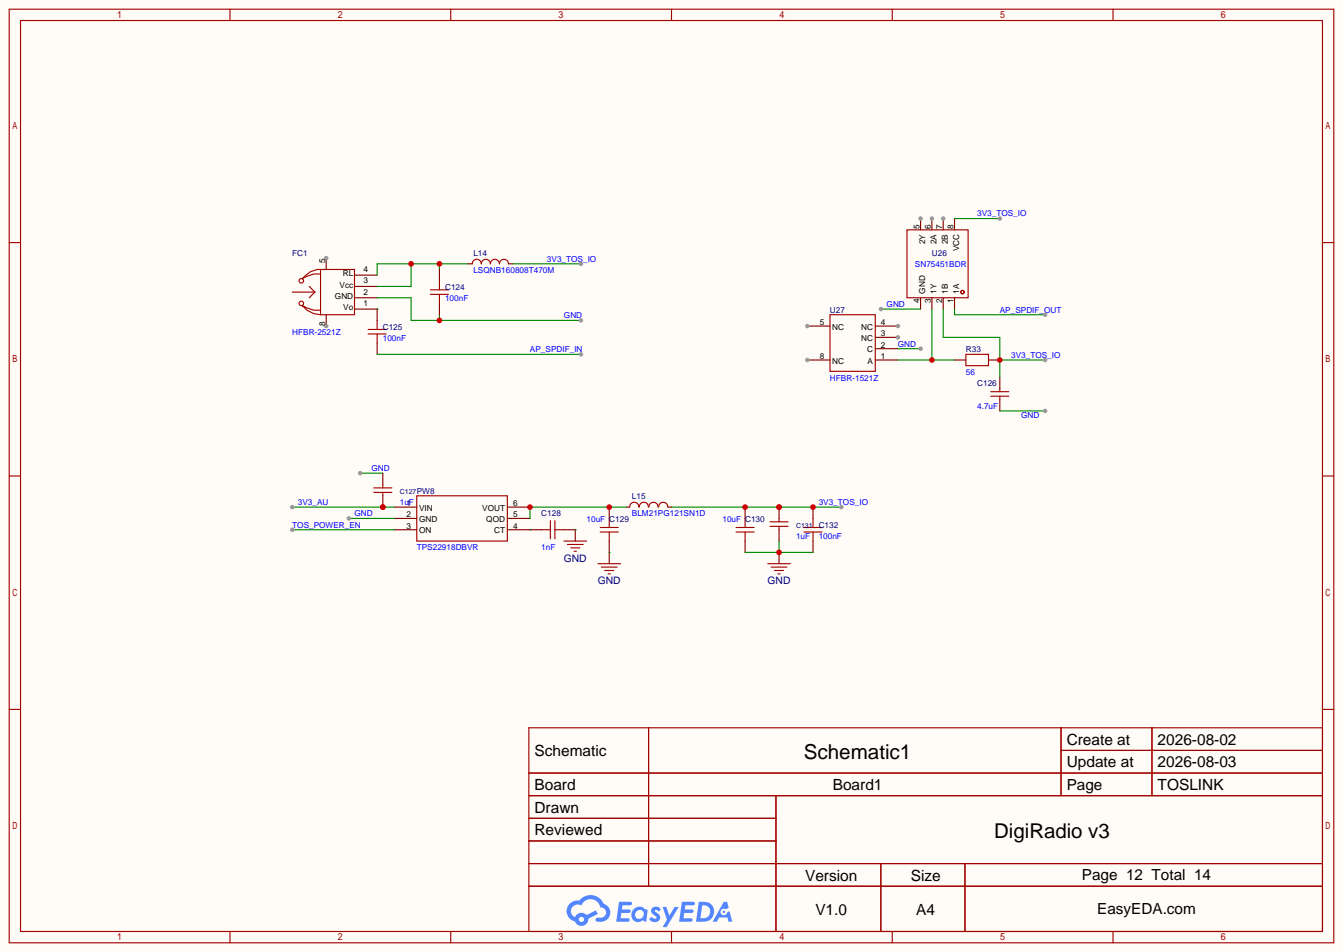
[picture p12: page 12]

Schematic | Schematic1 | Create at | 2026-08-02

Update at | 2026-08-03

Board | Board1 | Page | TOSLINK
Drawn | | DigiRadio v3
Reviewed


Schematic | Schematic1 | Create at | 2026-08-03

Update at | 2026-08-03

Board | Board1 | Page | CODEC
Drawn | | DigiRadio v3
Reviewed


Schematic | Schematic1 | Create at | 2026-08-03

Update at | 2026-08-03

Board | Board1 | Page | CODEC_POWER_CO
Drawn | | DigiRadio v3
Reviewed

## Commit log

2026-08-01 aggiornamento di alcuni file e revisione directory repository 202608012135
2026-08-01 docs: aggiornati ADR 002 e 003 per SPI e audio routing
2026-08-03 schema completato
    [HUB-AUDIO-BOM.xlsx]
2026-08-03 bom added
    [BOM_Board1_PCB1_2026-08-03.xlsx]
2026-08-03 schematics and netlist added
    [HUB-AUDIO-BOM.xlsx]
2026-08-14 Add HubAudio KiCad project
    [HubAudio.kicad_pcb, HubAudio.kicad_sch]
2026-08-20 Update HubAudio hardware, schematics and architecture
    [BT-Unit.kicad_sch, Codec.kicad_sch, HubAudio.kicad_pcb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]
2026-08-22 Finalize I2C and SPI control architecture
    [BT-Unit.kicad_sch, Codec.kicad_sch, HubAudio.kicad_sch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]
2026-08-24 Finalize HubAudio hardware architecture and PCB
    [BT-Unit.kicad_sch, Codec.kicad_sch, HubAudio.kicad_pcb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]
2026-08-25 Update PCB power placement
    [HubAudio.kicad_pcb, POWER.kicad_sch]
2026-08-25 Power placemente (bottom layer) ... in progress
    [HubAudio.kicad_pcb, POWER.kicad_sch]
